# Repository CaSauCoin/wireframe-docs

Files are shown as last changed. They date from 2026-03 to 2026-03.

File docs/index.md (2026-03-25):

---
hide:
  - navigation
  - toc
---

<div class="wf-hero" markdown>

<span class="wf-badge">v1.3.7 — Stable Release</span>

# WireFrame EDA

<p class="wf-subtitle">
A lightweight, keyboard-driven EDA environment for schematic capture, PCB layout,<br>
3D visualization and manufacturing export — all in one desktop application.
</p>

<div class="wf-cta">
  <a href="getting-started/" class="primary">Get Started</a>
  <a href="tutorial/" class="secondary">Try the Tutorial →</a>
</div>

</div>

<!-- TODO: Replace with actual screenshot
     Capture the WireFrame main window immediately after launch. The screenshot should show:
     - _The **dark-themed window** with the menu bar at the top (File, Edit, View, Project, Tools, Help)._
     - _The **Project Structure** panel on the left side (empty or with a sample project open)._
     - _The **central editor area** showing either an empty docking space or a sample schematic/PCB tab._
     - _The **Library panel** on the right side._
     - _The cyan accent color visible on active UI elements._
     - _Window size: approximately 1920×1080 for best readability._
-->
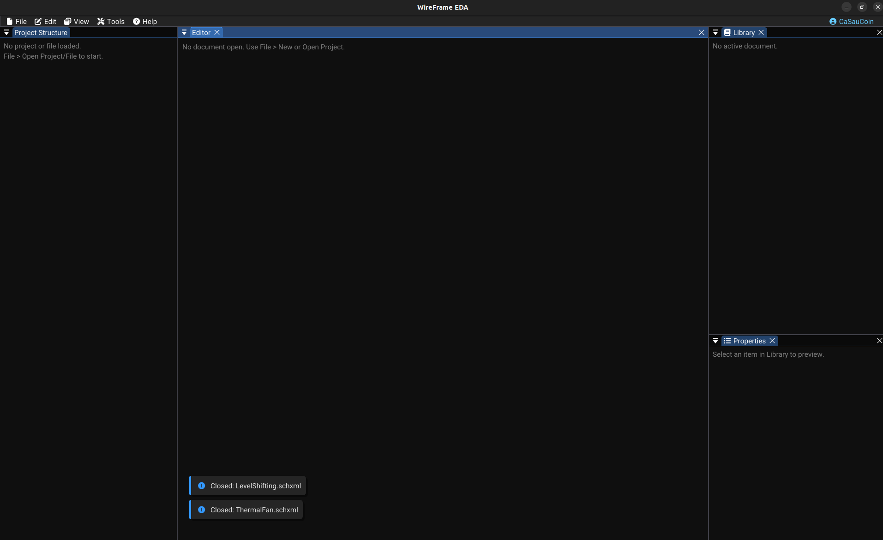
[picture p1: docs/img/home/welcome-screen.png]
Welcome Screen


---

## Key Features

<div class="wf-grid" markdown>

<div class="wf-card" markdown>

### :material-chip: Schematic Editor

Design circuits with a full-featured schematic editor — place symbols from KiCad-compatible libraries, wire nets, add labels and power symbols, and manage multi-sheet designs.

</div>

<div class="wf-card" markdown>

### :material-developer-board: PCB Layout

Route traces with 45° guidance, place vias and zones, manage multi-layer stacks, and run DFM/DRC checks before exporting Gerber files for fabrication.

</div>

<div class="wf-card" markdown>

### :material-library-shelves: Library Management

Load KiCad symbol (`.kicad_sym`) and footprint (`.kicad_mod`) libraries. Link footprints to symbols, generate custom footprints with the built-in wizard.

</div>

<div class="wf-card" markdown>

### :material-rotate-3d: 3D Viewer

Preview your PCB in 3D with imported STEP/OBJ models. Orbit, pan and zoom to verify component placement, clearances and board aesthetics before manufacturing.

</div>

<div class="wf-card" markdown>

### :material-keyboard: Keyboard-Driven

Fully customizable key map for every action — from placing wires to running DRC. Built for speed with an ImGui docking interface that keeps everything one keystroke away.

</div>

<div class="wf-card" markdown>

### :material-export: Fabrication Export

Export production-ready Gerber files, Excellon drill data, BOM spreadsheets and schematic PDFs. Verify outputs instantly with the built-in Gerber viewer.

</div>

<div class="wf-card" markdown>

### :material-swap-horizontal: Import & Compatibility

Import projects from KiCad, Altium Designer, and Eagle. Load symbol and footprint libraries from all major EDA formats — no manual conversion needed.

</div>

</div>

---

## Typical Workflow

```
┌───────────┐   ┌───────────┐   ┌────────────┐   ┌────────────┐   ┌──────────┐
│  Create    │──▶│  Design   │──▶│  Convert   │──▶│  Route &   │──▶│  Export   │
│  Project   │   │  Schematic│   │  to PCB    │   │  Verify    │   │  Gerbers  │
└───────────┘   └───────────┘   └────────────┘   └────────────┘   └──────────┘
```

1. **Create or open a project** — Organize schematics, PCBs and libraries under a single `.prjxml` project file.
2. **Design the schematic** — Place components, wire nets, add power symbols and labels, configure sheet properties.
3. **Convert to PCB** — Generate a PCB document from the schematic with footprints and netlist automatically linked.
4. **Route and verify** — Place footprints, route traces, add zones, then run DFM/DRC checks to catch errors.
5. **Export for fabrication** — Generate Gerber/drill files, export BOM and schematic PDFs, and preview in the Gerber viewer.

---

## Who Is This For?

| Audience | Why WireFrame? |
|---|---|
| **Electronics hobbyists** | Simple, focused tool — no bloated menus. Start designing in minutes. |
| **Students & educators** | Lightweight install, clear workflow from schematic to Gerber. |
| **Professional engineers** | Keyboard-driven speed, KiCad library compatibility, batch export. |
| **Open-source contributors** | C++17 codebase with ImGui — easy to extend and hack on. |

---

## Documentation Map

| Section | What You'll Learn |
|---|---|
| [Getting Started](getting-started.md) | Launch the app, understand the UI, create your first project |
| [Tutorial](tutorial/index.md) | Build a simple LED circuit from scratch in 15 minutes |
| [Schematic Design](schematic/index.md) | Place components, wire nets, manage properties |
| [PCB Layout](pcb/index.md) | Footprints, routing, zones, DRC and fabrication export |
| [Libraries](libraries/symbols-library.md) | Load, create and manage symbols and footprints |
| [Advanced Features](advanced/selection-and-editing.md) | Selection, 3D viewer, keyboard shortcuts |
| [Reference](reference/file-formats.md) | File formats, config, FAQ, changelog |

---

!!! tip "New to WireFrame?"
    Start with the [Getting Started](getting-started.md) guide for a quick orientation, or jump straight into the [Tutorial](tutorial/index.md) to design a simple LED circuit from scratch.

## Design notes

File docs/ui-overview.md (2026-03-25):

# User Interface Overview

This page provides a detailed tour of every part of the WireFrame UI. Understanding the layout will help you work efficiently as you design schematics and PCBs.
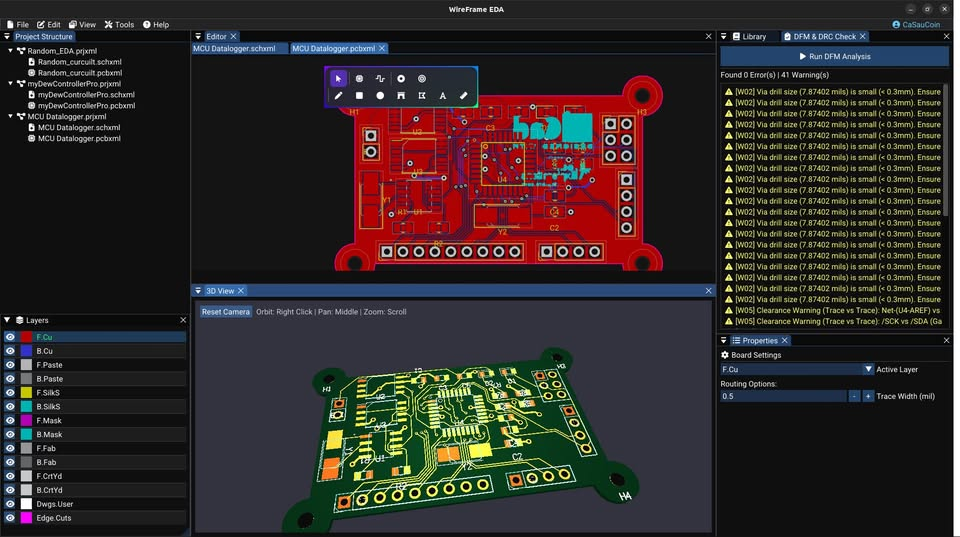
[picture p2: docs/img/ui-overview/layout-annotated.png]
WireFrame UI layout annotated


---

## Menu Bar

Located at the top of the window. Provides access to all major operations:

### File menu

| Action | Shortcut | Description |
|---|---|---|
| New Project… | | Create a new `.prjxml` project |
| Open Project… | | Open an existing project |
| Open… | ++ctrl+o++ | Open a schematic or PCB file |
| New Schematic | ++ctrl+n++ | Create a new schematic document |
| New PCB | | Create a new PCB document |
| Save | ++ctrl+s++ | Save the active document |
| Save As… | ++ctrl+shift+s++ | Save with a new filename |
| Close Project | | Close the active project |
| Export → | | Sub-menu for PDF, Gerber, BOM export |

### Edit menu

| Action | Shortcut | Description |
|---|---|---|
| Undo | ++ctrl+z++ | Undo last action |
| Redo | ++ctrl+y++ | Redo last undone action |
| Cut | ++ctrl+x++ | Cut selected items to clipboard |
| Copy | ++ctrl+c++ | Copy selected items |
| Paste | ++ctrl+v++ | Paste from clipboard |
| Delete | ++delete++ | Delete selected items |

### View menu

| Action | Description |
|---|---|
| Toggle Library | Show/hide the Library panel |
| Toggle Layers | Show/hide the Layer panel (PCB) |
| Toggle Properties | Show/hide the Properties panel |
| 3D Viewer… | Open the 3D PCB viewer |
| Fit to Screen | Zoom to fit all content |

### Tools menu

| Action | Description |
|---|---|
| Symbol Editor | Open the symbol library editor |
| Footprint Wizard | Open the footprint generator |
| Design Rules | Open design rules configuration |
| DFM Check | Run DFM/DRC checks on the active PCB |
| Gerber Viewer | Open the built-in Gerber file viewer |
| Keymap… | Open the keyboard shortcut editor |

### Help menu

| Action | Description |
|---|---|
| About | Show version and license information |
| Check for Updates | Check for newer versions (if enabled) |

---

## Docking Layout

WireFrame uses **docking layout**, giving you full control over panel arrangement:

- **Drag tabs** to move panels between docking zones (left, right, bottom, center).
- **Float panels** by dragging them outside the docking area — they become independent windows.
- **Split zones** by dropping a panel on the edge of an existing zone.
- **Layout persistence**: your arrangement is saved automatically via ImGui configuration and restored on next launch.

Common default panels:

| Panel | Default position |
|---|---|
| Project Structure | Left |
| Editor (canvas) | Center |
| Library | Right (top) |
| Properties | Right (bottom) |
| Layers (PCB only) | Right (middle) |
| Logger / Notifications | Overlay (bottom-right) |

---

## Project Structure Panel

Shows all open projects and their contents in a tree view:

- **Project node** (`.prjxml`) — the root.
    - **Schematics** — lists all `.schxml` files registered in the project.
    - **PCBs** — lists all `.pcbxml` files registered in the project.

### Interactions

| Action | How |
|---|---|
| Open a document | Click a schematic or PCB entry |
| Add new schematic/PCB | Right-click project → Add New… |
| Rename a file | Right-click → Rename |
| Remove from project | Right-click → Remove |
| Delete from disk | Right-click → Delete (with confirmation) |

!!! info "Standalone mode"
    You can open schematic/PCB files without a project. They appear as standalone tabs in the editor but are not linked to a project tree.

<!-- TODO: Replace with actual screenshot
     Capture the Project Structure panel showing:
     - One project ("SampleBoard.prjxml") expanded
     - Under "Schematics": two files (main.schxml, power.schxml)
     - Under "PCBs": one file (SampleBoard.pcbxml)
     - One file highlighted (currently open)
     - A right-click context menu visible (Add New, Remove, Delete)
     Crop to the panel only. 300×500px.
-->
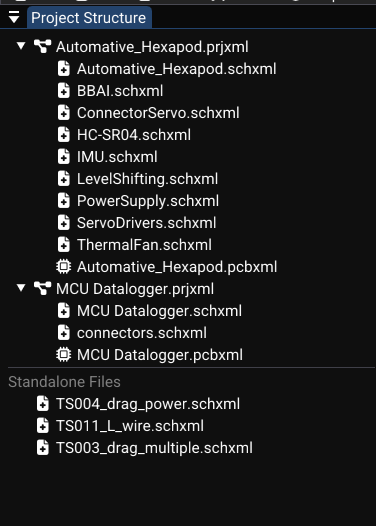
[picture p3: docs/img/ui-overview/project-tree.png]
Project Structure panel


See [Projects & Files](projects.md) for more details.

---

## Editor Panel

The central area where you design. It holds:

- **One tab per open document** (schematic or PCB).
- Tab shows the **filename** (or "Untitled-SCH-N" / "Untitled-PCB-N" for new documents).
- A **dot** or **asterisk** next to the name indicates unsaved changes.
- Right-click a tab to **Close**, **Close Others**, or **Close All**.

### Canvas behavior (common to schematic and PCB)

| Feature | Description |
|---|---|
| Grid | Dot grid for alignment; grid spacing depends on zoom level |
| Pan | Hold middle mouse button and drag |
| Zoom | Mouse scroll wheel, centered on cursor |
| Fit to screen | Press ++f++ (default) to fit all content in view |
| Zoom to selection | Press ++shift+f++ to zoom to selected items |

### Schematic canvas

Displays a page outline (A4/A3/custom), title block border, and all placed components, wires and graphics.

### PCB canvas

Displays the board area, placed footprints, traces, vias, zones and ratsnest lines.

---

## Library Panel

Context-sensitive — content changes based on the active document type:

### When a schematic is active

- Shows loaded **symbol libraries** and their symbols.
- **Search filter** at the top for quick lookup (type partial name like `STM32` or `R_`).
- **Double-click** a symbol to start placing it on the schematic canvas.
- **Right-click** for options: Unload Library, Reload, Link Footprint.

<!-- TODO: Replace with actual screenshot
     Capture the Library panel in schematic context:
     - Search box at the top with "res" typed
     - Filtered list: "R", "R_0402", "R_0603", "R_1206"
     - Status bar: "Ready — 150 symbols"
     - One symbol highlighted
     Crop to panel only. 280×400px.
-->
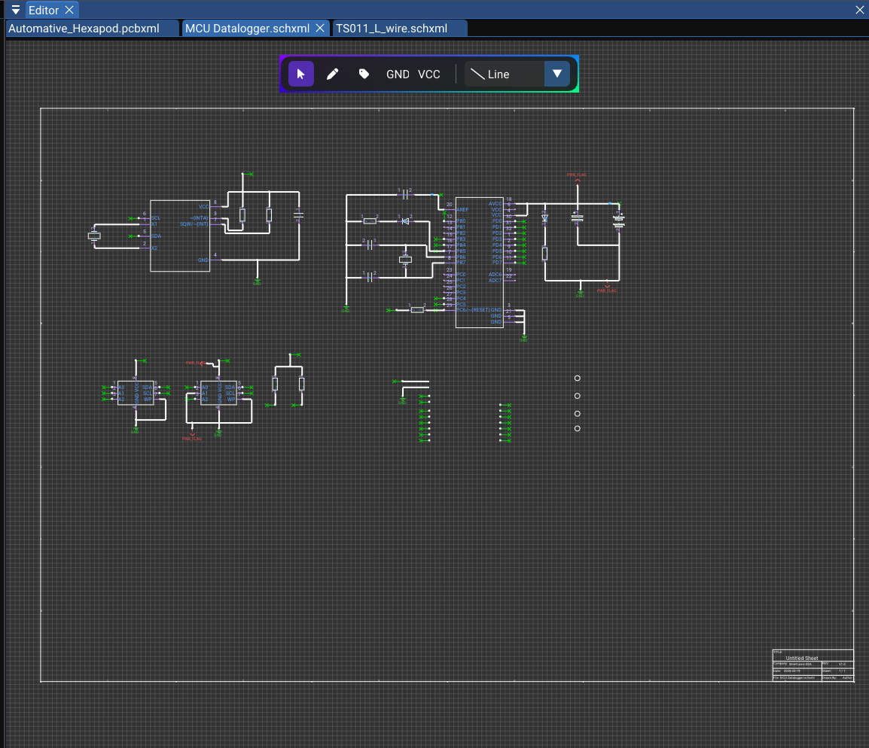
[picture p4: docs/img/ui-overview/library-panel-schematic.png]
Library panel — schematic symbols


### When a PCB is active

- Shows loaded **footprint libraries** and their footprints.
- Same **search filter** functionality.
- **Double-click** to place a footprint on the PCB, or to assign to a selected component.
- **Right-click** for options: Unload, Reload, Open in Footprint Wizard.

<!-- TODO: Replace with actual screenshot
     Same as above but showing footprint names (SOT-23, QFP-48, R_0603_1608Metric).
     PCB editor visible in background. 280×400px.
-->
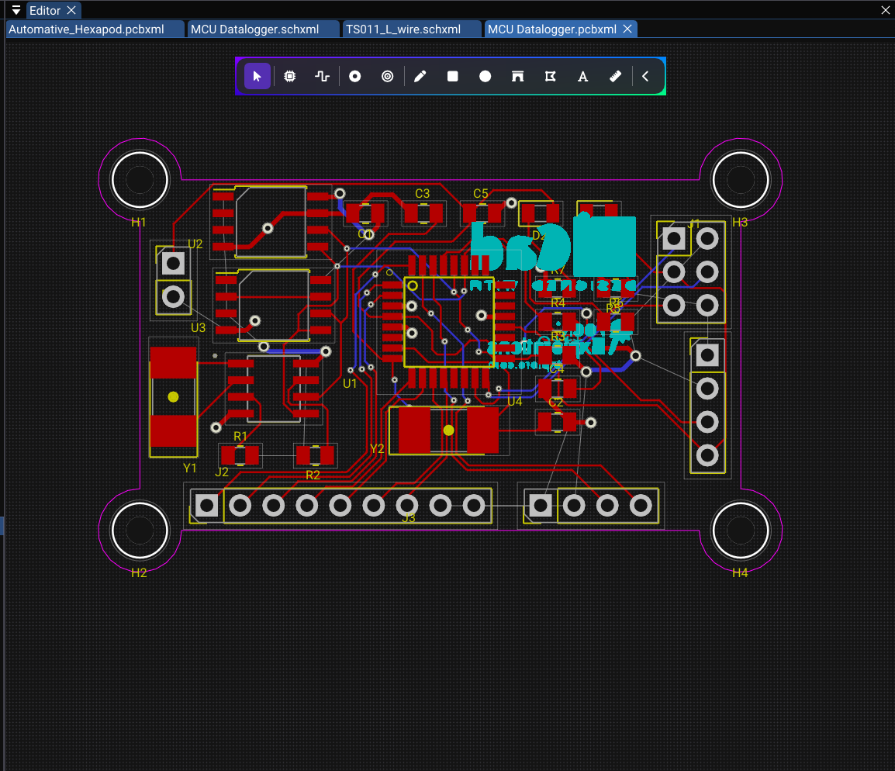
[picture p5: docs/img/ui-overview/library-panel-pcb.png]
Library panel — PCB footprints


---

## Properties Panel

Displays editable information about the current selection and active document:

### Schematic properties

| Selection | Properties shown |
|---|---|
| Single component | Designator, Value, Comment, Footprint, Rotation, Position |
| Net label | Net name, Position, Font size, Visibility |
| Wire | Net name, Connected pins list |
| Graphic object | Position, Size, Color, Layer, Line width |
| No selection | Page settings (paper size, title, company, revision, date) |

### PCB properties

| Selection | Properties shown |
|---|---|
| Footprint | Reference, Value, Layer, Position, Rotation, 3D model |
| Trace | Net name, Layer, Width, Length |
| Via | Net name, Position, Diameter, Drill |
| Pad | Number, Net, Shape, Size, Drill, Layers |
| Zone | Net name, Layer, Priority, Clearance |
| No selection | Board boundary, Design rules summary |

All property edits are applied through the command system and are fully **undoable/redoable**.

<!-- TODO: Replace with actual screenshot
     Properties panel with a resistor selected:
     - Designator: R1, Value: 10kΩ, Comment: empty, Footprint: R_0603_1608Metric
     - Rotation and position fields
     - Text attribute controls (designator visibility, font size)
     - Selected resistor highlighted on schematic canvas in background
     350×500px.
-->
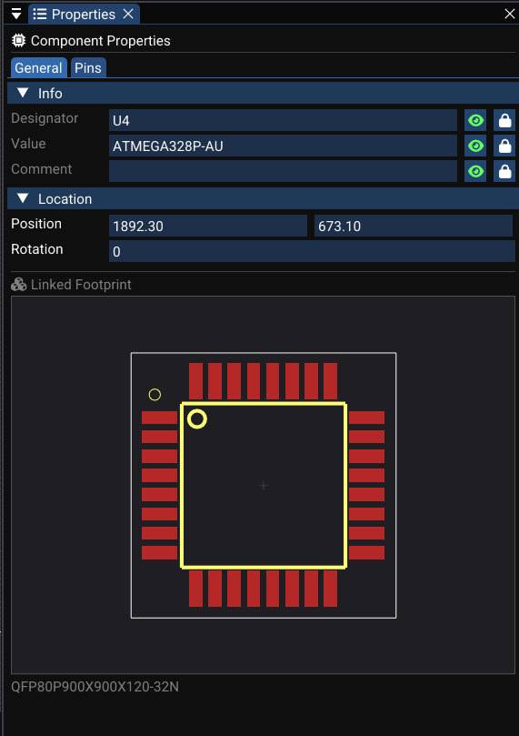
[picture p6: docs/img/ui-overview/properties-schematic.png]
Properties panel — component selected


---

## Toolbars

### Schematic toolbar

A floating toolbar over the schematic canvas (centered at the top):

| Tool | Icon description | Mode |
|---|---|---|
| Select | Arrow cursor | Default selection and move mode |
| Wire | Angled line | Draw orthogonal wires between pins |
| Label | "A" with tag | Place net labels |
| Text | "T" | Place text annotations |
| Line | Diagonal line | Draw straight lines |
| Rectangle | Rectangle outline | Draw rectangles |
| Circle | Circle outline | Draw circles |
| Arc | Curved line | Draw arcs |
| Polygon | Pentagon | Draw polygons (multi-vertex) |
| Junction | Filled dot | Place junction dots |
| Harness | Bundled wires | Draw net harness graphics |
| GND | Ground symbol | Place GND power symbol |
| VCC | Arrow-up symbol | Place VCC power symbol |

The **active tool** is highlighted with a cyan background. Click a different tool button to change modes.

### PCB toolbar

A similar floating toolbar over the PCB canvas:

| Tool | Icon description | Mode |
|---|---|---|
| Select | Arrow cursor | Default selection and move mode |
| Place Footprint | IC package | Place a footprint from library |
| Route Trace | Trace path | Route traces between pads |
| Draw Via | Via circle | Place vias |
| Place Hole | Drill circle | Place mechanical holes |
| Draw Line | Diagonal line | Draw graphic lines |
| Draw Rect | Rectangle | Draw graphic rectangles |
| Draw Circle | Circle | Draw graphic circles |
| Draw Arc | Arc | Draw graphic arcs |
| Draw Polygon | Pentagon | Draw graphic polygons |
| Draw Text | "T" | Place text on silkscreen/fab layers |
| Measure | Ruler | Measure distances on the board |

---

## Layer Panel (PCB Only)

Displayed when a PCB document is active. Shows a table of all board layers:

| Column | Description |
|---|---|
| **Eye icon** | Toggle layer visibility (click to show/hide) |
| **Color patch** | Layer color — click to open color picker |
| **Layer name** | Click to set as the **active routing/drawing layer** |

The currently **active layer** is highlighted (e.g., F.Cu with a cyan indicator).

<!-- TODO: Replace with actual screenshot
     Layer panel showing:
     - F.Cu: eye on, red patch, highlighted as active
     - B.Cu: blue patch, visible
     - F.SilkS, B.SilkS, F.Mask, B.Mask (some hidden/greyed)
     - Edge.Cuts: magenta patch
     - 8–10 layers listed
     250×400px.
-->
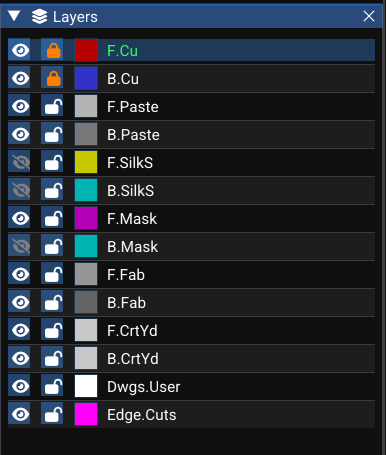
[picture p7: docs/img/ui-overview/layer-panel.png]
Layer panel


---

## Notifications and Logger

The **Logger overlay** displays transient messages at the bottom-right corner of the editor:

| Severity | Icon | Color | Example |
|---|---|---|---|
| Info | :material-information: | Blue | "Project loaded successfully" |
| Success | :material-check-circle: | Green | "File saved: main.schxml" |
| Warning | :material-alert: | Yellow | "Library parsing: 2 symbols skipped" |
| Error | :material-close-circle: | Red | "Failed to save: permission denied" |

Messages auto-fade after a few seconds. They are used for:

- File I/O success or failure.
- Project operations (open, close, create).
- DFM/DRC results summary.
- Library loading progress.

<!-- TODO: Replace with actual video (MP4, 10 seconds, 1280×720 at 30fps)
     1. User saves a file → green toast appears bottom-right
     2. Toast fades after 3–4 seconds
     3. User loads invalid library → yellow warning toast appears
-->

<video controls width="100%">
  <source src="../img/ui-overview/notification-toast.webm" type="video/webm">
  <source src="../img/ui-overview/notification-toast.mp4" type="video/mp4">
  Your browser does not support the video tag.
</video>

---

## See Also

- [Projects & Files](projects.md) — how projects are structured and linked to documents.
- [Schematic Editor](schematic/index.md) — detailed guide to the schematic workspace.
- [PCB Editor](pcb/index.md) — detailed guide to the PCB workspace.
- [Keyboard Shortcuts](advanced/shortcuts.md) — full list of customizable key bindings.

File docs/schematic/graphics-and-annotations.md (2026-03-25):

# Graphics and Annotations

Beyond components and wires, the schematic editor supports drawing primitives, text, and dimension annotations. Use these to document your design, add visual grouping, or include notes.

---

## Drawing Primitives

Available tools from the schematic toolbar:

| Tool | Shortcut | How to draw | Result |
|---|---|---|---|
| **Line** | — | Click start → drag → release | Line object |
| **Rectangle** | — | Click corner → drag to opposite corner | Rectangle object |
| **Circle** | — | Click center → drag to set radius | Circle object |
| **Arc** | — | Click to define arc endpoints and midpoint | Arc object |
| **Polygon** | — | Click vertices → right-click to close | Polygon object |
| **Harness** | — | Click points → right-click to finish | Special polyline style |
| **Junction** | — | Click to place a dot | Manual junction marker |

### Primitive properties

All graphic objects share:

| Property | Description |
|---|---|
| `id` | Unique identifier per object |
| `layerId` | Drawing layer (for multi-layer use; mainly relevant on PCB) |
| Color | Stroke/outline color |
| Line thickness | Stroke width |
| Fill color | Optional fill (rectangles, circles, polygons) |

<!-- TODO: Replace with actual screenshot
     Capture a schematic area with several drawing primitives:
     - _A dashed **rectangle** used as a section border around a group of components, labeled "Power Section"._
     - _A **line** used as a separator between sections._
     - _A **circle** highlighting a test point._
     - _A **polygon** used as a custom shape or arrow._
     - _Different colors and line widths visible across the primitives._
     Suggested size: 700×450px.
-->
<video controls width="100%">
  <source src="../../img/schematic/drawing-primitives.webm" type="video/webm">
  <source src="../../img/schematic/drawing-primitives.mp4" type="video/mp4">
  Your browser does not support the video tag.
</video>

---

## Text Annotations

Text annotation supports free-form text annotations on the schematic:

| Property | Description |
|---|---|
| Position | World coordinates on the canvas |
| Content | The displayed text string |
| Font size | Adjustable text size |
| Color | Text color |

### Creating text

1. Select the **Text** tool from the toolbar (or press ++t++ if configured).
2. Click at the desired location on the canvas.
3. Type the text into a popup field or the Properties panel.
4. The text object is placed and can be selected, moved, and edited later.

!!! tip "Use text for documentation"
    Add notes explaining circuit behavior, voltage levels, or design constraints directly on the schematic sheet. This keeps important information visible alongside the circuit.

---

## Selection and Editing

Graphics are part of the general selection system:

- **Click** to select a single graphic object.
- **Drag** a selection box to select multiple objects.
- Selected graphics show **highlight outlines** and **resize handles**.

### Editing operations

| Operation | How | Command |
|---|---|---|
| **Move** | Drag selected objects | Undo-supported command |
| **Resize** | Drag corner/edge handles | Resize command (geometry update) |
| **Delete** | ++delete++ or context menu | Undo-supported command |
| **Change color** | Properties panel | Direct property edit |
| **Change layer** | Properties panel or context menu | Layer assignment |

!!! info "Resize handles"
    When a graphic is selected, small squares appear at corners and midpoints. Hovering over them changes the cursor to a resize arrow. Drag to change the object's dimensions.

<!-- TODO: Replace with actual screenshot
     Capture a selected rectangle graphic with editing UI visible:
     - _The rectangle highlighted with a cyan selection outline._
     - _**Resize handles** (small squares) at all four corners and midpoints of each edge._
     - _A right-click **context menu** open next to the rectangle showing options: Delete, Change Color, Change Layer, Send to Back._
     - _The Properties panel on the right showing the rectangle's position, width, height, color, and line width._
     Suggested size: 600×400px.
-->

[//]: # (![Graphics Handles]&#40;../img/schematic/graphics-handles.png&#41;)

---

## Dimensions (Experimental)

WireFrame has preliminary support for Dimension annotation objects — measurement annotations:

| Property | Description |
|---|---|
| Start point | First measurement endpoint |
| End point | Second measurement endpoint |
| Offset | Distance of the dimension line from the measured line |
| Text label | Displayed measurement value or custom annotation |

A dimension draws:

- Two witness lines from the measurement points.
- A dimension line with arrows between them.
- A centered text label showing the distance.

!!! note "Experimental feature"
    Dimension tools may not be fully implemented in the current toolbar. They can be created programmatically or may appear in future releases.

---

## Layers for Graphics

While layers are most meaningful on PCB, schematic graphics also carry a `layerId`:

- Colors derive from layer settings if a the layer system is provided.
- Potential future uses:
    - **Documentation overlays** — separate annotations from the circuit.
    - **Printed vs. non-printed layers** — control what appears in PDF exports.

Currently, the main visible effect is **per-layer coloring** applied by the rendering engine.

---

## See Also

- [Placing Components](placing-components.md) — the main schematic elements.
- [Properties & Attributes](properties-and-attributes.md) — edit graphic properties in the Properties panel.
- [PCB Editor — Layers](../pcb/layers-and-views.md) — layers are more critical on the PCB side.

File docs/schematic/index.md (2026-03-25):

# Schematic Editor Overview

The schematic editor is the starting point for circuit design in WireFrame EDA. Use it to place components, draw wires, label nets, and annotate your design before converting to a PCB layout.

---

## What You Can Do

| Task | Tool / Feature |
|---|---|
| Place components from libraries | Library panel + double-click |
| Wire components together | Wire tool |
| Add net labels (SDA, SCL, etc.) | Label tool |
| Add power symbols (GND, VCC) | GND / VCC toolbar buttons |
| Draw annotations and borders | Line, Rectangle, Circle, Arc, Polygon, Text tools |
| Edit component properties | Properties panel |
| Manage nets and connectivity | Automatic netlist builder |

---

## Schematic Workspace

The workspace consists of:

- **Canvas** — dot grid with a page outline (A4 by default). All components, wires, and graphics are placed here.
- **Schematic toolbar** — floating at the top of the canvas with tool buttons.
- **Library panel** — lists loaded symbol libraries for component placement.
- **Properties panel** — edits properties of the selected item or page settings.

<!-- TODO: Replace with actual screenshot
     Capture a mid-complexity schematic showing:
     - _5–8 placed components (resistors, capacitors, an IC, a connector) connected by wires._
     - _Net labels visible on signal lines (e.g., "SDA", "SCL", "RESET")._
     - _GND and VCC symbols connected to power pins._
     - _The schematic floating toolbar visible at the top of the canvas._
     - _The page outline (A4) and title block border visible at the edges._
     - _A few drawing annotations (text note, rectangular border) visible._
     This screenshot gives the reader a realistic impression of a working schematic. Suggested size: 1280×720px.
-->
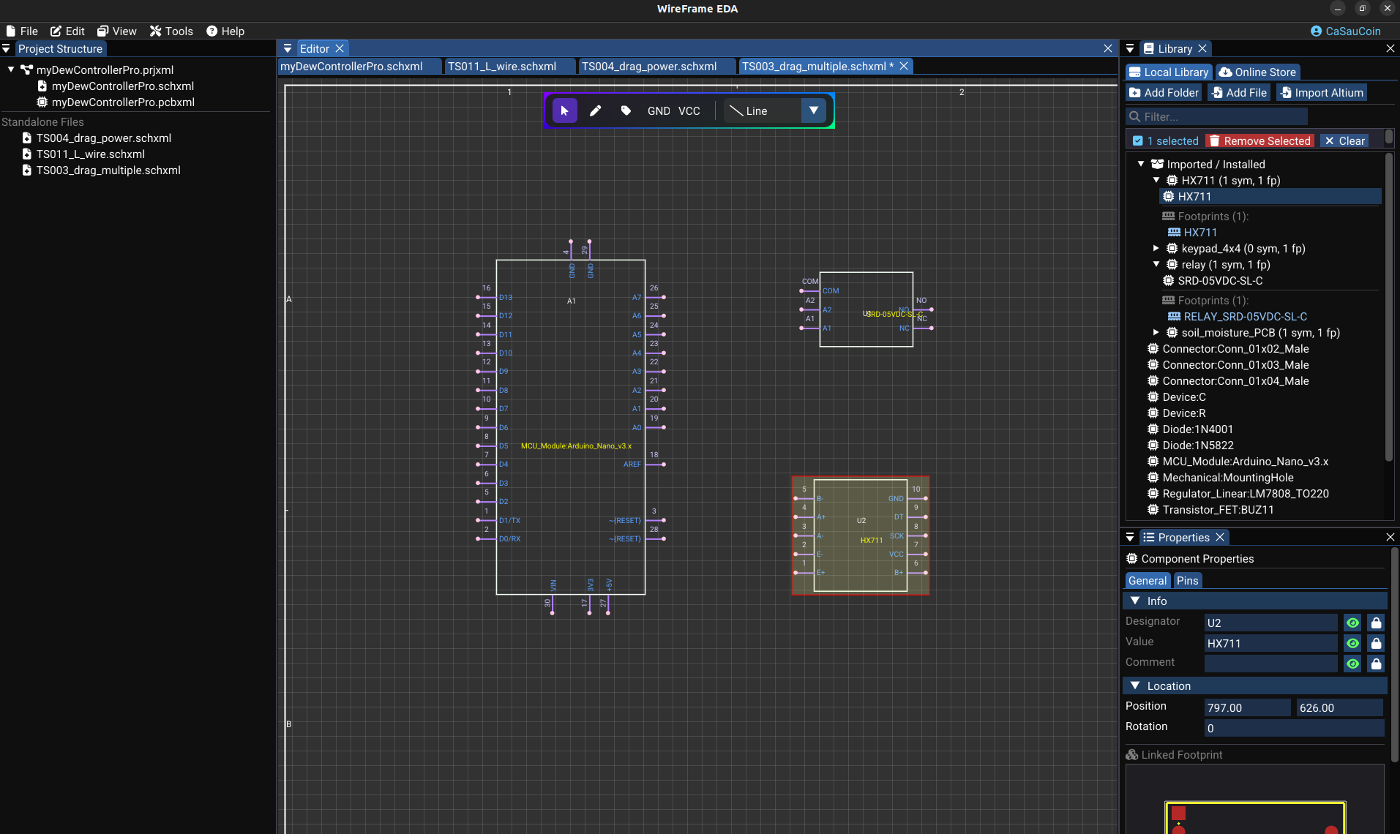
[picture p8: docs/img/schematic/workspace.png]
Workspace


---

## Schematic Toolbar Modes

Each toolbar button activates a **drawing mode**. The current mode determines how mouse events are interpreted:

| Mode | Tool button | Behavior |
|---|---|---|
| `Select` | :material-cursor-default: Arrow | Click to select, drag to move, box-select |
| `Wire` | :material-vector-polyline: Wire | Click pin/canvas → add vertices → end wire |
| `Label` | :material-label: Label | Click to place a net label component |
| `Text` | :material-format-text: Text | Click to place text annotation |
| `Line` | :material-vector-line: Line | Click start → drag → release for a line |
| `Rectangle` | :material-rectangle-outline: Rect | Click corner → drag to opposite corner |
| `Circle` | :material-circle-outline: Circle | Click center → drag to set radius |
| `Arc` | :material-vector-curve: Arc | Click to define arc points |
| `Polygon` | :material-pentagon-outline: Polygon | Click vertices → right-click to finish |
| `Junction` | :material-circle-small: Dot | Click to place junction dots manually |
| `Harness` | :material-transit-connection-variant: Harness | Draw bundled net graphics |
| `PlacingGND` | :material-arrow-down-bold: GND | Click to place a GND power symbol |
| `PlacingVCC` | :material-arrow-up-bold: VCC | Click to place a VCC power symbol |

The **active tool** is highlighted with a cyan background. Press ++esc++ to return to Select mode.

---

## Interaction Model

The schematic interaction is managed by an internal interaction system that operates as a state machine:

### States

| State | Trigger |
|---|---|
| None | Default — waiting for user input |
| MovingSelection | Click+drag on selected items |
| DrawingSelectionBox | Click+drag on empty canvas |
| DrawingWire | Wire tool active, vertices being placed |
| DraggingWireVertex | Dragging a single wire vertex |
| DraggingWireSegment | Dragging a wire segment (adds vertices) |
| MovingAttribute | Dragging a text attribute (designator/value) |
| DrawingPrimitiveShape | Line/Rect/Circle/Arc/Polygon tool active |
| ResizingGraphicObject | Dragging a resize handle on a selected graphic |

### Common interactions

| Action | Input |
|---|---|
| Select a component | Left-click on it |
| Select multiple items | Drag a selection box on empty area |
| Move selected items | Click+drag selected items |
| Open context menu | Right-click on any object |
| Cancel current operation | ++esc++ or right-click |
| Delete selected | ++delete++ or ++backspace++ |
| Undo / Redo | ++ctrl+z++ / ++ctrl+y++ |

<!-- TODO: Replace with actual video
     Record a 30-second screen capture demonstrating:
     1. _Clicking a component to select it (highlight appears)._
     2. _Dragging a selection box over multiple components._
     3. _Moving the selection as a group (wires following)._
     4. _Right-clicking to show a context menu._
     5. _Pressing Undo to reverse the move._
     Resolution: 1280×720 at 30fps. Keep actions slow and deliberate.
-->
<video controls width="100%">
  <source src="../img/schematic/interaction-demo.mp4" type="video/mp4">
  Your browser does not support the video tag.
</video>

---

## Section Pages

Continue to the detailed guides for each aspect of schematic design:

| Page | What you'll learn |
|---|---|
| [Placing Components](placing-components.md) | Load libraries, place symbols, edit designators, rotate and move |
| [Wiring & Nets](wiring-and-nets.md) | Draw wires, connect pins, manage nets and labels |
| [Properties & Attributes](properties-and-attributes.md) | Edit page settings, component attributes, text formatting |
| [Graphics & Annotations](graphics-and-annotations.md) | Draw lines, rectangles, text and other annotations |

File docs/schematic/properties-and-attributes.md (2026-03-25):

# Properties and Text Attributes

This page covers the schematic Properties panel — page settings, component attributes, wire/net properties, and text formatting controls.

---

## Sheet and Page Settings

When **nothing is selected**, the Properties panel shows page-level settings for the active `SchematicDocument`:

| Field | Description | Example |
|---|---|---|
| Paper size | A4, A3, A2, or Custom dimensions | A4 |
| Title | Design title shown in the title block | "Power Supply Rev B" |
| Company | Company or author name | "WireFrame Labs" |
| Revision | Revision identifier | "1.2" |
| Date | Design date | "2026-03-23" |
| Drawn by | Author name | "John Doe" |
| Sheet number | Current sheet number / total sheets | "1 / 3" |
| Filename | Document filename | "power.schxml" |
| Border color | Color of the page border and title block | Cyan / White |

These fields are editable directly in the Properties panel. Changes are reflected immediately on the schematic canvas (title block and page border).

<!-- TODO: Replace with actual screenshot
     Capture the Properties panel showing page settings:
     - _All fields listed above visible in the panel — Title, Company, Revision, Date, Drawn by, Sheet number._
     - _A "Paper Size" dropdown showing "A4" selected._
     - _The schematic canvas visible in the background showing the **title block** in the bottom-right corner of the page, filled with the values from the properties._
     - _Border color picker or color swatch visible._
     Suggested size: 400×500px (panel) or 1280×720px (full window with canvas showing title block).
-->
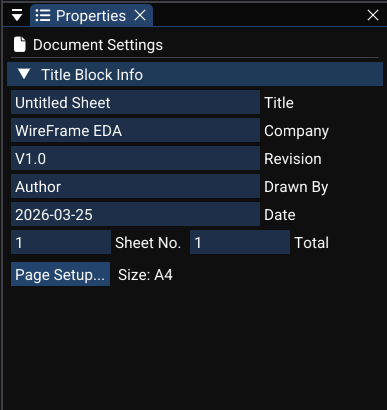
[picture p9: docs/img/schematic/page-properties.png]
Page Properties


---

## Component Attributes

When a **single component** is selected, the Properties panel shows its logical fields and text attributes:

### Logical fields

| Field | Command | Description |
|---|---|---|
| **Designator** (`id`) | an undoable command | Unique component ID (e.g., R1, U3) |
| **Value** | an undoable command | Electrical value (e.g., 10kΩ) |
| **Comment** | an undoable command | Free-text notes |
| **Type** | Read-only | Symbol type from library |
| **Footprint** | Direct edit | PCB footprint name |

### Text attributes

Each component carries visual text attributes that control how text appears on the canvas:

| Attribute | Properties | Description |
|---|---|---|
| `designatorAttribute` | position, rotation, fontSize, isVisible | Controls the "R1" text display |
| `valueAttribute` | position, rotation, fontSize, isVisible | Controls the "10kΩ" text display |
| Pin name attributes | per-pin text rendering | Pin name labels on each pin |
| Pin number attributes | per-pin text rendering | Pin number labels on each pin |

Each text attribute stores:

- `content` — the displayed string.
- `relativePosition` — offset from the component origin.
- `rotation` — angle in degrees.
- `fontSize` — text size.
- `isVisible` — whether the text is drawn.

Editing these uses an undoable command (for content/position/size) and an undoable command (for rotation).

<!-- TODO: Replace with actual screenshot
     Capture a component with its text attributes visible and the Properties panel open:
     - _A resistor selected on the canvas, with "R1" (designator) displayed above and "10kΩ" (value) displayed below._
     - _The Properties panel showing all fields: Designator, Value, Comment, Footprint._
     - _Below the fields: text attribute controls — a "Designator visible" checkbox (checked), a font size slider, a rotation field._
     - _Similar controls for the Value text attribute._
     Suggested size: 800×500px (showing both canvas and panel).
-->
<video controls width="100%">
  <source src="../../img/schematic/component-attributes.mp4" type="video/mp4">
  Your browser does not support the video tag.
</video>

---

## Aligning Attributes

For designs with many components, attribute alignment keeps the schematic clean:

- The selection system tracks attribute references for selected text attributes.
- Alignment functions arrange text uniformly:

| Alignment | Description |
|---|---|
| **Align horizontally** | All selected attribute texts aligned to the same Y coordinate |
| **Align vertically** | All selected attribute texts aligned to the same X coordinate |

From the UI:

- Use context menu commands like **"Align Text Horizontally"** / **"Align Text Vertically"**.
- Or use keyboard shortcuts if configured (see [Shortcuts](../advanced/shortcuts.md)).

<!-- TODO: Replace with actual screenshot
     Capture a group of 4–5 resistors arranged vertically:
     - _**Before alignment**: Designators (R1, R2, R3, R4, R5) at slightly different horizontal positions._
     - _**After alignment**: All designators perfectly aligned in a column, all values aligned in another column._
     - _Show both states side by side or as a before/after comparison._
     Suggested size: 600×350px.
-->

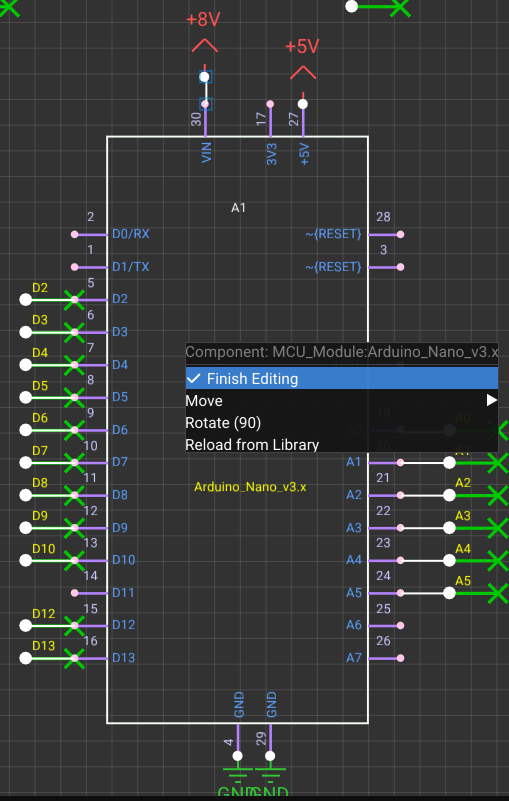
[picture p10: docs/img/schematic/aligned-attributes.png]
Aligned Attributes


---

## Wire and Net Properties

When a **wire or net label** is selected, the Properties panel shows:

| Field | Editable | Description |
|---|---|---|
| Net name | Yes | The net name for this wire/label (an undoable command) |
| Connected pins | Read-only | List of component pins on this net |
| Net classification | Future | Net class assignment for PCB design rules |

Renaming a net label updates:

- The component **value/text** for `NetLabel` components.
- The underlying **net name** in the schematic netlist.
- All other labels and wires on the same net are updated automatically.

---

## Selection-Dependent Content

The Properties panel dynamically switches its content based on what is selected:

| Selection state | Panel content |
|---|---|
| **No selection** | Page/sheet settings (paper size, title block) |
| **Single component** | Component fields + text attributes |
| **Multiple components** | Multi-edit fields (where applicable) or disabled fields |
| **Net label** | Net name editing, position |
| **Wire** | Net name, connected pins list |
| **Graphic object** | Position, size, color, line width, layer |

<!-- TODO: Replace with actual video
     Record a 20-second screen capture showing:
     1. _Click on the schematic background (no selection) — Properties panel shows page settings._
     2. _Click on a resistor — panel switches to show Designator, Value, Comment, Footprint fields._
     3. _Click on a net label — panel switches to show net name field._
     4. _Click on a graphic rectangle — panel switches to show position, size, color, line width._
     5. _Each transition should be clearly visible with the panel content changing smoothly._
     Resolution: 1280×720 at 30fps.
-->
<video controls width="100%">
  <source src="../../img/schematic/properties-switching.webm" type="video/webm">
  <source src="../../img/schematic/properties-switching.mp4" type="video/mp4">
  Your browser does not support the video tag.
</video>

---

## See Also

- [Placing Components](placing-components.md) — place and edit components.
- [Wiring & Nets](wiring-and-nets.md) — manage wires and net names.
- [Graphics & Annotations](graphics-and-annotations.md) — drawing primitives and text.

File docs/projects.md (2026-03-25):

# Projects and Files

WireFrame uses a project-oriented structure to keep schematics, PCBs and libraries organized. This page explains the project file format, document types, and how they link together.

---

## Project Files (`.prjxml`)

A project file (`*.prjxml`) is an XML document that stores:

| Content | Description |
|---|---|
| Schematic list | Paths to all `.schxml` files in the project |
| PCB list | Paths to all `.pcbxml` files in the project |
| Library folder | Default folder for symbol and footprint libraries |
| Library references | Specific library files used by the project |

### Creating a project

1. **File → New Project…**
2. Choose a location and `.prjxml` filename.
3. WireFrame:
    - Creates the project file.
    - Sets the project root directory (parent folder of the `.prjxml`).
    - Creates a default library folder (e.g., `lib/`) if needed.

<!-- TODO: Replace with actual screenshot
     Capture the "New Project" dialog:
     - _A file browser dialog with the filename field showing a sample name (e.g., "MyBoard.prjxml")._
     - _The parent folder visible in the directory path._
     - _The "Create" or "Save" button highlighted._
     Suggested size: 600×400px.
-->
<video controls width="100%">
  <source src="../img/projects/new-project-dialog.mp4" type="video/mp4">
  Your browser does not support the video tag.
</video>

### Opening a project

1. **File → Open Project…**
2. Select a `.prjxml` file.
3. The **Project Structure** panel parses the XML and displays:
    - `<Schematics>` → schematic file entries.
    - `<PCBs>` → PCB file entries.
    - `<Libraries>` → symbol and footprint library references.

<!-- TODO: Replace with actual screenshot
     Capture the Project Structure panel after opening a multi-file project:
     - _Project node expanded ("PowerSupply.prjxml")._
     - _"Schematics" section with 2–3 schematic files listed._
     - _"PCBs" section with 1 PCB file._
     - _File icons distinguishing schematic from PCB documents._
     Crop to the panel only. Suggested size: 300×450px.
-->
Project Tree Expanded

### Adding files to a project

Right-click the project node or a section (Schematics / PCBs) in the Project Structure panel:

- **Add Existing…** — browse for an existing `.schxml` or `.pcbxml` to link into the project.
- **Add New…** — create a new schematic or PCB and automatically register it in the project.

---

## Schematics (`.schxml`)

Each schematic document includes:

| Content | Description |
|---|---|
| Components | Placed symbols with IDs, positions, rotations, and attributes |
| Wires | Wire vertices, pin attachments, and net names |
| Graphics | Lines, rectangles, circles, arcs, polygons, text |
| Page settings | Paper size, title block (title, company, revision, date, author) |

### Key behaviors

- The schematic **netlist** is rebuilt from wires and labels using the netlist engine.
- Components are tied to **symbol definitions** from loaded libraries (via the library system).
- **Cross-document mapping**: schematic component IDs can be linked to PCB footprints by matching IDs.

### Saving

- **File → Save** (++ctrl+s++) — updates the `.schxml` via the save function.
- **File → Save As…** (++ctrl+shift+s++) — writes to a new file and updates the document path.

---

## PCBs (`.pcbxml`)

Each PCB document records:

| Content | Description |
|---|---|
| Footprints | Placed packages with positions, rotations, pads, and layers |
| Traces & vias | Routed connections with net names, widths, and layer assignments |
| Holes | Mechanical and plated holes with diameters |
| Graphics | Board outline, dimensions, silkscreen text and shapes |
| Netlist | Net definitions and pin-to-net assignments |
| Zones | Copper zone outlines and computed fill islands |
| Design rules | Net classes, clearances, trace widths, via/drill sizes |

### Saving

- **File → Save** — calls the save function with all board data (footprints, traces, layers, netlist, drawings, zones, design settings).
- **File → Save As…** — writes to a new file path.

---

## Linking Schematics and PCBs

The typical workflow for linking a schematic to a PCB:

```
┌─────────────┐     ┌──────────────┐     ┌─────────────┐
│  Schematic   │────▶│  Convert to  │────▶│    PCB      │
│  (design)    │     │  PCB action  │     │  (layout)   │
└─────────────┘     └──────────────┘     └─────────────┘
```

1. **Design the schematic** and assign footprints to all components (via symbol properties).
2. Use **Project → Convert to PCB** (or equivalent) to:
    - Create a new PCB document.
    - Populate footprints matching schematic component IDs.
    - Transfer the netlist (net names and pin connections) to the PCB.
3. **Later updates**: changes in the schematic can be re-applied to the PCB by updating netlists. Modified or added nets are marked dirty and the ratsnest is recomputed.

<!-- TODO: Replace with actual video
     Record a 20–30 second screen capture showing:
     1. _A completed schematic with 5–6 components, wires, and labels visible._
     2. _The user clicking "Project → Convert to PCB" from the menu bar._
     3. _A new PCB tab appearing with footprints clustered together and ratsnest lines everywhere._
     4. _The user briefly panning around the new PCB to show all footprints loaded correctly._
     Resolution: 1280×720 at 30fps. Keep actions slow for clarity.
-->
<video controls width="100%">
  <source src="../img/projects/schematic-to-pcb.mp4" type="video/mp4">
  Your browser does not support the video tag.
</video>

!!! warning "Footprint assignment required"
    Components without a Footprint property in the schematic will be skipped during conversion. Always verify that every component has a footprint assigned before converting.

---

## Library Management

Projects can reference external library files for both symbols and footprints:

### Symbol libraries

- Loaded from KiCad `.kicad_sym` files.
- Registered in the project's `<Libraries>` section.
- Symbols are available in the Library panel when a schematic is active.

### Footprint libraries

- Loaded from KiCad `.kicad_mod` files.
- Also registered in the project's `<Libraries>` section.
- Footprints are available when a PCB is active.

### Managing library references

| Action | How |
|---|---|
| Add a library | Load it via the Library panel, then it's auto-registered |
| Remove a library | Right-click in Library panel → Unload |
| View library path | Check the `.prjxml` file's `<Libraries>` section |

!!! tip "Shared libraries"
    You can share a single set of library files across multiple projects by keeping them in a common folder and referencing the same path from each project.

---

## Importing Projects from Other EDA Tools

### Importing a KiCad project

WireFrame can import existing KiCad projects to bring in your schematics, PCB layouts, and library references:

1. Go to **File → Import → KiCad Project…**
2. Select the KiCad project file (`.kicad_pro` or `.pro`).
3. WireFrame reads the project structure and converts:

| KiCad file | Converted to |
|---|---|
| `.kicad_pro` / `.pro` | `.prjxml` (WireFrame project) |
| `.kicad_sch` | `.schxml` (WireFrame schematic) |
| `.kicad_pcb` | `.pcbxml` (WireFrame PCB) |
| `.kicad_sym` | Loaded as symbol library (no conversion needed) |
| `.kicad_mod` | Loaded as footprint library (no conversion needed) |

4. After import, the project appears in the **Project Structure** panel with all linked files.

<!-- TODO: Replace with actual screenshot
     Capture the "Import KiCad Project" dialog:
     - _A file browser showing `.kicad_pro` files._
     - _After import: the Project Structure panel showing the converted project with schematics and PCBs listed._
     Suggested size: 700×450px.
-->

<video controls width="100%">
  <source src="../img/projects/import-kicad.mp4" type="video/mp4">
  Your browser does not support the video tag.
</video>

!!! tip "Library compatibility"
    KiCad symbol (`.kicad_sym`) and footprint (`.kicad_mod`) libraries are natively supported — no conversion is needed. They are loaded directly by WireFrame.

### Importing an Altium project

WireFrame supports importing Altium Designer projects and libraries:

1. Go to **File → Import → Altium Project…**
2. Select the Altium project file (`.PrjPcb`).
3. WireFrame converts the project structure:

| Altium file | Converted to |
|---|---|
| `.PrjPcb` | `.prjxml` (WireFrame project) |
| `.SchDoc` | `.schxml` (WireFrame schematic) |
| `.PcbDoc` | `.pcbxml` (WireFrame PCB) |
| `.SchLib` / `.IntLib` | Symbol library (converted on import) |
| `.PcbLib` | Footprint library (converted on import) |

4. The imported project opens in the Project Structure panel.

<!-- TODO: Replace with actual screenshot
     Capture the "Import Altium Project" dialog:
     - _A file browser showing `.PrjPcb` files._
     - _An import progress dialog or log showing conversion status._
     - _After import: the Project Structure panel showing the converted project._
     Suggested size: 700×450px.
-->

<video controls width="100%">
  <source src="../img/projects/import-altium.mp4" type="video/mp4">
  Your browser does not support the video tag.
</video>

!!! warning "Altium import limitations"
    - Complex Altium features (room definitions, embedded components, advanced design rules) may not be fully converted.
    - Always review the imported design and run DRC after import.
    - Altium 3D model references may need to be re-linked if the model paths differ.

### Importing an Eagle project

WireFrame can also import Eagle (Autodesk) designs:

1. Go to **File → Import → Eagle Project…**
2. Select the Eagle schematic (`.sch`) or board (`.brd`) file.
3. WireFrame converts components, nets, traces, and board geometry.

| Eagle file | Converted to |
|---|---|
| `.sch` | `.schxml` (WireFrame schematic) |
| `.brd` | `.pcbxml` (WireFrame PCB) |
| `.lbr` | Symbol + footprint libraries (converted on import) |

!!! note "Eagle version support"
    Eagle XML format (version 6+) is supported. Binary formats from older Eagle versions are not supported.

---

## Session Restoration

The application stores session data (open projects and documents) in a user config file. On startup, WireFrame automatically:

1. Restores previously open **projects** (`.prjxml`).
2. Restores previously open **documents** (`.schxml` / `.pcbxml`).
3. Re-populates the **Project Structure** panel and **Editor** tabs.

!!! info "Config details"
    Session data is stored in `user_config.json`. See [Config & Session](reference/config-and-session.md) for the file location and format.

---

## See Also

- [Getting Started](getting-started.md) — creating your first project step by step.
- [File Formats](reference/file-formats.md) — XML schema details for `.prjxml`, `.schxml`, `.pcbxml`.
- [Config & Session](reference/config-and-session.md) — session storage and configuration.

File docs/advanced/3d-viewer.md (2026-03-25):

# 3D Viewer

The 3D viewer renders a three-dimensional representation of your PCB board, showing component placement and board geometry. It is powered by the 3D viewer, the 3D renderer, and the 3D camera.

---

## Opening the 3D Viewer

From a PCB document:

1. Use **View → 3D Viewer…** or an equivalent toolbar button.
2. The 3D viewer opens as a **separate ImGui window**.
3. It renders:
    - The **board** as a 3D extruded shape (based on Edge.Cuts outline and board thickness).
    - **Footprints** with 3D models (STEP/OBJ) if available.
    - **Simple colored boxes** for footprints without 3D models.

<!-- TODO: Replace with actual screenshot
     Capture the 3D viewer showing a populated PCB:
     - _The board visible as a semi-transparent green slab (PCB substrate) with the correct outline shape._
     - _Several 3D component models visible: resistors as small rectangular blocks, an IC with visible pins, a connector standing upright._
     - _Components on both sides of the board (if any are flipped to the back)._
     - _The board rotated at an angle (~30° pitch, ~15° yaw) to show depth and perspective._
     - _A dark background with simple lighting (ambient + diffuse)._
     Suggested size: 800×600px.
-->
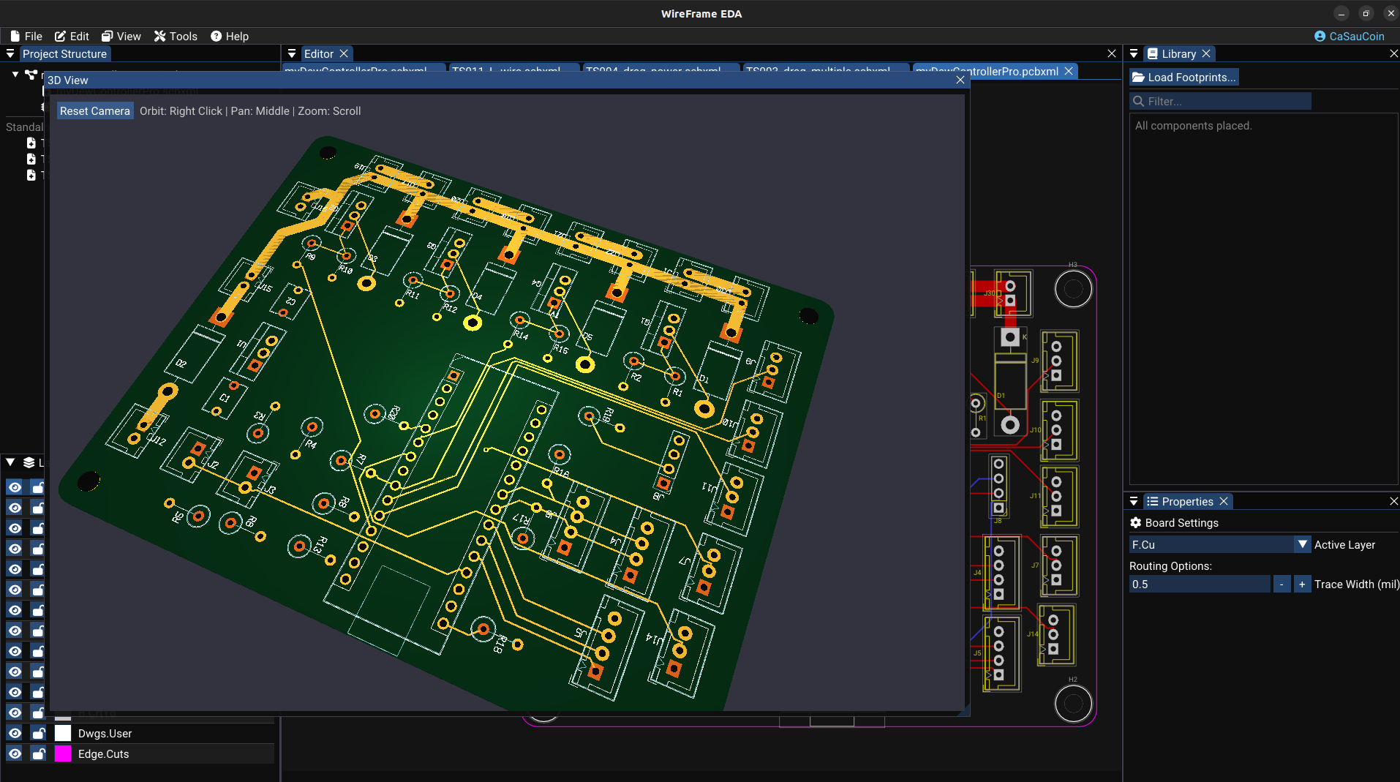
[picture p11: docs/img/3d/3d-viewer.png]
3D Viewer


---

## Camera Controls

the 3D camera manages the 3D view:

| Control | Input | Description |
|---|---|---|
| **Orbit** | Left or right mouse button drag | Rotates the camera around the target point |
| **Pan** | Middle mouse button drag | Moves the target point parallel to the screen |
| **Zoom** | Mouse scroll wheel | Changes distance from the target |

Camera parameters:

| Parameter | Description |
|---|---|
| `target` | The point the camera looks at (center of orbit) |
| `distance` | Distance from camera to target |
| `yaw` | Horizontal rotation angle |
| `pitch` | Vertical rotation angle |

The camera computes view matrices using a standard look-at function with **Z-up** convention.

---

## Board and Component Rendering

The 3D viewer builds the 3D scene:

### Board

- Built from board outline geometry (Edge.Cuts or zones).
- Extruded to `boardThickness` to create a 3D slab.
- Rendered with semi-transparent material (green-ish PCB substrate).

### Components

For each placed footprint:

| Condition | Rendering |
|---|---|
| 3D model exists | Load mesh from STEP (via the STEP importer) or OBJ/STL (via Assimp), apply color based on component type |
| No 3D model | Draw a simple box approximating the footprint boundary, colored by designator prefix |

### Component color by type

| Prefix | Color | Component type |
|---|---|---|
| R | Beige/brown | Resistor |
| C | Yellow | Capacitor |
| U | Dark grey | IC |
| J, P | Light grey | Connector |
| D | Green | Diode |
| Q | Black | Transistor |

### Rendering features

- Simple **Phong-like shading** with ambient + diffuse lighting.
- **Alpha blending** for translucent elements (board substrate).
- **Mesh caching** (the mesh cache) — avoids reloading the same model each frame.

---

## Model Caching

the 3D renderer caches uploaded meshes:

| Feature | Description |
|---|---|
| Cache key | Model file path |
| Cache content | One or more GPU mesh objects (uploaded to GPU) |
| First load | Parse file → tessellate → upload to GPU (may be slow for STEP) |
| Subsequent frames | Reuse cached GPU data (fast) |

clearing the cache frees GPU memory if many different models are used.

!!! tip "Performance"
    First-time loading of STEP files can take several seconds due to mesh tessellation. Subsequent renders use the cached mesh and are fast.

---

## Use Cases

| Use case | How |
|---|---|
| **Visual inspection** | Check component orientations, verify placement density |
| **Mechanical clearance** | Verify that tall components don't interfere with enclosures |
| **Presentation** | Capture screenshots for documentation or client communication |
| **3D alignment** | Use with [Model Alignment Dialog](../libraries/footprints-library.md#3d-model-alignment) to fine-tune model positions |

<!-- TODO: Replace with actual video
     Record a 20-second clip:
     1. _Open the 3D viewer from a PCB document with 8–10 placed footprints._
     2. _The 3D board and components appear._
     3. _Orbit the view (left-click drag) — rotate around the board to show all sides._
     4. _Zoom in (mouse wheel) to a specific component (e.g., an IC) to show detail._
     5. _Pan (middle-click drag) to center a connector at the board edge._
     6. _Zoom out to show the full board._
     Resolution: 1280×720 at 30fps.
-->
<video controls width="100%">
  <source src="../../img/3d/3d-viewer-demo.mp4" type="video/mp4">
  Your browser does not support the video tag.
</video>

---

## See Also

- [Footprint Libraries — 3D Model Alignment](../libraries/footprints-library.md#3d-model-alignment) — position 3D models on footprints.
- [PCB Editor](../pcb/index.md) — the 2D PCB workspace.
- [Fabrication & Export](../pcb/fabrication-and-export.md) — export the board design after 3D verification.

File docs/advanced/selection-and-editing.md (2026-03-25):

# Selection and Editing

Selection and editing operations are unified across schematic and PCB editors via the selection system. This page covers selection basics, moving, context menus, clipboard, and keyboard operations.

---

## Selection Basics

| Action | Input | Result |
|---|---|---|
| Select one item | Left-click on it | Single selection (previous cleared) |
| Add to selection | ++ctrl++"Click"++ | Add item to existing selection |
| Box select | Left-click + drag on empty area | Selects all items whose bounds intersect the box |
| Clear selection | Click on empty area | Deselects everything |

### Selection storage

Items are tracked by type:

| Selection set | Editor | Stored items |
|---|---|---|
| Components | Schematic | Component IDs |
| Wires | Schematic | Wire IDs |
| Graphics | Both | Graphic object IDs |
| Traces | PCB | Trace IDs |
| Vias | PCB | Via IDs |
| Holes | PCB | Hole IDs |

---

## Moving Selection

1. Select one or more items.
2. Click and drag them on the canvas.
3. Items follow the cursor in real time.
4. On mouse release:

| Editor | Command | What's captured |
|---|---|---|
| Schematic | an undoable move command | Component positions + wire geometries |
| PCB | an undoable move command | Footprint, trace, via, and hole positions |

**Undo** (++ctrl+z++) restores all items to their exact previous positions, including wire/trace shapes.

---

## Context Menus

Right-click on any object to open a context-specific menu:

### Schematic context menus

| Object | Available actions |
|---|---|
| Component | Rotate, Edit Properties, Delete |
| Wire | Delete, Change Net, Start Dragging Segment |
| Graphic | Delete, Change Layer, Change Color |
| Net label | Edit Net Name, Delete |
| Empty canvas | Paste (if clipboard has content) |

### PCB context menus

| Object | Available actions |
|---|---|
| Footprint | Rotate, Flip, Unplace, Edit 3D Model, Delete |
| Trace | Delete, Change Net |
| Via | Delete, Edit Properties |
| Graphic | Delete, Change Layer |
| Empty canvas | Paste |

---

## Copy, Cut, Paste

### Schematic clipboard

| Operation | Shortcut | Handler |
|---|---|---|
| Copy | ++ctrl+c++ | Copy handler — stores selected components and wires |
| Cut | ++ctrl+x++ | Copy + Delete |
| Paste | ++ctrl+v++ | Paste handler → a paste command |

During schematic paste:

- New components are created via the paste operation.
- New wires are added via the wire system.
- Component IDs are **remapped** (R1 → R5) to avoid conflicts.
- Wire pin attachments are **remapped** from old to new IDs.

### PCB clipboard

| Operation | Shortcut | Handler |
|---|---|---|
| Copy | ++ctrl+c++ | Copy handler — stores footprints, traces, vias, holes, graphics |
| Cut | ++ctrl+x++ | Copy + Delete |
| Paste | ++ctrl+v++ | Paste handler — places at mouse position with preserved geometry |

During PCB paste:

- Relative positions between items are preserved.
- New IDs are generated for all pasted items.
- The pasted group follows the mouse until you click to place.

<!-- TODO: Replace with actual video
     Record a 15-second clip:
     1. _Select a group of schematic components and wires using box select._
     2. _Press Ctrl+C to copy._
     3. _Click elsewhere on the canvas._
     4. _Press Ctrl+V — a cloned group appears attached to the mouse._
     5. _Click to place the pasted group._
     6. _The new components have different IDs (R3, R4 instead of R1, R2)._
     Resolution: 1280×720 at 30fps.
-->
<video controls width="100%">
  <source src="../../img/advanced/copy-paste-demo.mp4" type="video/mp4">
  Your browser does not support the video tag.
</video>

## Keyboard Operations

| Operation | Shortcut | Description |
|---|---|---|
| Undo | ++ctrl+z++ | Reverts the last command from the command history system |
| Redo | ++ctrl+y++ or ++ctrl+shift+z++ | Re-applies the last undone command |
| Delete | ++delete++ or ++backspace++ | Deletes the current selection |
| Copy | ++ctrl+c++ | Copy selection to clipboard |
| Cut | ++ctrl+x++ | Cut selection |
| Paste | ++ctrl+v++ | Paste from clipboard |
| Rotate | ++r++ | Rotate selected items |
| Flip | ++f++ | Flip selected items (PCB: front/back) |
| Select All | ++ctrl+a++ | Select all items on the canvas |

All operations go through the **Command pattern** — every mutation pushes to the undo stack, enabling full undo/redo history.

See [Keyboard Shortcuts](shortcuts.md) for the complete key binding reference.

---

## See Also

- [Schematic Editor](../schematic/index.md) — schematic-specific interactions.
- [PCB Editor](../pcb/index.md) — PCB-specific interactions.
- [Keyboard Shortcuts](shortcuts.md) — customize all key bindings.

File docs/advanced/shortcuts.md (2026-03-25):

# Keyboard Shortcuts and Key Map

WireFrame uses a fully customizable key map managed by the key map system. Every action can be rebound to your preferred shortcut.

---

## Key Map Editor

Accessible from **Edit → Keymap…** in the main menu:

1. A list of all actions is displayed with:
    - **Action name** (e.g., "Place Wire", "Rotate", "Undo").
    - **Current binding** (e.g., `W`, `R`, `Ctrl+Z`).
2. Click a binding cell to start **recording** a new shortcut.
3. Press the desired key combination (e.g., ++ctrl+r++).
4. The binding updates immediately.
5. Press ++esc++ to cancel recording.

Bindings are stored in memory and can be persisted in future versions via the config file.

<!-- TODO: Replace with actual screenshot
     Capture the Keymap Editor dialog:
     - _A table with two columns: **Action** and **Shortcut**._
     - _10–15 actions visible (e.g., "Place Wire: W", "Rotate: R", "Undo: Ctrl+Z", "Delete: Delete")._
     - _One row in "recording" state — the shortcut cell showing "Press a key…" or highlighted in cyan._
     - _A scrollbar on the right if the list is long._
     Suggested size: 500×400px.
-->
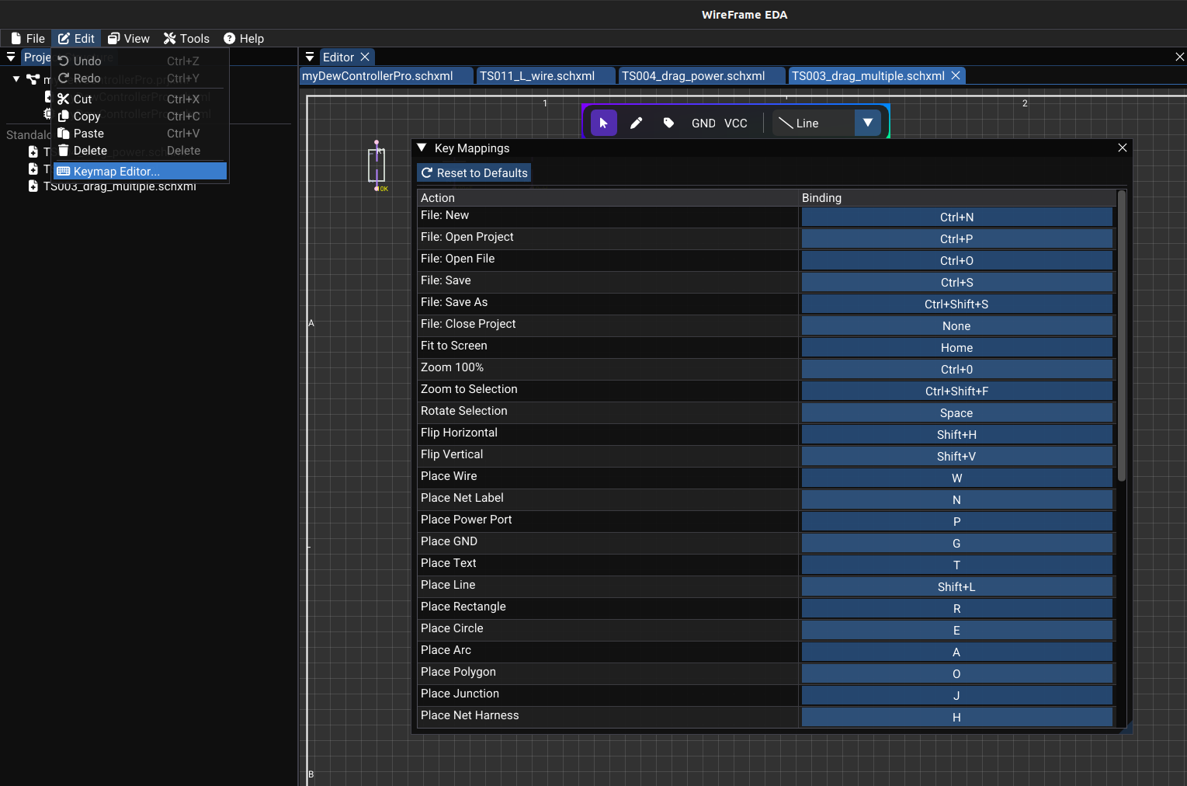
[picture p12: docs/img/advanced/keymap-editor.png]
Keymap Editor


---

## Default Shortcuts — Global

| Action | Default shortcut | Description |
|---|---|---|
| New Schematic / PCB | ++ctrl+n++ | Create a new document |
| Open File | ++ctrl+o++ | Open a file dialog |
| Save | ++ctrl+s++ | Save the active document |
| Save As | ++ctrl+shift+s++ | Save with a new filename |
| Undo | ++ctrl+z++ | Undo last action |
| Redo | ++ctrl+y++ | Redo last undone action |
| Copy | ++ctrl+c++ | Copy selected items |
| Cut | ++ctrl+x++ | Cut selected items |
| Paste | ++ctrl+v++ | Paste from clipboard |
| Delete | ++delete++ | Delete selected items |
| Select All | ++ctrl+a++ | Select all items on canvas |

---

## Default Shortcuts — Navigation

| Action | Default shortcut | Description |
|---|---|---|
| Fit to Screen | ++f++ | Zoom to fit all content |
| Zoom 100% | ++1++ | Reset zoom to 100% |
| Zoom to Selection | ++shift+f++ | Zoom to fit selected items |

---

## Default Shortcuts — Schematic

| Action | Default shortcut | Description |
|---|---|---|
| Place Wire | ++w++ | Activate wire drawing mode |
| Place Net Label | ++l++ | Activate label placement mode |
| Place GND | ++g++ | Place a GND power symbol |
| Place Text | ++t++ | Activate text placement mode |
| Rotate | ++r++ | Rotate selected component(s) |
| End Wire | ++esc++ | End current wire drawing |

---

## Default Shortcuts — PCB

| Action | Default shortcut | Description |
|---|---|---|
| Route Trace | ++x++ | Activate trace routing mode |
| Place Via | ++v++ | Place a via (or switch layer during routing) |
| Move | ++m++ | Move selected items |
| Flip | ++f++ | Flip selected footprint(s) front ↔ back |
| Rotate | ++r++ | Rotate selected items 90° |

---

## Default Shortcuts — Alignment

| Action | Default shortcut | Description |
|---|---|---|
| Align Horizontal | (configurable) | Align selected text attributes horizontally |
| Align Vertical | (configurable) | Align selected text attributes vertically |

---

## Customization Tips

!!! tip "Match your workflow"
    If you're coming from another EDA tool (KiCad, Altium, Eagle), you can rebind WireFrame's shortcuts to match. Open **Edit → Keymap…** and set your preferred bindings.

!!! info "Conflict detection"
    If you assign a shortcut that's already used by another action, the editor will notify you and remove the old binding.

---

## See Also

- [Selection & Editing](selection-and-editing.md) — keyboard operations for selection and clipboard.
- [Schematic Editor](../schematic/index.md) — schematic-specific tool modes.
- [PCB Editor](../pcb/index.md) — PCB-specific tool modes.

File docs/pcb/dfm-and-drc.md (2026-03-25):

# DFM and DRC Checks

The the DFM engine runs Design For Manufacturability (DFM) and Design Rule Check (DRC) analyses on a the PCB document, producing a list of violations to fix before manufacturing.

---

## Running Checks

1. Open the **DFM/DRC panel** from **Tools → DFM Check** or the Design Rules panel.
2. Click **Run DFM**.
3. WireFrame executes all check subroutines.
4. The results panel populates with violations.

### Executed checks

| Check | Function | Description |
|---|---|---|
| Board outline | `checkBoardOutline` | Validates outline geometry |
| Unconnected nets | `checkUnconnectedNets` | Finds nets with remaining ratsnest lines |
| Trace widths | `checkTraceWidths` | Verifies widths against net class minimums |
| Clearances | `checkClearance` | Checks spacing between copper elements |
| Drill sizes | `checkDrillSizes` | Validates via/hole diameters |
| Components | `checkComponents` | Checks for overlaps and out-of-bounds |
| Orphans | `checkOrphans` | Finds unconnected traces/vias |
| Missing components | `checkMissingComponents` | Identifies missing schematic footprints |

---

## Violation Format

Each a DFM violation entry contains:

| Field | Description | Example |
|---|---|---|
| `code` | Short identifier | `E01`, `W02` |
| `message` | Human-readable description | "Trace width below minimum for net class 'Power'" |
| `location` | Board position of the issue | (1200, 800) |
| `isCritical` | Error (true) or warning (false) | `true` |

<!-- TODO: Replace with actual screenshot
     Capture the DFM results panel after running checks:
     - _A list of violations with columns: **Severity** (icon), **Code**, **Message**, **Location**._
     - _2–3 **red error** rows (e.g., "E01: Unconnected net GND", "E03: Clearance violation at (450, 300)")._
     - _1–2 **yellow warning** rows (e.g., "W01: Trace width close to minimum")._
     - _A "Zoom to" button or clickable row for each violation._
     - _A summary line at the bottom: "3 errors, 2 warnings"._
     Suggested size: 600×350px.
-->
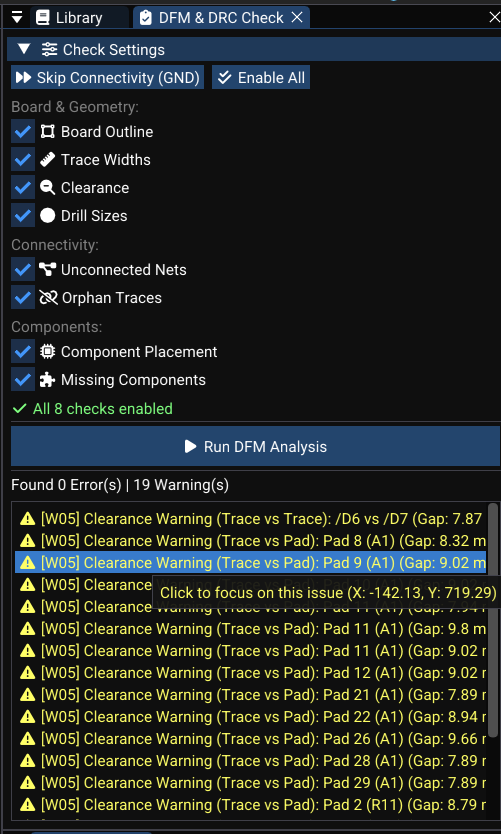
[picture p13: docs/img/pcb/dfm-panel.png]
Dfm Panel


---

## Types of Checks (Detail)

### Board outline

- Ensures the board boundary is **well-formed** (not self-intersecting, not degenerate).
- Warns if **no outline is defined**.
- Flags footprints that **extend outside** the board area.

### Unconnected nets

- Uses the PCB netlist engine connectivity data.
- Reports nets where **ratsnest lines remain** (pins not connected by traces or zones).
- Each unconnected pin pair is listed as a violation.

### Trace widths

- Checks each trace width against its **net class minimum**:

| Net class | Min width | Example nets |
|---|---|---|
| Default | 6 mil | Signal nets |
| Power | 12 mil | VCC, GND |

- Flags traces below their class minimum.

### Clearances

- Computes distances between copper elements:

| Pair | Check |
|---|---|
| Trace ↔ Trace | Segment distance ≥ clearance |
| Trace ↔ Pad | Segment-to-circle/rect distance ≥ clearance |
| Pad ↔ Pad | Center distance minus radii ≥ clearance |
| Copper ↔ Board edge | Distance from outline ≥ edge clearance |

### Drill sizes

- Checks via and hole diameters against the **minimum allowed drill size**.
- Flags too-small drills that may be impossible to manufacture.

### Components

- Checks for **overlapping footprint bounding boxes** (potential physical collisions).
- Verifies all footprints are **inside the board boundary**.

### Orphans and missing components

- **Orphan traces/vias**: copper not connected to any pad or net.
- **Missing footprints**: components in the schematic netlist without corresponding placed footprints on the PCB.

---

## Viewing and Fixing Violations

### Navigating violations

1. **Double-click** a violation in the list — the view pans and zooms to the `location`.
2. The problematic area is centered on screen.
3. Fix the issue (reroute a trace, increase clearance, place a missing component, etc.).
4. **Re-run DFM** to verify the fix.

### Severity icons

| Severity | Icon | Meaning |
|---|---|---|
| **Error** (critical) | :material-close-circle:{ style="color: red" } | Must be fixed before fabrication |
| **Warning** | :material-alert:{ style="color: orange" } | Should be reviewed but may be acceptable |

<!-- TODO: Replace with actual video
     Record a 20-second clip:
     1. _Click "Run DFM" — the panel fills with 3–4 violations._
     2. _Double-click a clearance error — the view zooms to the tight area._
     3. _Drag the offending trace to increase clearance._
     4. _Click "Run DFM" again — the error count drops by one._
     5. _Repeat for another violation._
     Resolution: 1280×720 at 30fps.
-->
<video controls width="100%">
  <source src="../../img/pcb/dfm-fix-cycle.webm" type="video/webm">
  <source src="../../img/pcb/dfm-fix-cycle.mp4" type="video/mp4">
  Your browser does not support the video tag.
</video>

!!! warning "Export readiness"
    Do not export Gerber files until all **critical errors** (red) are resolved. Warnings should be reviewed but typically don't block production.

---

## See Also

- [Routing](routing.md) — fix trace-related violations by rerouting.
- [Zones & Planes](zones-and-planes.md) — zone connectivity affects unconnected-net checks.
- [Fabrication & Export](fabrication-and-export.md) — export only after DRC passes.

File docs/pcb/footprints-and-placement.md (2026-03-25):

# Footprints and Placement

Footprints are the physical packages placed on the PCB, managed by the footprint system. This page covers loading libraries, placing, moving, rotating, flipping, and managing footprints.

---

## Loading Footprint Libraries

From the **Library panel** while a PCB document is active:

1. Click **Load Footprints…**
2. Select one or more KiCad footprint library files (`.kicad_mod`).
3. WireFrame parses footprint data via the KiCad footprint parser in the background.
4. Parsed footprint names appear in the list and can be filtered.

### Footprint data

Each loaded footprint contains:

| Data | Description |
|---|---|
| Pads | Number, position, shape (circle/rect/oval/roundrect), drill, layers |
| Graphics | Lines, arcs, circles, polygons, reference and value text |
| 3D model | Optional file path (STEP/OBJ) with offset, scale, rotation |
| Tags | Description and search tags for filtering |

<!-- TODO: Replace with actual screenshot
     Capture the Library panel in PCB mode:
     - _Search box at the top with a partial filter typed (e.g., "SOT")._
     - _A filtered list showing footprint names: "SOT-23", "SOT-23-5", "SOT-23-6"._
     - _Status bar showing "Ready — 85 footprints loaded"._
     - _If a preview area exists, show a small rendering of the selected footprint._
     Suggested size: 300×450px.
-->
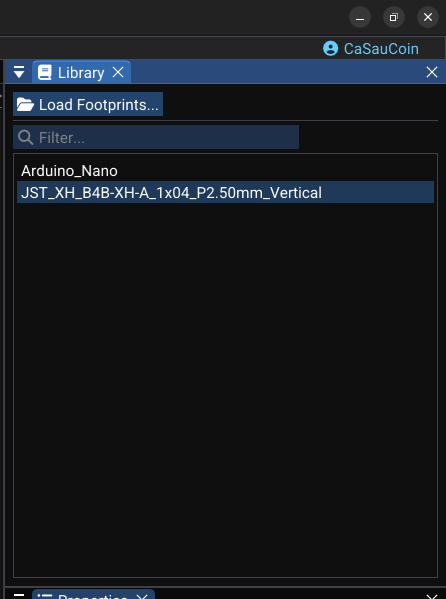
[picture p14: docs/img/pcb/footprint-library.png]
Footprint Library


---

## Placing Footprints

### From the schematic conversion (available footprints)

After converting a schematic to PCB, the PCB document maintains an **available footprints** list — components waiting to be placed:

1. Open a dialog listing unplaced schematic components and their footprints.
2. Select an item from the list.
3. Click on the board to place it.
4. The footprint appears with its `id` matching the schematic component (e.g., `U1`, `R3`).

### Direct placement from library

1. In the **Library panel**, double-click a footprint name.
2. The PCB enters **placement mode** — the footprint preview follows the mouse.
3. **Left-click** to place the footprint at the desired board location.

| Action | Input |
|---|---|
| Place footprint | Left-click |
| Rotate before placing | ++r++ |
| Cancel placement | Right-click or ++esc++ |

<!-- TODO: Replace with actual video
     Record a 15-second clip:
     1. _Double-click a footprint in the Library panel (e.g., "QFP-48")._
     2. _The footprint preview appears attached to the mouse cursor._
     3. _Press R to rotate it 90° — the preview rotates._
     4. _Click to place it on the board._
     5. _The footprint settles at the position with its pads and reference visible._
     Resolution: 1280×720 at 30fps.
-->
<video controls width="100%">
  <source src="../../img/pcb/placing-footprint.webm" type="video/webm">
  <source src="../../img/pcb/placing-footprint.mp4" type="video/mp4">
  Your browser does not support the video tag.
</video>

---

## Moving and Rotating Footprints

### Moving

1. **Select** one or more footprints.
2. **Click and drag** to move them on the board.
3. Connected traces and vias update their endpoints to stay attached.

an undoable move command captures:

- Old and new positions of all moved items (footprints, traces, vias, holes).
- Fully undoable — ++ctrl+z++ restores everything.

### Rotating

| Action | Input | Command |
|---|---|---|
| Rotate 90° | ++r++ or context menu | an undoable rotation command |

Rotation:

- Updates footprint angle.
- Recomputes all pad positions.
- Updates connected trace endpoints to match new pad locations.

<!-- TODO: Replace with actual video
     Record a 10-second clip:
     1. _Select 2–3 footprints with connected traces._
     2. _Press R — all selected footprints rotate 90° together._
     3. _Connected traces adjust their endpoints to maintain pad connections._
     4. _Undo to restore original orientation._
     Resolution: 1280×720 at 30fps.
-->

[//]: # (<video controls width="100%">)

[//]: # (  <source src="../../img/pcb/rotate-footprints.webm" type="video/webm">)

[//]: # (  <source src="../../img/pcb/rotate-footprints.mp4" type="video/mp4">)

[//]: # (  Your browser does not support the video tag.)

[//]: # (</video>)

---

## Flipping Footprints (Front ↔ Back)

To move a component to the opposite side of the board:

1. Select one or more footprints.
2. Press ++f++ or use **context menu → Flip**.
3. an undoable flip command toggles the board side:
    - Footprint layer changes (F.Cu ↔ B.Cu, F.SilkS ↔ B.SilkS, etc.).
    - Vias, holes, and graphics are also flipped if selected.
    - Executing the command again (undo) flips them back.

!!! info "Visual feedback"
    Flipped footprints change their appearance — the reference text may mirror and the layer color changes (e.g., red → blue for F.Cu → B.Cu).

---

## Editing Footprint Designators

Each a placed footprint has a designator text:

| Feature | Description |
|---|---|
| Designator text | Visible reference on the board (e.g., "R1", "U3") |
| Position | Can be dragged independently from the footprint body |
| Rotation | Can be rotated separately |
| Hit testing | Click on the text to select it specifically |

<!-- TODO: Replace with actual screenshot
     Capture a footprint with its designator being edited:
     - _A resistor footprint with its reference text "R1" selected and highlighted._
     - _The text being dragged slightly away from the pad area to avoid overlap with traces._
     - _The Properties panel showing the designator's position offset and font size._
     Suggested size: 500×350px.
-->
Designator Editing

---

## Unplacing and Deleting Footprints

| Action | Command | Behavior |
|---|---|---|
| **Unplace** | Unplace command | Removes from board, returns to "available" list. Can be re-placed later. |
| **Delete** | Delete command / Delete command | Permanently removes footprint (and selected traces). Undoable. |

!!! tip "Unplace vs. Delete"
    Use **Unplace** when you want the component to remain in the schematic and be placed again later. Use **Delete** when removing it from the PCB entirely.

---

## See Also

- [Routing](routing.md) — route traces between placed footprints.
- [Footprint Libraries](../libraries/footprints-library.md) — creating and managing footprint libraries.
- [3D Viewer](../advanced/3d-viewer.md) — preview footprints with 3D models.

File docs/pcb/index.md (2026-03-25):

# PCB Editor Overview

The PCB editor handles board layout — from component placement to trace routing, copper zones, design rule checks, and manufacturing file export.

---

## What You Can Do

| Task | Tool / Feature |
|---|---|
| Place footprints from libraries or schematic | Library panel / Available Footprints dialog |
| Route traces between pads | Route Trace tool with 45° guidance |
| Place vias and change routing layers | Via tool / ++v++ during routing |
| Add mechanical holes | Place Hole tool |
| Define the board outline | Edge.Cuts layer + drawing tools |
| Fill copper zones (ground planes) | Zone Manager / Fill GND Plane |
| Run DFM/DRC checks | DFM panel |
| Export Gerber, drill, BOM | Fabrication dialog |
| Preview the board in 3D | 3D Viewer |

---

## PCB Workspace

The workspace consists of:

- **Canvas** — the board area with grid, showing footprints, traces, zones, and ratsnest lines.
- **PCB toolbar** — floating at the top of the canvas.
- **Layer panel** — toggle visibility and select the active routing layer.
- **Library panel** — lists loaded footprint libraries.
- **Properties panel** — edits properties of the selected PCB item.

<!-- TODO: Replace with actual screenshot
     Capture a PCB board at a mid-design stage:
     - _8–12 footprints placed on the board (mix of SMD and through-hole)._
     - _Several routed traces visible in red (F.Cu) and blue (B.Cu) colors._
     - _A few remaining **ratsnest lines** (thin, dashed) showing unrouted connections._
     - _A **copper zone** (GND) fill visible on one layer with clearance gaps around pads._
     - _The **board outline** visible in magenta (Edge.Cuts)._
     - _The PCB toolbar at the top with the Select tool active._
     - _Layer panel on the right showing F.Cu highlighted._
     Suggested size: 1280×720px.
-->
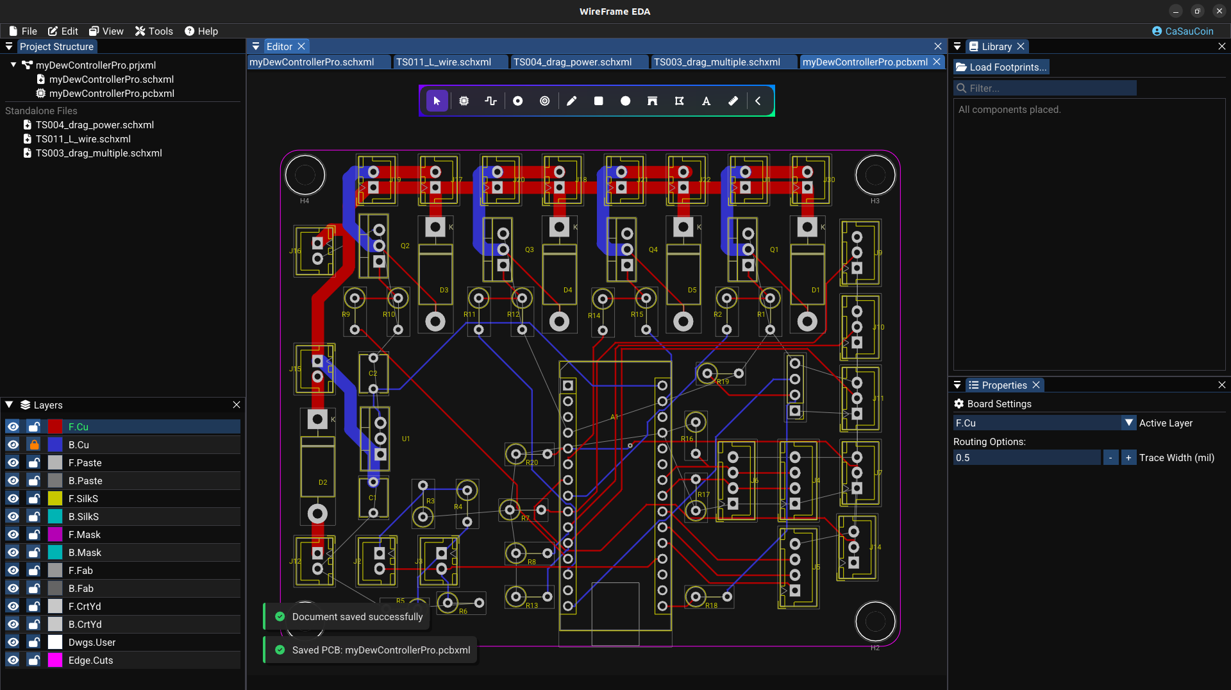
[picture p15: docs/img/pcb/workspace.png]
Workspace


---

## PCB Toolbar Tools

| Tool | Icon | Mode | Shortcut |
|---|---|---|---|
| **Select** | Arrow | Default selection and move | ++esc++ |
| **Place Footprint** | IC package | Place from library or available list | — |
| **Route Trace** | Trace path | Route traces between pads | ++x++ |
| **Draw Via** | Via circle | Place vias manually | ++v++ |
| **Place Hole** | Drill circle | Place mechanical holes | — |
| **Draw Line** | Line | Draw graphic lines | — |
| **Draw Rect** | Rectangle | Draw rectangles (board outline, etc.) | — |
| **Draw Circle** | Circle | Draw circles | — |
| **Draw Arc** | Arc | Draw arcs | — |
| **Draw Polygon** | Pentagon | Draw polygons | — |
| **Draw Text** | "T" | Place text on silk/fab layers | — |
| **Measure** | Ruler | Measure distances between points | — |

---

## Board Boundary

Each the PCB document includes a board boundary:

- Defined by a board boundary definition (simple rectangular min/max) or by **Edge.Cuts** drawing objects (rectangles/polygons).
- Used for:
    - DFM checks (footprints inside board area).
    - Zone fill clipping.
    - Gerber export (board outline layer).

!!! tip "Defining the board outline"
    Switch to the **Edge.Cuts** layer and use the Rectangle or Polygon drawing tool. This creates the physical board shape that manufacturers will cut.

---

## Nets and Ratsnests

WireFrame manages electrical connectivity:

| Concept | Description |
|---|---|
| **PcbNet** | A named net with a set of pin references (footprint ID + pad number) |
| **Pad-to-net map** | Maps each pad to its net name |
| **Connectivity graph** | Includes traces, vias, and zones |
| **Ratsnest lines** | Thin lines drawn between unconnected endpoints of the same net |

Ratsnest lines:

- Are **rebuilt automatically** when nets are marked dirty (after edits).
- **Disappear** as you route traces to complete connections.

<!-- TODO: Replace with actual video
     Record a 15-second clip:
     1. _A PCB with several unrouted ratsnest lines visible._
     2. _Route one trace from pad to pad — the ratsnest line between them disappears._
     3. _Route another trace — another line vanishes._
     4. _Briefly zoom out to show the remaining ratsnest lines._
     Resolution: 1280×720 at 30fps.
-->

[//]: # (<video controls width="100%">)

[//]: # (  <source src="../../img/pcb/ratsnest-demo.webm" type="video/webm">)

[//]: # (  <source src="../../img/pcb/ratsnest-demo.mp4" type="video/mp4">)

[//]: # (  Your browser does not support the video tag.)

[//]: # (</video>)

---

## Section Pages

| Page | What you'll learn |
|---|---|
| [Footprints & Placement](footprints-and-placement.md) | Load libraries, place and arrange footprints |
| [Routing](routing.md) | Route traces, manage vias and holes |
| [Layers & Views](layers-and-views.md) | Layer management, visibility, navigation |
| [Zones & Planes](zones-and-planes.md) | Copper fills, ground planes, zone priorities |
| [DFM & DRC](dfm-and-drc.md) | Design rule and manufacturability checks |
| [Fabrication & Export](fabrication-and-export.md) | Gerber, drill, BOM, PDF export |

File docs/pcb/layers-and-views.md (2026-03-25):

T# Layers and Views

ooPCB layers control visibility, color, and rendering of board elements. This page covers layer definitions, the Layer panel, rendering behavior, and view controls.

---

## Layer Definitions

WireFrame defines the board layer stack. Each layer has:

| Property | Description |
|---|---|
| ID | Layer identifier (e.g., F.Cu) |
| `name` | Display name (e.g., "F.Cu", "B.SilkS") |
| `type` | Layer type: Signal, Silk, Mask, Paste, Fab, Edge, User |
| `color` | Rendering color (editable) |
| `isVisible` | Whether the layer is drawn on the canvas |

### Default layer stack

| Layer | Type | Typical color | Purpose |
|---|---|---|---|
| **F.Cu** | Signal | Red | Front copper (traces, pads) |
| **B.Cu** | Signal | Blue | Back copper |
| **F.SilkS** | Silk | Yellow | Front silkscreen (labels, outlines) |
| **B.SilkS** | Silk | Magenta | Back silkscreen |
| **F.Mask** | Mask | Purple | Front solder mask openings |
| **B.Mask** | Mask | Green | Back solder mask openings |
| **F.Paste** | Paste | Light red | Front solder paste |
| **B.Paste** | Paste | Light blue | Back solder paste |
| **F.Fab** | Fab | Grey | Front fabrication layer |
| **B.Fab** | Fab | Grey | Back fabrication layer |
| **F.CrtYd** | Courtyard | Light grey | Front courtyard (clearance areas) |
| **B.CrtYd** | Courtyard | Light grey | Back courtyard |
| **Edge.Cuts** | Edge | Magenta | Board outline / physical shape |
| **Dwgs.User** | User | Grey | User drawing annotations |

---

## Layer Panel (UI)

Open via **View → Toggle Layers** or from the sidebar. The panel shows a table:

| Column | Interaction |
|---|---|
| **Eye icon** | Click to toggle layer visibility (hidden layers are not rendered) |
| **Color patch** | Click to open a color picker and customize the layer color |
| **Layer name** | Click to set this layer as the **active routing/drawing layer** |

The **active layer** is highlighted with a distinct background (e.g., brighter or with a cyan indicator).

<!-- TODO: Replace with actual screenshot
     Capture the Layer panel:
     - _F.Cu shown first: eye icon enabled (visible), red color patch, **highlighted as the active layer** (brighter background or cyan indicator)._
     - _B.Cu: blue color patch, visible, not active._
     - _F.SilkS: yellow patch, visible._
     - _B.SilkS, F.Mask, B.Mask: some with eye icons toggled off (greyed out text)._
     - _Edge.Cuts: magenta patch, visible._
     - _At least 10 layers visible in the list._
     - _If a color picker is open (for one layer), show it as well._
     Suggested size: 280×500px.
-->
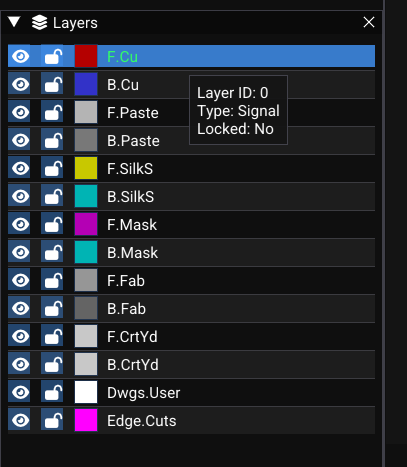
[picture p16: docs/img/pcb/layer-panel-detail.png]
Layer Panel Detail


---

## Layer Colors and Rendering

Rendering uses layer colors throughout:

| Element | Color source |
|---|---|
| Traces | Color of the trace's assigned layer |
| Footprint graphics | Color from the layer system based on each graphic's layer |
| Pads | Typically follows copper layer color |
| Silkscreen | F.SilkS / B.SilkS layer color (default: yellow / magenta) |
| Board outline | Edge.Cuts layer color (default: magenta) |
| Zones | Semi-transparent fill using the zone's layer color |

### Hidden layers

- When a layer is hidden (eye icon off), its traces, graphics, and pads are **not drawn**.
- Underlying data still exists — you can still select and edit hidden-layer items if you know they're there.

---

## View Controls

### Navigation

| Action | Input |
|---|---|
| Pan | Middle mouse button drag |
| Zoom | Mouse scroll wheel (centered on cursor) |
| Fit to board | ++f++ (default) or **View → Fit to Screen** |
| Zoom to selection | ++shift+f++ |
| Zoom 100% | ++1++ |

<!-- TODO: Replace with actual video
     Record a 15-second clip:
     1. _A PCB with both F.Cu and B.Cu traces visible (red and blue)._
     2. _Click the eye icon for B.Cu — all back-side traces and blue pads disappear._
     3. _Click the eye icon for F.SilkS — silkscreen labels disappear._
     4. _Re-enable both layers — everything reappears._
     5. _Use the mouse wheel to zoom in on a dense area._
     Resolution: 1280×720 at 30fps.
-->
<video controls width="100%">
  <source src="../../img/pcb/layer-visibility.mp4" type="video/mp4">
  Your browser does not support the video tag.
</video>

---

## See Also

- [PCB Editor Overview](index.md) — general PCB workspace description.
- [Routing](routing.md) — the active layer determines which copper layer traces are routed on.
- [Fabrication & Export](fabrication-and-export.md) — layer selection for Gerber export.

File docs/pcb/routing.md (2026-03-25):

# Routing Traces

Trace routing connects pads on the PCB, enforcing electrical and design-rule constraints. This page covers the routing workflow, collision detection, trace editing, vias, holes, and routing helpers.

---

## Routing Mode

Select **Route Trace** from the PCB toolbar (or press ++x++).

### Drawing a trace

1. **Click on a pad** or existing trace segment to start routing.
2. The trace follows the mouse with **45° helper points** automatically computed.
3. **Left-click** to confirm each vertex (corner).
4. **Click on the destination pad** to finish the trace, or **right-click** / press ++esc++ to end.

| Action | Input |
|---|---|
| Start trace on a pad | Left-click |
| Add vertex | Left-click |
| Finish trace on pad | Left-click on target |
| Cancel current trace | Right-click or ++esc++ |
| Switch layer (place via) | ++v++ |

### Trace data

Each trace stores:

| Property | Description | Example |
|---|---|---|
| `id` | Unique trace identifier | `trace_42` |
| `netName` | Electrical net this trace belongs to | `GND`, `SDA` |
| `layer` | Copper layer ID | `F.Cu`, `B.Cu` |
| `width` | Trace width in board units (mils) | `10` |
| `points` | Ordered polyline vertices | World coordinates |

<!-- TODO: Replace with actual video
     Record a 20-second clip:
     1. _Press X to activate the Route Trace tool._
     2. _Click on a pad of U1 — the net name highlights and a trace starts._
     3. _Move the mouse — a 45° guided path is shown._
     4. _Click to add a vertex (corner)._
     5. _Click on the destination pad of R1 — the trace completes._
     6. _The ratsnest line between U1 and R1 disappears._
     Resolution: 1280×720 at 30fps.
-->
<video controls width="100%">
  <source src="../../img/pcb/routing-trace.webm" type="video/webm">
  <source src="../../img/pcb/routing-trace.mp4" type="video/mp4">
  Your browser does not support the video tag.
</video>

---

## Collision and Clearance Checks

WireFrame checks clearance in real time during routing:

| Check | Against |
|---|---|
| Trace-to-trace | Other traces on the same layer (width + clearance) |
| Trace-to-pad | Footprint pads on the same layer |
| Trace-to-via/hole | Via and hole drill areas |
| Trace-to-outline | Board edge (Edge.Cuts) |
| Trace-to-zone | Copper zone boundaries |

Routing helpers:

- **Red warning indicator** appears if the route gets too close to another copper element.
- The system prevents completing segments that violate clearance rules.

<!-- TODO: Replace with actual screenshot
     Capture a routing scenario with collision feedback:
     - _A trace being routed between two pads._
     - _The trace approaching another existing trace on the same layer._
     - _A **red highlight or warning indicator** appearing at the point where clearance is violated._
     - _The cursor position showing the collision zone._
     Suggested size: 600×400px.
-->

[//]: # (![Routing Collision]&#40;../img/pcb/routing-collision.png&#41;)

---

## Editing Existing Traces

| Operation | How | Command |
|---|---|---|
| **Move entire trace** | Select + drag | An undoable move command |
| **Drag a segment** | Click and drag one segment | Keeps adjacent segments constrained |
| **Delete trace** | Select + ++delete++ | Delete command (marks net dirty) |

!!! info "Net rebuild"
    Deleting or modifying traces marks the affected nets as dirty. The ratsnest is automatically recomputed to show any broken connections.

---

## Vias and Layer Changes

### During routing

1. While routing on **F.Cu**, press ++v++.
2. A **via** is placed at the current cursor position.
3. The active routing layer switches to **B.Cu**.
4. Continue routing on the new layer from the via point.

### Via properties

| Property | Description | Default |
|---|---|---|
| `id` | Unique via ID | Auto-generated |
| `position` | Board coordinates | Cursor position |
| `netName` | Net inherited from connected trace | Same as trace |
| `diameter` | Via copper diameter | From Design Rules |
| `drill` | Drill hole diameter | From Design Rules |

### Manual via placement

1. Select the **Draw Via** tool.
2. Click on the board to place a via.
3. Assign the net in the Properties panel if needed.

---

## Mechanical Holes

Use the **Place Hole** tool to add non-electrical holes:

1. Click on the board to place a hole.
2. Set parameters in the Properties panel:

| Property | Description |
|---|---|
| `diameter` | Hole diameter (e.g., 3.2 mm for M3 screws) |
| `plated` | Whether the hole has copper plating |
| `netName` | Net name if plated (e.g., GND for grounding) |

<!-- TODO: Replace with actual screenshot
     Capture a board section showing:
     - _Several **vias** along a routed trace, connecting F.Cu to B.Cu (visible as circles with drill markers)._
     - _Four **mounting holes** at the board corners (larger diameter, non-plated)._
     - _Vias showing their net coloring (same color as the connected trace)._
     - _The board outline (Edge.Cuts) visible at the edges._
     Suggested size: 600×400px.
-->
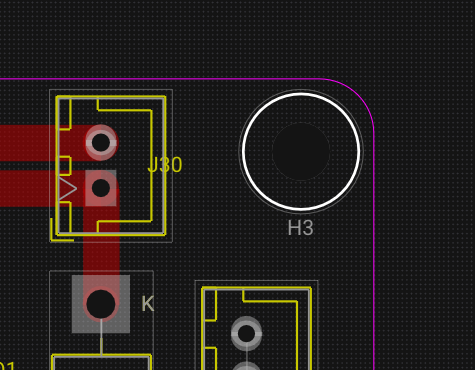
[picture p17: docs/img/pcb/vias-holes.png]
Vias Holes


---

## Sticky Endpoints and Advanced Dragging

WireFrame maintains smart connections during drag operations:

- **Moving a via**: traces attached to the via remain connected — endpoints follow the via position.
- **Moving a footprint**: connected trace endpoints adjust to maintain pad connections via trace endpoint update.
- **StickyEndpoint** structures ensure trace endpoints stay snapped to pads or vias during selection moves.

---

## Autorouting Helpers

WireFrame provides several routing assistance functions:

| Function | Description |
|---|---|
| `calculate45DegreeRoute` | Generates clean 45° path between start and end points |
| `applyMitering` | Rounds corners with mitering arcs |
| `glossTrace` | Simplifies trace geometry by removing redundant vertices and smoothing short zig-zags |

<!-- TODO: Replace with actual video
     Record a 10-second clip:
     1. _A routed trace with some jagged corners and short zig-zag segments._
     2. _Apply the "Gloss" action (via menu or shortcut)._
     3. _The trace simplifies — corners become clean 45° bends, redundant vertices disappear._
     Resolution: 1280×720 at 30fps.
-->

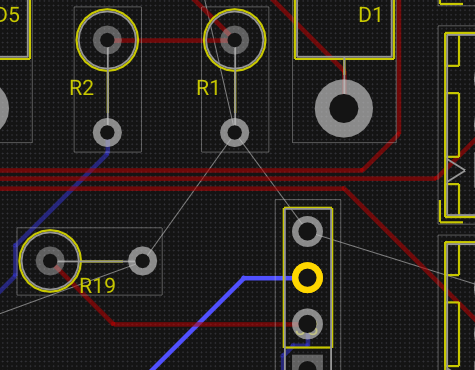
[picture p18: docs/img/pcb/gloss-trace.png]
Gloss-trace


[//]: # (`<video controls width="100%">)

[//]: # (  <source src="../../img/pcb/gloss-trace.webm" type="video/webm">)

[//]: # (  <source src="../../img/pcb/gloss-trace.mp4" type="video/mp4">)

[//]: # (  Your browser does not support the video tag.)

[//]: # (</video>`)

---

## See Also

- [Footprints & Placement](footprints-and-placement.md) — place the footprints that traces connect.
- [Layers & Views](layers-and-views.md) — manage layer visibility during routing.
- [Zones & Planes](zones-and-planes.md) — copper fills that interact with traces.
- [DFM & DRC](dfm-and-drc.md) — check trace clearances and widths after routing.

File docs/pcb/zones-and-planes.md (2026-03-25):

# Zones and Copper Planes

Copper zones (fills/pours) cover board areas with copper, typically for ground planes or power distribution. Zones are managed by the zone engine.

---

## Basic Concepts

A a copper zone includes:

| Property | Description |
|---|---|
| `id` | Unique zone identifier |
| `netName` | Assigned net (e.g., `GND`, `VCC`) |
| `layerId` | Copper layer (e.g., F.Cu, B.Cu) |
| `priority` | Higher-priority zones override lower ones where they overlap |
| `outline` | User-drawn polygon defining the zone boundary |
| `cutouts` | Shapes excluded from the fill (circles, rectangles, capsules) |
| `minClearance` | Minimum clearance from pads and traces |

### Computed output

After fill computation, each zone contains **islands**:

| Structure | Description |
|---|---|
| Outer boundary | Outer polygon of the filled copper area |
| Internal holes | Hole polygons inside the island (clearance areas) |

---

## Creating a Zone

### Manual zone creation

1. Select a copper layer (e.g., **F.Cu**) as the active layer.
2. Use the **Draw Polygon** tool to draw a closed polygon.
3. Assign zone properties:
    - **Net name** (e.g., `GND`).
    - **Clearance** (e.g., 8 mil).
    - **Priority** (default: 0).
4. WireFrame computes the filled copper islands.

### Quick ground plane

Use **Tools → Fill GND Plane** (or equivalent menu action):

1. WireFrame infers the board outline from Edge.Cuts geometry.
2. Generates a GND zone covering the entire board interior.
3. Clearances are computed around all pads and traces.

<!-- TODO: Replace with actual screenshot
     Capture a zone being created or just after creation:
     - _The zone polygon outline visible on F.Cu (dashed or highlighted border)._
     - _The zone assigned to "GND" net (visible in Properties panel or as text on the zone)._
     - _Inside the zone: filled copper area with clearance gaps around pads of other nets._
     - _Thermal connections visible on GND pads (spoke-style connections)._
     Suggested size: 700×500px.
-->
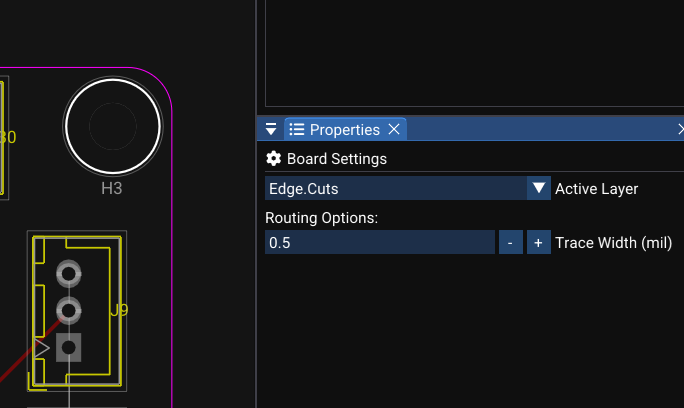
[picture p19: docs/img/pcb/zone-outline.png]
Zone Outline


---

## Zone Fill Computation

WireFrame uses the **Clipper2** library for polygon boolean operations:

### Process

1. Convert zone outline points to Clipper `Path64` with scaling.
2. Apply **boolean subtraction** for:
    - Clearances around pads and traces of **different** nets.
    - User-defined cutouts.
    - Other zones with higher priority.
3. Convert results back to zone island structures.

### Rendered result

- Filled islands are drawn as **semi-transparent polygons** on the PCB canvas.
- Clearance gaps appear around non-matching pads and traces.
- Same-net pads connect to the zone (with thermal relief, when supported).

!!! info "Performance"
    Zone fill computation can be intensive for complex boards with many pads and traces. The fill is rebuilt when you explicitly trigger it or when relevant objects change.

---

## Ground Plane from Board Outline

the ground plane fill feature automates ground plane creation:

1. Infers board outline geometry from:
    - Closed polygons on Edge.Cuts.
    - Board boundary settings.
2. Creates a GND zone covering the entire board interior.
3. Uses the zone engine to compute islands.

From the user's perspective:

- Click **"Fill GND Plane"** → the board fills with copper.
- All non-GND pads show clearance gaps.
- GND pads have thermal connections (spokes).

<!-- TODO: Replace with actual video
     Record a 15-second clip:
     1. _A PCB with placed footprints and routed traces, but no copper fill._
     2. _Click "Tools → Fill GND Plane" from the menu._
     3. _The board fills with a semi-transparent copper overlay on the active layer._
     4. _Zoom in to show clearance gaps around non-GND pads._
     5. _Show thermal connections (spokes) on a GND pad if visible._
     Resolution: 1280×720 at 30fps.
-->
<video controls width="100%">
  <source src="../../img/pcb/fill-gnd-plane.mp4" type="video/mp4">
  Your browser does not support the video tag.
</video>

---

## Zone Interaction with Nets

the PCB netlist engine integrates zones into the connectivity graph:

| Rule | Description |
|---|---|
| Same-net pads | Pads touching a same-net zone are treated as connected |
| Same-net traces | Traces entering the zone area connect to the net |
| Different-net pads | Clearance gap is maintained around the pad |
| Different-net traces | Clearance gap is maintained around the trace |

zone membership testing tests if a location is inside a same-net copper area — useful for routing constraints and DFM checks.

---

## Zone Properties and Editing

| Property | Editable | Description |
|---|---|---|
| Net name | Yes | Assign which net the zone belongs to |
| Layer | Yes | Which copper layer the zone fills |
| Priority | Yes | Higher values override lower priority zones |
| Clearance | Yes | Minimum gap from other-net copper |
| Outline | Yes | Drag vertices to reshape the zone boundary |
| Cutouts | Yes | Add shapes to exclude from the fill |

!!! tip "Zone priority"
    Use priority to create nested zones — for example, a VCC island inside a GND plane. The VCC zone should have a higher priority number than the GND zone.

---

## See Also

- [Routing](routing.md) — traces interact with zone clearances.
- [DFM & DRC](dfm-and-drc.md) — zone connectivity is checked during DRC.
- [Layers & Views](layers-and-views.md) — zone visibility follows layer settings.

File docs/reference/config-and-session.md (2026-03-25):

# Configuration and Session Storage

WireFrame stores user configuration and session data in a JSON file via the configuration system. This page documents file locations, session behavior, and how to reset configuration.

---

## Config File Location

| OS | Path |
|---|---|
| **Linux** | `~/.config/wireframe/user_config.json` |
| **Windows** | `%APPDATA%\WireFrame\user_config.json` |
| **macOS** | `~/Library/Application Support/WireFrame/user_config.json` |

WireFrame ensures the directory exists and creates the file if it doesn't already exist.

---

## Config File Structure

The config file is a JSON document with the following sections:

```json
{
  "auth": {
    "email": "user@example.com",
    "token": "abc123...",
    "activated": true
  },
  "session": {
    "openProjects": [
      "/home/user/Projects/MyBoard.prjxml"
    ],
    "openDocs": [
      "/home/user/Projects/main.schxml",
      "/home/user/Projects/board.pcbxml"
    ]
  }
}
```

### Sections

| Section | Description |
|---|---|
| `auth` | Authentication data (email, activation token, activation status) |
| `session` | Session restoration data (open projects and documents) |

---

## Session Data

Session data tracks:

| Field | Type | Description |
|---|---|---|
| `openProjects` | Array of strings | Paths to project files (`.prjxml`) open during last session |
| `openDocuments` | Array of strings | Paths to schematic/PCB files (`.schxml`, `.pcbxml`) open during last session |

### Startup behavior

1. WireFrame reads the config file.
2. WireFrame reopens listed projects (if files still exist on disk).
3. the document manager reopens listed documents.
4. The **Project Structure** and **Editor** tabs are re-populated.

### Automatic saving

The config is updated automatically when:

- You **open or close** a project or document.
- You **log in or out** (auth data changes).
- The app is **closed normally** (session snapshot).

<!-- TODO: Replace with actual screenshot
     Capture the config file opened in a text editor (VS Code, Sublime, or terminal `cat` output):
     - _The JSON content with `auth` and `session` sections visible._
     - _The `openProjects` array showing 1–2 project paths._
     - _The `openDocs` array showing 2–3 document paths._
     - _Syntax highlighting for JSON._
     Suggested size: 600×400px.
-->

[//]: # (![Config Json]&#40;../img/reference/config-json.png&#41;)

---

## Resetting Configuration

### Clear authentication

| Method | Steps |
|---|---|
| **In-app** | Use "Log out" or "Deactivate" action (if available in Help or Tools menu) |
| **Manual** | Delete the config file or remove the `"auth"` section |

### Reset layout and session

| Method | Steps |
|---|---|
| **Delete config** | Remove `user_config.json` — the app recreates it with defaults on next launch |
| **Delete ImGui config** | Remove `imgui.ini` in the working directory to reset panel layout |

### Reset everything

```bash
# Linux
rm ~/.config/wireframe/user_config.json
rm imgui.ini  # if present in the app directory

# Windows (PowerShell)
Remove-Item "$env:APPDATA\WireFrame\user_config.json"
Remove-Item imgui.ini
```

!!! warning "Data loss"
    Deleting the config file removes all saved session data and authentication. You will need to sign in again and reopen your projects.

---

## See Also

- [Installation](../installation.md) — first launch and activation.
- [Projects & Files](../projects.md) — project and document management.
- [FAQ & Troubleshooting](../faq.md) — common config-related issues.

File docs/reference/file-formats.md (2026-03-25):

# File Formats

WireFrame uses several custom XML-based file formats alongside standard industry formats. This page documents all file types and their structure.

---

## Overview

| Format | Extension | Purpose |
|---|---|---|
| Project | `.prjxml` | Links schematics, PCBs, and libraries |
| Schematic | `.schxml` | Circuit design with components, wires, graphics |
| PCB | `.pcbxml` | Board layout with footprints, traces, zones |
| Symbol library | `.kicad_sym` | KiCad symbol definitions (native support) |
| Footprint library | `.kicad_mod` | KiCad footprint definitions (native support) |
| Gerber | `.gbr` | PCB fabrication layers (export) |
| Drill | `.drl` | Via and hole data (export) |
| BOM | `.csv` | Bill of Materials (export) |
| PDF | `.pdf` | Schematic documentation (export) |

### Importable formats from other EDA tools

| Format | Extension | Source |
|---|---|---|
| KiCad project | `.kicad_pro`, `.pro` | KiCad 5/6/7/8 |
| KiCad schematic | `.kicad_sch` | KiCad 6/7/8 |
| KiCad PCB | `.kicad_pcb` | KiCad 6/7/8 |
| Altium project | `.PrjPcb` | Altium Designer |
| Altium schematic | `.SchDoc` | Altium Designer |
| Altium PCB | `.PcbDoc` | Altium Designer |
| Altium symbol library | `.SchLib`, `.IntLib` | Altium Designer |
| Altium footprint library | `.PcbLib` | Altium Designer |
| Eagle schematic | `.sch` | Eagle / Autodesk (XML, v6+) |
| Eagle board | `.brd` | Eagle / Autodesk (XML, v6+) |
| Eagle library | `.lbr` | Eagle / Autodesk (XML, v6+) |

---

## Project Files (`.prjxml`)

XML structure:

```xml
<WireFrameProject>
  <Settings>
    <LibFolder>lib</LibFolder>
    <!-- additional project-wide settings -->
  </Settings>
  <Schematics>
    <File>relative/path/to/schematic1.schxml</File>
    <File>relative/path/to/schematic2.schxml</File>
  </Schematics>
  <PCBs>
    <File>relative/path/to/board1.pcbxml</File>
  </PCBs>
  <Libraries>
    <Library>path/to/symbol-lib.kicad_sym</Library>
    <Library>path/to/footprint-lib.kicad_mod</Library>
  </Libraries>
</WireFrameProject>
```

| Element | Description |
|---|---|
| `<Settings>` | Project-wide configuration (library folder, etc.) |
| `<Schematics>` | List of schematic file paths (relative to project root) |
| `<PCBs>` | List of PCB file paths (relative to project root) |
| `<Libraries>` | Library file paths used by the project |

!!! info "Path convention"
    Paths are typically **relative** to the project root directory (parent of the `.prjxml` file). This keeps projects portable.

---

## Schematic Files (`.schxml`)

the schematic save function handle:

| Content | Elements |
|---|---|
| **Components** | placed component entries with ID, symbol reference, position, rotation, pin positions, attributes |
| **Wires** | `Wire` lists with `points` (vertices) and `pinAttachments` (component pin references) |
| **Graphics** | Lines, rectangles, circles, arcs, polygons, junctions, harnesses |
| **Page settings** | Paper size, title block (title, company, revision, date, author), border colors |

!!! warning "Hand-editing"
    The XML schema is internal and may evolve between versions. Avoid manual editing unless necessary — use the application UI instead.

---

## PCB Files (`.pcbxml`)

the PCB save function handle:

| Content | Elements |
|---|---|
| **Footprints** | Positions, rotations, layers, pad definitions, graphics, 3D model params |
| **Traces** | Geometry (polyline points), net names, layers, widths |
| **Vias** | Position, net, diameter, drill |
| **Holes** | Position, diameter, plated flag, net |
| **Layers** | Definitions with visibility and color settings |
| **Netlist** | Net names and their pin sets |
| **Zones** | Outlines, cutouts, computed islands |
| **Design rules** | Net class definitions and assignments |
| **Graphics** | Board outline, dimensions, silkscreen, fab layer content |

PCB XML may also embed references to library files for footprints and 3D models.

---

## Library Files

### Symbol libraries (`.kicad_sym`)

WireFrame reads KiCad v6/v7/v8 format symbol files:

- S-expression based format.
- Parsed by the KiCad symbol parser.
- Contains symbol definitions with pins, graphics, texts, and properties.

### Footprint libraries (`.kicad_mod`)

WireFrame reads and writes KiCad footprint files:

- S-expression based format.
- Parsed by the KiCad footprint parser.
- Contains pad definitions, graphics, reference text, and 3D model references.
- `saveToKicadMod` exports generated footprints back to this format.

!!! tip "KiCad compatibility"
    WireFrame maintains compatibility with KiCad structures to enable easy reuse of existing libraries and smoother data interchange.

---

## Manufacturing Files

### Gerber (`.gbr`)

| Property | Value |
|---|---|
| Format | RS-274X |
| Units | Millimeters |
| Coordinate format | 4.4 (integer.decimal) |
| One file per layer | F.Cu, B.Cu, F.SilkS, F.Mask, B.Mask, Edge.Cuts, etc. |

Generated by the Gerber export engine.

### Drill (`.drl`)

| Property | Value |
|---|---|
| Format | Excellon NC |
| Content | Via and hole coordinates with drill diameters |
| Separation | Plated and non-plated holes in separate files (or sections) |

### BOM (`.csv`)

| Column | Description |
|---|---|
| Designator | Component reference (R1, C1, U1) |
| Value | Electrical value (10kΩ, 100nF) |
| Footprint | Package name (R_0603, LQFP-48) |
| Layer | Board side (Top / Bottom) |

Simple comma-separated format. Generated by the BOM export engine.

---

## PDF Export

| Property | Value |
|---|---|
| Content | Schematic pages with components, wires, graphics, title block |
| Format | Vector-based PDF |
| Colors | Converted to black/grey for printing |
| Units | Schematic world units → PDF points (mm → pt) |
| Pages | Single or multi-page depending on design |

Generated by the PDF export engine.

---

## See Also

- [Projects & Files](../projects.md) — how projects organize documents.
- [Fabrication & Export](../pcb/fabrication-and-export.md) — export workflows for Gerber, drill, BOM.
- [Config & Session](config-and-session.md) — user configuration file format.

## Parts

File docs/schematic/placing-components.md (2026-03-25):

# Placing Components (Symbols)

Components in the schematic are instances of library symbols. This page covers loading libraries, placing symbols, editing properties, and manipulating components.

---

## Loading Symbol Libraries

Before placing components, you need to load at least one symbol library:

1. Ensure a **schematic document** is active (the Library panel shows symbol mode).
2. In the **Library panel**, click **Load Symbols…**
3. Select one or more KiCad symbol files (`.kicad_sym`).
4. Libraries are parsed **asynchronously** in the background.
5. Once parsing completes, available symbol names appear in the list.

While loading:

- The panel shows a **spinner** or "Loading…" status message.
- Any parsing errors are listed in the **Logger** after completion.

<!-- TODO: Replace with actual screenshot
     Capture the Library panel during and after symbol loading:
     - _**During loading**: The panel showing a status line like "Loading: Parsing resistors.kicad_sym…" with a spinner icon._
     - _**After loading**: The panel showing a full list of symbol names (e.g., "R", "C", "LED", "MCU_STM32F103") with the search filter empty and a status line reading "Ready — 150 symbols loaded"._
     Capture both states as separate screenshots if possible. Suggested size: 280×400px each.
-->

[//]: # (![Symbol Loading]&#40;../img/schematic/symbol-loading.png&#41;)

!!! tip "Search filter"
    Use the search box at the top of the Library panel to filter symbols. Type partial names like `STM32`, `R_06`, or `LED` to narrow results quickly.

---

## Placing a Symbol from the Library

1. In the **Library panel**, type a filter to find your component.
2. **Double-click** a symbol name (e.g., `R_0603`, `MCU_STM32`, `C_0805`).
3. The schematic canvas enters **component placement mode**:
    - The symbol silhouette is attached to the mouse cursor.
    - A semi-transparent preview follows the mouse, snapping to the grid.
4. **Left-click** to place the symbol at the current grid position.
5. The component is placed and you return to **Select** mode.

Each placed symbol becomes a a placed component with:

| Property | Example | Description |
|---|---|---|
| `id` (Designator) | `R1`, `U3` | Unique identifier, auto-assigned or editable |
| `value` | `10kΩ`, `100nF` | Component value |
| `type` | `R`, `C`, `MCU` | Symbol type name |
| Footprint | `R_0603_1608Metric` | Associated PCB footprint |
| Pin list | Pin 1, Pin 2 | Pin positions, names, and numbers |

<!-- TODO: Replace with actual video
     Record a 15-second screen capture showing:
     1. _Typing "R" in the Library panel search box — the list filters to show resistor symbols._
     2. _Double-clicking "R" — a resistor symbol appears attached to the cursor._
     3. _Moving the mouse over the schematic canvas — the symbol preview follows._
     4. _Left-clicking to place the resistor on the grid._
     5. _The newly placed resistor visible with its designator "R1" shown._
     Resolution: 1280×720 at 30fps.
-->
<video controls width="100%">
  <source src="../../img/schematic/placing-component.mp4" type="video/mp4">
  Your browser does not support the video tag.
</video>

---

## Assigning / Changing Designators and Values

After placing a component, select it to edit its properties:

1. **Click** the component to select it.
2. The **Properties panel** shows editable fields:

| Field | Command used | Description |
|---|---|---|
| **Designator** | an undoable command | Unique ID (e.g., R1 → R2). Updates all references. |
| **Value** | an undoable command | Electrical value (e.g., 10kΩ, 100nF) |
| **Comment** | an undoable command | Additional notes |
| **Footprint** | Direct property edit | PCB footprint name for this component |

All changes are **undoable** — press ++ctrl+z++ to revert any property edit.

!!! info "Designator ID remapping"
    Changing a component's designator (e.g., `U1` → `U3`) automatically updates:

    - The component's ID in the component registry.
    - All wire attachments pointing to the old ID.
    - Selection sets referencing the component.

<!-- TODO: Replace with actual screenshot
     Capture the Properties panel with a resistor selected:
     - _The panel showing: **Designator** field with "R1", **Value** field with "10kΩ", **Comment** field (empty), **Footprint** field with "R_0603_1608Metric"._
     - _Rotation and position fields visible below._
     - _Text attribute controls: designator visibility toggle, font size slider._
     - _The selected resistor highlighted with a cyan outline on the canvas in the background._
     Suggested size: 350×500px.
-->
Component Properties

---

## Rotating Components

With one or more components selected:

- Press ++r++ (default shortcut) or use the **context menu → Rotate**.
- WireFrame:
    - Updates the component's rotation angle (90° increments by default).
    - Automatically adjusts connected wires to stay attached to the (now rotated) pin positions.

Rotation is fully **undoable and redoable**.

<!-- TODO: Replace with actual video
     Record a 10-second clip:
     1. _Select a component (e.g., an IC with multiple pins and connected wires)._
     2. _Press R to rotate it 90° — the component rotates and connected wires adjust their endpoints._
     3. _Press R again for another 90° rotation._
     4. _Press Ctrl+Z twice to undo both rotations — the component and wires return to their original positions._
     Resolution: 1280×720 at 30fps.
-->
<video controls width="100%">
  <source src="../../img/schematic/rotate-component.mp4" type="video/mp4">
  Your browser does not support the video tag.
</video>

---

## Moving Components

1. **Select** one or more components (click or box-select).
2. **Click and drag** to move them on the canvas.
3. Connected wires update in real time to maintain pin attachment.

On mouse release:

- A an undoable move command is created, capturing:
    - Initial and final positions of all moved components.
    - Initial and final wire geometries.
- **Undo** restores everything (components + wires) to the exact previous state.

<!-- TODO: Replace with actual video
     Record a 15-second clip:
     1. _Draw a selection box around 3 components (e.g., two resistors and a capacitor) with connected wires._
     2. _Drag the selection to a new position — wires bend and follow._
     3. _Release the mouse — components settle at new positions._
     4. _Press Ctrl+Z — all components and wires snap back to the original positions._
     Resolution: 1280×720 at 30fps.
-->
<video controls width="100%">
  <source src="../../img/schematic/move-components.mp4" type="video/mp4">
  Your browser does not support the video tag.
</video>

---

## Deleting Components

1. Select components (individually or via selection box).
2. Press ++delete++ or use **context menu → Delete**.
3. A Undo-supported command:
    - Removes selected components by ID.
    - Removes selected wires.
    - Stores full copies for undo.

**Undo** (++ctrl+z++) restores deleted components and wires to the schematic.

---

## Copy, Cut, Paste

The schematic supports structured clipboard operations:

| Operation | Shortcut | Behavior |
|---|---|---|
| **Copy** | ++ctrl+c++ | Copies selected components and wires with relative positions and pin attachments |
| **Cut** | ++ctrl+x++ | Copies then deletes the selection |
| **Paste** | ++ctrl+v++ | Places copies at the mouse position, reassigning component IDs and reattaching wires |

During paste:

- New component IDs are generated (e.g., R1 → R5) to avoid conflicts.
- Wire pin attachments are remapped from original to new component IDs.
- The pasted group follows the mouse until you click to place it.

See [Advanced Editing](../advanced/selection-and-editing.md) for more on selection and clipboard behavior.

---

## See Also

- [Wiring & Nets](wiring-and-nets.md) — connect your placed components.
- [Properties & Attributes](properties-and-attributes.md) — edit component and page properties in detail.
- [Symbol Libraries](../libraries/symbols-library.md) — managing and creating symbol libraries.

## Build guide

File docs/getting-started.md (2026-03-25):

# Getting Started

This page walks you through your first session with WireFrame EDA:

1. Launching WireFrame.
2. Understanding the main layout.
3. Creating your first project.
4. Creating schematic and PCB files.
5. Opening existing files.

!!! abstract "Time estimate"
    Following this guide takes approximately **10 minutes**. By the end, you'll have an empty project ready for schematic design.

<!-- TODO: Replace with actual screenshot
     Capture a full-window screenshot of WireFrame immediately after launching (post-activation). The screenshot should clearly show:
     - _**Menu bar** at the very top with all menus visible (File, Edit, View, Project, Tools, Help)._
     - _**Project Structure** panel on the left side — either empty or showing "No project open"._
     - _**Central editor area** — empty docking space with a grey/dark background and grid pattern._
     - _**Library panel** on the right side — empty or showing "Load Symbols…" prompt._
     - _**Properties panel** below the library (or docked elsewhere) — showing "No selection"._
     Annotate the screenshot with numbered labels (1–5) pointing to each panel. Use arrows or colored boxes. Suggested size: 1280×720px.
-->
Initial Layout

---

## Launching the Application

=== "Linux"

    Run: ./wireframe

    Or launch from your application menu by searching for "WireFrame".

=== "Windows"

    Open **Start Menu** → search for "WireFrame" → press ++enter++.

=== "macOS"

    Open **Launchpad** → find **WireFrame** → click to launch.

On startup, WireFrame:

1. Opens the main application window.
2. Sets up the docking layout with all panels.
3. Restores any previously open projects and documents from your last session (see [Config & Session](reference/config-and-session.md)).

If you see a blank dark window for a brief moment, that is normal — the interface loads on the next frame.

---

## Activation / Sign-In

If activation is required, a full-window overlay dialog appears:

1. Enter your **activation token** or **email + license key**.
2. Click **Activate** (or **Sign In**).
3. Wait for server confirmation — a spinner or progress message is shown.
4. Once activated, the overlay disappears and normal editing is enabled.

<!-- TODO: Replace with actual screenshot
     Capture the activation overlay dialog:
     - _Full-window overlay with a semi-transparent dark background blurring the main UI behind it._
     - _Centered dialog box containing: email input field, license key input field, an Activate button (cyan), and a status line._
     - _If possible, show the "Activation successful" state as a second screenshot._
     Suggested size: 800×500px.
-->
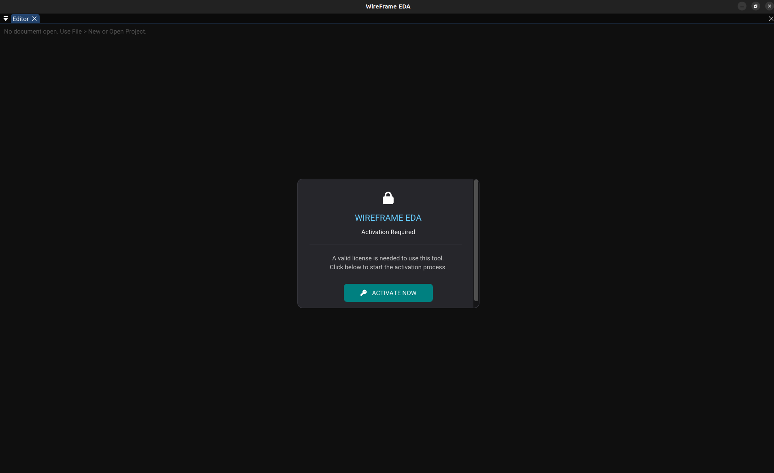
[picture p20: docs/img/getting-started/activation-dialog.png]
Activation Dialog


!!! tip "Resetting activation"
    You can change or reset activation data by removing the user config file. See [Config & Session](reference/config-and-session.md) for the file location on each OS.

---

## Main Layout Concepts

WireFrame uses **ImGui docking**, meaning panels can be freely rearranged by dragging tabs.

### Panel overview

| Panel | Location (default) | Purpose |
|---|---|---|
| **Menu bar** | Top | File, Edit, View, Project, Tools, Help |
| **Project Structure** | Left | Browse projects, schematics and PCBs |
| **Editor** | Center | Tabbed area for open documents (schematic/PCB canvases) |
| **Library** | Right | Lists symbols (schematic) or footprints (PCB) |
| **Properties** | Right (below Library) | Edit properties of selected objects |
| **Layer** (PCB only) | Right or bottom | Toggle and select PCB layers |
| **Logger** | Overlay (bottom) | Transient notifications (info, warnings, errors) |

### Rearranging panels

- **Drag a panel tab** to any edge or corner to dock it in a new position.
- **Float a panel** by dragging it outside the docking area.
- Layout is automatically saved via ImGui configuration and restored on next launch.

<!-- TODO: Replace with actual video
     Record a 15–20 second screen capture showing:
     1. _The user grabbing the Library panel tab and dragging it to the bottom of the window._
     2. _A blue docking preview rectangle appearing to show where the panel will land._
     3. _Releasing the mouse — the Library panel is now docked at the bottom._
     4. _Dragging it back to the right side to restore the default layout._
     Keep mouse movements slow and deliberate. Resolution: 1280×720 at 30fps.
-->

[//]: # (<video controls width="100%">)

[//]: # (  <source src="../img/getting-started/panel-rearrange.webm" type="video/webm">)

[//]: # (  <source src="../img/getting-started/panel-rearrange.mp4" type="video/mp4">)

[//]: # (  Your browser does not support the video tag.)

[//]: # (</video>)

---

## Creating a New Project

1. Open **File → New Project…** from the menu bar.
2. In the dialog, choose a location and filename for the `.prjxml` file:
    - Example: `~/Documents/MyBoard/MyBoard.prjxml`
3. Click **Create** (or **Save**).

WireFrame creates:

- The `.prjxml` project file containing:
    - List of linked schematics.
    - List of linked PCBs.
    - Library folder reference (default: `lib/`).
- A project root folder (if it doesn't already exist).

The **Project Structure** panel immediately shows the new project as a root node.

<!-- TODO: Replace with actual screenshot
     Capture the "New Project" file dialog:
     - _A file-save dialog (native OS or ImGui) showing the file browser._
     - _The filename field populated with a sample name like `MyBoard.prjxml`._
     - _The "Save" or "Create" button highlighted._
     Then capture a second screenshot showing the Project Structure panel with the newly created project node (expanded but empty — no schematics or PCBs yet). Suggested size: 700×450px.
-->
<video controls width="100%">
  <source src="../img/projects/new-project-dialog.mp4" type="video/mp4">
  Your browser does not support the video tag.
</video>
)

!!! info "Project file details"
    For the full specification of `.prjxml` files, see [Projects & Files](projects.md) and [File Formats](reference/file-formats.md).

---

## Creating a New Schematic File

1. With a project open, go to **File → New Schematic**.
2. A new untitled schematic document appears as a tab in the editor:
    - Tab name: `Untitled-SCH-1`.
    - Document type: Schematic.
3. The central canvas shows:
    - A dot grid on a dark background.
    - The **schematic floating toolbar** (centered at top).
    - An A4 page outline (default paper size).

Save it via **File → Save** (++ctrl+s++) or **File → Save As…** to create a `.schxml` file.

<!-- TODO: Replace with actual screenshot
     Capture the editor with a freshly created empty schematic:
     - _The schematic tab visible at the top of the editor area, labeled "Untitled-SCH-1"._
     - _The canvas showing the dot grid and A4 page outline (dashed rectangle)._
     - _The **schematic toolbar** floating at the top-center with tool buttons: Select, Wire, Label, Text, Line, Rect, Circle, Arc, Polygon, Junction, GND, VCC._
     - _All tools deselected except "Select" (default mode)._
     - _The Library panel on the right showing "Load Symbols…" or an empty list._
     Suggested size: 1280×720px.
-->
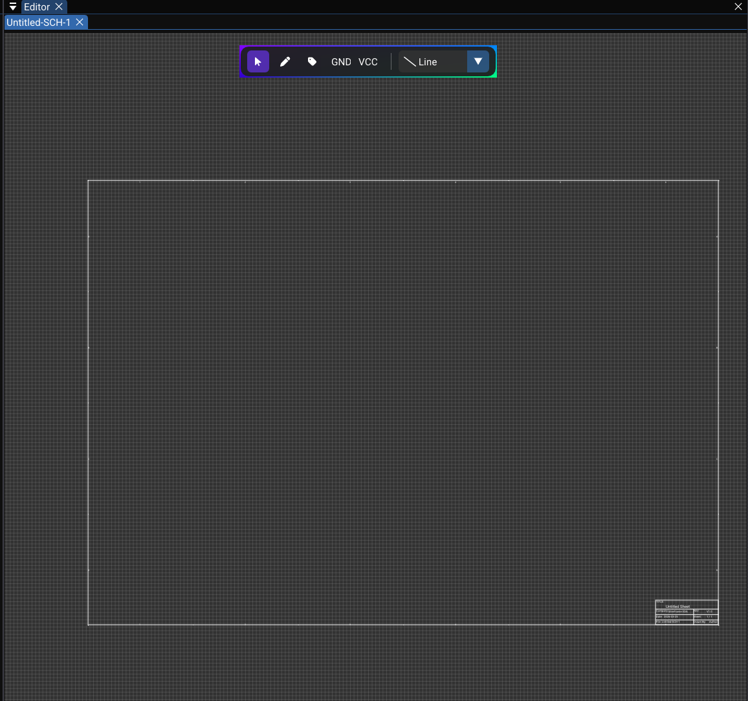
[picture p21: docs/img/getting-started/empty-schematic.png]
Empty Schematic


---

## Creating a New PCB File

1. Go to **File → New PCB**.
2. A new PCB document tab appears:
    - Empty board area with a grid.
    - The **PCB floating toolbar** at the top of the canvas.
    - Default 2-layer stack (F.Cu, B.Cu) plus silkscreen, mask and edge layers.

You can later **convert** a schematic to a PCB to automatically populate footprints and netlist. See [PCB Editor](pcb/index.md) for details.

<!-- TODO: Replace with actual screenshot
     Capture the editor with a freshly created empty PCB:
     - _The PCB tab visible (labeled "Untitled-PCB-1")._
     - _The canvas showing the grid (no footprints, no board outline)._
     - _The **PCB toolbar** floating at top-center with tools: Select, Place Footprint, Route Trace, Draw Via, Place Hole, drawing tools, Measure._
     - _The **Layer panel** visible on the right showing F.Cu (active, highlighted), B.Cu, and other layers._
     Suggested size: 1280×720px.
-->
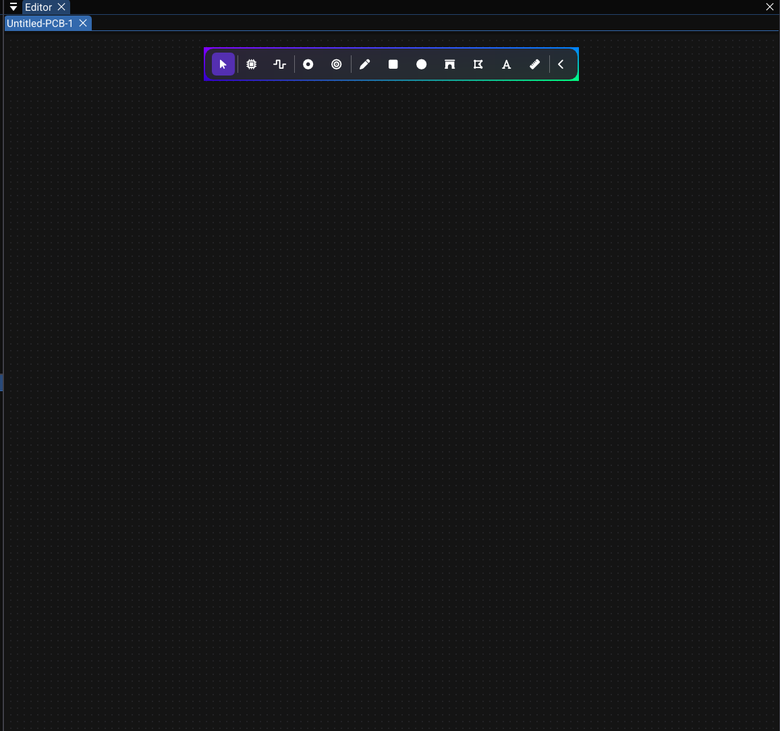
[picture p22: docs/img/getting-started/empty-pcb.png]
Empty Pcb


---

## Opening an Existing Project or File

### Opening a project (`.prjxml`)

1. **File → Open Project…**
2. Select a `.prjxml` file in the file browser.
3. WireFrame loads the project and populates the **Project Structure** panel:
    - All registered schematics appear under a "Schematics" node.
    - All registered PCBs appear under a "PCBs" node.
    - Library references are resolved.
4. Click any schematic or PCB entry in the tree to open it in the editor.

### Opening a single file

1. **File → Open…**
2. Select a `.schxml` (schematic) or `.pcbxml` (PCB) file.
3. The file opens as a document tab in the editor — even if it's not part of a project.

<!-- TODO: Replace with actual screenshot
     Capture the Project Structure panel after opening a sample project:
     - _The project node expanded (e.g., "MyBoard.prjxml")._
     - _Under it: a "Schematics" folder with 1–2 `.schxml` entries._
     - _A "PCBs" folder with 1 `.pcbxml` entry._
     - _One of the schematic files actively open in the editor (its tab visible in the center)._
     Suggested size: 300×400px (panel crop) or 1280×720px (full window).
-->
Project Tree Loaded

---

## Next Steps

You now know how to launch WireFrame, navigate the UI, and create projects and documents.

!!! success "Ready to design"
    Continue to the next pages to deepen your knowledge:

| Next page | What you'll learn |
|---|---|
| [UI Overview](ui-overview.md) | Detailed walkthrough of every panel, toolbar and menu |
| [Schematic Editor](schematic/index.md) | Place components, wire nets, add labels |
| [PCB Editor](pcb/index.md) | Layout footprints, route traces, export Gerbers |
| [Full Tutorial](tutorial/index.md) | Complete end-to-end project walkthrough |

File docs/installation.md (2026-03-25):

# Installation

This page explains how to **download, install, and launch** WireFrame EDA on all supported platforms.

| Platform | Package format | Architecture |
|---|---|---|
| **Windows** | Installer `.exe` | 64-bit (x86_64) |
| **macOS** | Disk image `.dmg` | Apple Silicon (arm64) |
| **Linux** | Debian package `.deb` | 64-bit (x86_64) |

!!! info "End-user guide"
    This page covers **pre-built packages** only. For building from source, see the developer documentation in the repository.

<!-- TODO: Replace with actual screenshot
     Create a simple infographic or flowchart showing the installation path:
     1. _Visit download page (browser window showing the release page)._
     2. _Download the installer for your OS (three icons: Windows logo, Apple logo, Linux penguin)._
     3. _Run the installer (progress bar)._
     4. _Launch and activate (WireFrame splash screen)._
     Use a clean, dark-themed graphic style consistent with the app. Suggested size: 800×200px.
-->
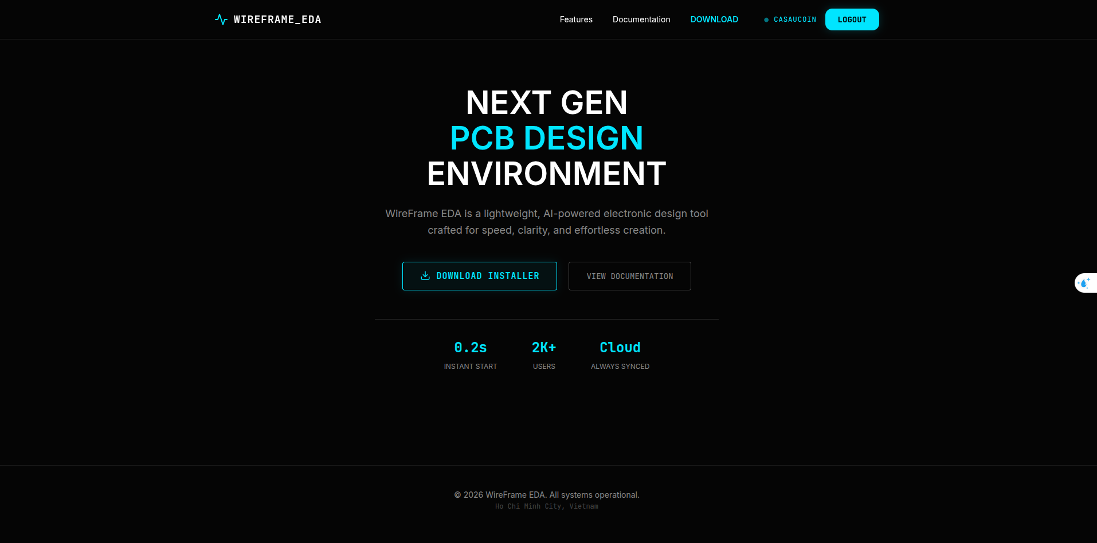
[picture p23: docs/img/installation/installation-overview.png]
Installation Overview


---

## 1. Downloading WireFrame

Go to the official download page:

:material-download: **Download:** `https://wireframe.com.vn/download`

On that page:

1. Choose the **latest stable version** (currently v1.3.7).
2. Select the package that matches your operating system and architecture.

<!-- TODO: Replace with actual screenshot
     Capture the download/release page in a web browser. The screenshot should show:
     - _A list of downloadable files grouped by OS (Windows `.exe`, macOS `.dmg`, Linux `.deb`)._
     - _The latest stable release version highlighted or pinned at the top._
     - _File sizes visible next to each download link._
     - _Browser address bar showing the URL._
-->
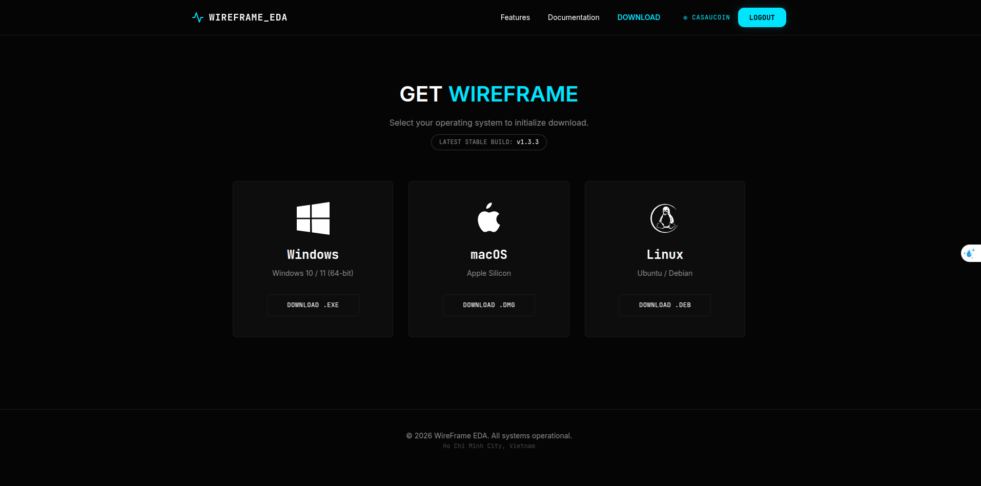
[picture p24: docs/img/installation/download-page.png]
Download Page


---

## 2. Windows Installation

### 2.1 Download the installer

1. On the download page, click the Windows installer link:
    - Example filename: `WireFrame-Setup-1.3.7-Windows-x64.exe`
2. Save the file to a convenient location (e.g., your `Downloads` folder).

### 2.2 Run the installer

1. Double-click the downloaded `.exe` file.
2. If Windows **SmartScreen** shows a warning:
    - Click **More info** → **Run anyway**.

    !!! warning "SmartScreen warning"
        This dialog appears because the installer may not yet be code-signed with an EV certificate. The software is safe to install if you downloaded it from the official source.

3. Follow the setup wizard:
    - **Accept** the license agreement.
    - **Choose** the installation folder (default `C:\Program Files\WireFrame\` is recommended).
    - **Optionally** create a desktop shortcut and Start Menu entry.
4. Click **Install** and wait for the process to finish.
5. Click **Finish** to close the installer.

<!-- TODO: Replace with actual screenshot
     Capture 2–3 key screens of the Windows installer wizard:
     - _Screen 1: License agreement page with the EULA text and "I accept" checkbox._
     - _Screen 2: Installation path selection showing the default folder and a Browse button._
     - _Screen 3: Installation progress bar or the final "Finish" screen._
     Each screenshot should be cropped to the installer window only (no desktop background). Suggested size: 600×450px each.
-->
Windows Installer

### 2.3 Launch the application

Two ways to start WireFrame on Windows:

- **Start Menu**: Open Start → search for "WireFrame" → press ++enter++.
- **Desktop shortcut**: Double-click the WireFrame icon on your desktop.

---

## 3. macOS Installation

### 3.1 Download the disk image

1. On the download page, click the macOS link:
    - Example filename: `WireFrame-1.3.7-macOS.dmg`
2. Save the file (usually to `~/Downloads`).

### 3.2 Install the application

1. Double-click the downloaded `.dmg` to mount it.
2. A Finder window appears showing:
    - The **WireFrame** application icon.
    - A shortcut to the **Applications** folder.
3. **Drag** the WireFrame icon onto the Applications folder.

<!-- TODO: Replace with actual screenshot
     Capture the standard macOS DMG window:
     - _WireFrame app icon on the left side._
     - _Applications folder shortcut on the right side._
     - _A large arrow between them indicating the drag-and-drop action._
     - _The dark macOS window chrome with red/yellow/green traffic lights visible._
     Suggested size: 650×400px.
-->
Macos Dmg

4. Once copied, eject the DMG:
    - Right-click on "WireFrame" in the Finder sidebar → **Eject**.

### 3.3 Clear quarantine attributes (required)

macOS applies quarantine flags to apps downloaded from the internet. You **must** remove them before the first launch:

1. Open **Terminal** (press ++cmd+space++, type "Terminal", press ++enter++).
2. Run:

```bash
sudo xattr -cr /Applications/WireFrame.app
```

3. Enter your macOS password when prompted.

!!! danger "Do not skip this step"
    Without clearing the quarantine attribute, macOS may prevent the application from opening or silently block certain features.

### 3.4 First launch (Gatekeeper)

1. Open **Launchpad** or the **Applications** folder.
2. Find **WireFrame** and click to launch.

If macOS shows a Gatekeeper warning:

> *"WireFrame" cannot be opened because it is from an unidentified developer.*

Resolve it:

1. Open **System Settings → Privacy & Security**.
2. Scroll down and click **Open Anyway** next to the WireFrame entry.
3. Launch WireFrame again and confirm.

<!-- TODO: Replace with actual screenshot
     Capture two screenshots:
     - _Screenshot 1: The Gatekeeper warning dialog saying the app cannot be opened._
     - _Screenshot 2: The macOS System Settings → Privacy & Security page, with the "Open Anyway" button highlighted for WireFrame._
     Suggested size: 600×400px each.
-->
Macos Gatekeeper

---

## 4. Linux Installation

### 4.1 Install the `.deb` package

1. Download `WireFrame-1.3.7-amd64.deb` from the release page.
2. Install via terminal:

```bash
cd ~/Downloads
sudo dpkg -i ./WireFrame-1.3.7-amd64.deb
```

If there are missing dependencies:

```bash
sudo apt-get install -f
```

3. Launch WireFrame:
    - From the **application menu** → search for "WireFrame".
    - Or from terminal: `wireframe`

### 4.2 Runtime requirements

The pre-built binary requires:

| Requirement | Details |
|---|---|
| Architecture | 64-bit x86_64 |
| OpenGL | 3.3+ with hardware acceleration |
| Desktop environment | GTK / Qt runtime libraries (usually pre-installed) |
| Distros tested | Ubuntu 22.04+, Fedora 38+, Debian 12+ |

!!! tip "Wayland users"
    If you experience rendering issues under Wayland, try launching with the X11 backend: `GDK_BACKEND=x11 wireframe`

---

## 5. First Launch and Activation

On first start, WireFrame displays an **activation overlay**:

1. Enter your **account email** and **license key** (or activation token).
2. Click **Sign In** or **Activate**.
3. Wait for the server to confirm — a spinner or status message is shown.
4. Once activated, the overlay disappears and the full editor is available.

<!-- TODO: Replace with actual screenshot
     Capture the activation overlay:
     - _The overlay should cover the full window with a semi-transparent dark background._
     - _In the center: a dialog box with fields for **Email** and **License Key**._
     - _Below the fields: a prominent **Activate** or **Sign In** button (cyan accent)._
     - _A status line showing either "Connecting…" or "Activation successful ✓"._
     - _The WireFrame logo or app name visible at the top of the dialog._
     Suggested size: 800×500px.
-->
Activation Screen

!!! info "Resetting activation"
    To log out or reset your activation, delete the configuration file at `~/.config/wireframe/user_config.json` (Linux) or `%APPDATA%\WireFrame\user_config.json` (Windows). See [Config & Session](reference/config-and-session.md) for details.

---

## 6. Verifying the Installation

After launching, verify that everything works:

- [x] The main window opens with the dark ImGui theme.
- [x] The **menu bar** is visible at the top (File, Edit, View, Project, Tools, Help).
- [x] You can open **File → New Schematic** and see an empty schematic canvas.
- [x] You can open **File → New PCB** and see an empty PCB canvas.
- [x] The **Library panel** is visible on the right side.

If any of these fail, check the [FAQ & Troubleshooting](faq.md) page.

---

## 7. Next Steps

You're ready to start designing! Continue with:

| Next page | Description |
|---|---|
| [Getting Started](getting-started.md) | Learn the basic workflow and UI layout |
| [UI Overview](ui-overview.md) | Detailed tour of every panel and toolbar |
| [Full Tutorial](tutorial/index.md) | End-to-end project from install to Gerber export |

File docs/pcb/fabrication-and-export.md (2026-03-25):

# Fabrication and Export

WireFrame exports production-ready files for PCB manufacturing and documentation. This page covers Gerber export, drill files, BOM, schematic PDFs, and the built-in Gerber viewer.

---

## Export Overview

| Export type | Format | Purpose |
|---|---|---|
| **Gerber** | RS-274X `.gbr` | Copper, mask, silk, and outline layers for PCB fabrication |
| **Drill** | Excellon `.drl` | Via and hole positions/diameters |
| **BOM** | CSV `.csv` | Bill of Materials for component ordering |
| **Schematic PDF** | PDF `.pdf` | Printable schematic documentation |

---

## Schematic PDF Export

`PdfExporter::exportSchematic` generates a vector-based PDF from a `SchematicDocument`:

### Content included

| Element | Rendering |
|---|---|
| Components | Outlines, pins, designator and value text |
| Wires and junctions | Black/grey lines and dots |
| Graphics | Rectangles, circles, text annotations |
| Title block | Border, title, company, revision, date |

Colors are converted to **black/grey** for print-friendly output.

### Steps

1. With a schematic active: **File → Export → Schematic PDF…**
2. Choose the output filename.
3. The PDF is written to disk.

<!-- TODO: Replace with actual screenshot
     Capture a generated schematic PDF opened in an external PDF viewer (e.g., browser or Acrobat):
     - _A full schematic page with components, wires, labels, and annotations rendered in black._
     - _The title block visible at the bottom-right with Title, Company, Revision, Date fields filled._
     - _Pin names and numbers visible on an IC symbol._
     - _The page border visible._
     Suggested size: 800×600px.
-->
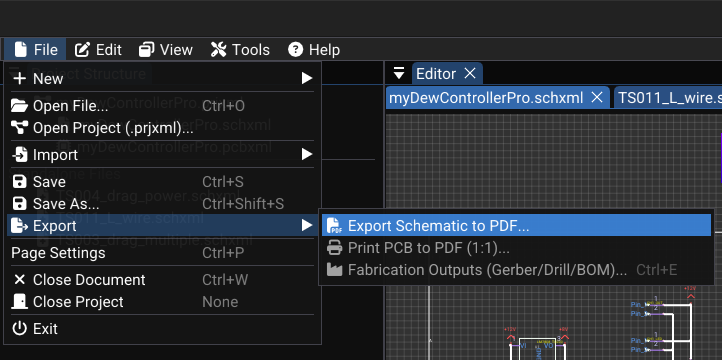
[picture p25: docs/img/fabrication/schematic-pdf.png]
Schematic Pdf


---

## PCB Gerber Export

WireFrame generates RS-274X Gerber files — the industry standard for PCB fabrication data.

### What is exported per layer

| Element | Gerber representation |
|---|---|
| Traces | Stroked paths with round-capped ends, width in mm |
| Pads | Circular pads as flashes; rectangular/oval as drawn shapes |
| Zones | Filled polygons with optional holes |
| Board outline | Edge.Cuts layer as outlines |

### Export workflow

1. From a PCB document: **File → Export → Gerber…** (or open the **Fabrication** dialog).
2. Select which layers to export:

| Layer | Typical filename |
|---|---|
| F.Cu | `MyBoard-F_Cu.gbr` |
| B.Cu | `MyBoard-B_Cu.gbr` |
| F.SilkS | `MyBoard-F_SilkS.gbr` |
| F.Mask | `MyBoard-F_Mask.gbr` |
| B.Mask | `MyBoard-B_Mask.gbr` |
| Edge.Cuts | `MyBoard-Edge_Cuts.gbr` |

3. Choose the output directory.
4. Click **Export** — one `.gbr` file is generated per selected layer.
5. Optionally compress outputs into a **ZIP** for the manufacturer.

<!-- TODO: Replace with actual screenshot
     Capture the Fabrication/Gerber export dialog:
     - _A list of available layers with checkboxes (F.Cu ✓, B.Cu ✓, F.SilkS ✓, Edge.Cuts ✓, others unchecked)._
     - _An output directory field with a Browse button._
     - _An "Export" button (cyan accent)._
     - _After export: a status message or file list showing the generated `.gbr` files with file sizes._
     Suggested size: 600×400px.
-->
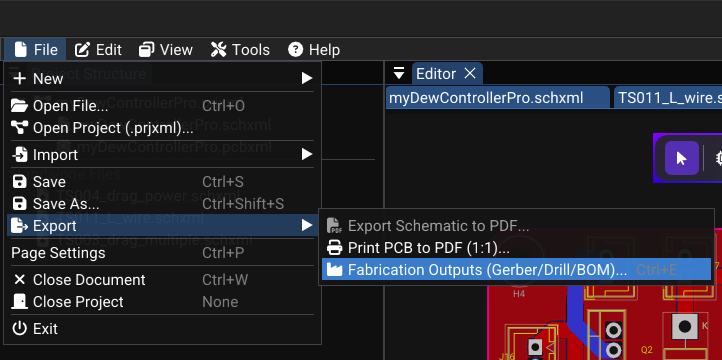
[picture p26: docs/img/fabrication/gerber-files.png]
Gerber Files


---

## Drill and NC Files

Drill files contain via and hole data for CNC drilling:

| Content | Description |
|---|---|
| Via positions | X, Y coordinates for each via |
| Hole positions | X, Y coordinates for each hole |
| Diameters | Drill tool sizes |
| Plating | Plated vs. non-plated hole separation |

Format: Excellon NC drill (text-based coordinate format).

---

## BOM (Bill of Materials)

WireFrame produces a CSV file from placed footprints:

### Columns

| Column | Description | Example |
|---|---|---|
| Designator | Component reference | R1, R2, U1 |
| Value | Component value | 10kΩ, 100nF, STM32F103 |
| Footprint | Package name | R_0603, LQFP-48 |
| Layer | Board side | Top / Bottom |

### Steps

1. From the Fabrication dialog or **File → Export → BOM…**
2. Choose the output `.csv` filename.
3. Open in a spreadsheet application for ordering or documentation.

!!! info "BOM content"
    Only footprints with a **non-empty Value** property are included. Ensure all components have values assigned before exporting.

<!-- TODO: Replace with actual screenshot
     Capture the generated BOM CSV opened in a spreadsheet application (LibreOffice Calc, Excel, or Google Sheets):
     - _Four columns visible: Designator, Value, Footprint, Layer._
     - _5–10 rows of data (e.g., R1/10kΩ/R_0603/Top, C1/100nF/C_0402/Top, U1/STM32F103/LQFP-48/Top)._
     - _Column headers in bold or with a distinct background._
     Suggested size: 600×350px.
-->
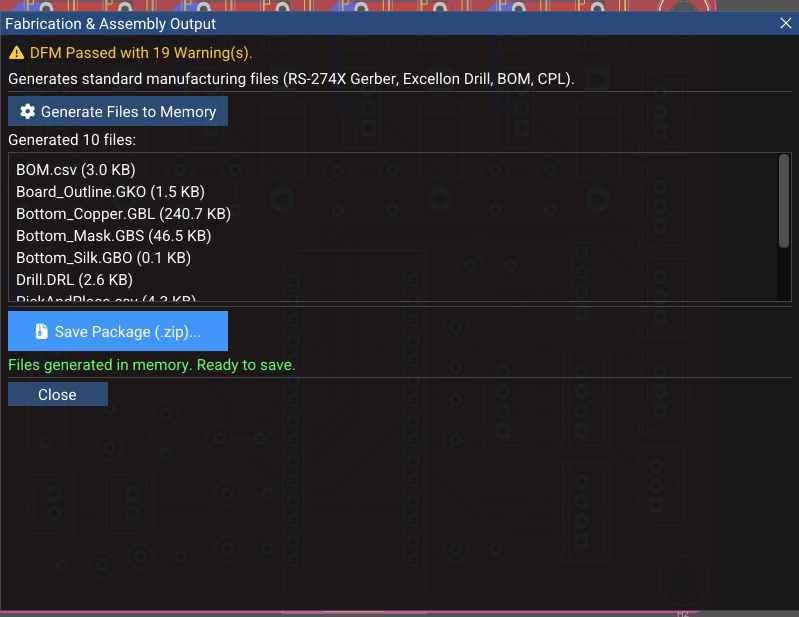
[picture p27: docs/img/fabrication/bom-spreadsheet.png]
Bom Spreadsheet


---

## Gerber Viewer

`GerberViewerDialog` is a built-in viewer for inspecting exported Gerber files without external software.

### Features

| Feature | Description |
|---|---|
| Parse Gerber commands | Reads a subset of RS-274X commands |
| Display traces/lines | Drawn with configured thickness |
| Display flashes (pads) | Shown as small circles/shapes |
| Pan and zoom | Navigate within the preview canvas |

### Usage

1. **Tools → Gerber Viewer** from the menu.
2. Open a generated `.gbr` file.
3. Pan and zoom to inspect:
    - Trace continuity.
    - Pad alignment.
    - Board outline integrity.

<!-- TODO: Replace with actual video
     Record a 15-second clip:
     1. _Open the Gerber Viewer dialog._
     2. _Load a generated F.Cu Gerber file._
     3. _The viewer renders the copper layer — traces and pads visible._
     4. _Pan to a dense area (e.g., QFP IC pads)._
     5. _Zoom in to verify pad spacing and trace routing._
     Resolution: 1280×720 at 30fps.
-->

[//]: # (<video controls width="100%">)

[//]: # (  <source src="../../img/fabrication/gerber-viewer.webm" type="video/webm">)

[//]: # (  <source src="../../img/fabrication/gerber-viewer.mp4" type="video/mp4">)

[//]: # (  Your browser does not support the video tag.)

[//]: # (</video>)

---

## See Also

- [DFM & DRC](dfm-and-drc.md) — run checks before exporting.
- [Layers & Views](layers-and-views.md) — layer selection for export.
- [File Formats](../reference/file-formats.md) — detailed format specifications.

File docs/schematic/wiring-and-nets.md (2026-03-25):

# Wiring and Nets

Wiring connects component pins into electrical nets. This page covers wire drawing, pin attachment, net labels, power symbols, and netlist management.

---

## Wire Drawing Mode

Select the **Wire** tool from the schematic toolbar (or press ++w++).

### Drawing a wire

1. **Click** on a component pin tip (or any point on the canvas) to start a wire.
2. A temporary wire follows the mouse — wires are drawn **orthogonally** (horizontal/vertical segments).
3. **Left-click** to add each vertex (corner point).
4. **Right-click** or press ++esc++ to end the current wire.

| Action | Input |
|---|---|
| Start wire | Click on pin or canvas |
| Add vertex | Left-click |
| End wire | Right-click or ++esc++ |
| Cancel wire | ++esc++ (before first vertex) |

When starting from a pin:

- WireFrame snaps the first vertex to the pin tip in world coordinates.
- The first vertex is automatically attached to that pin internally.

<!-- TODO: Replace with actual video
     Record a 20-second screen capture showing:
     1. _Press W to activate the Wire tool (toolbar button highlights)._
     2. _Click on Pin 1 of a resistor — a wire starts from the pin tip._
     3. _Move the mouse — the wire follows orthogonally with a right-angle preview._
     4. _Click to add a vertex (corner)._
     5. _Click on Pin 1 of another resistor — the wire terminates and attaches to the destination pin._
     6. _A junction dot appears if the wire intersects an existing wire._
     Resolution: 1280×720 at 30fps.
-->
<video controls width="100%">
  <source src="../../img/schematic/wire-drawing.webm" type="video/webm">
  <source src="../../img/schematic/wire-drawing.mp4" type="video/mp4">
  Your browser does not support the video tag.
</video>

---

## Connecting to Pins and Existing Wires

When you click to finish a wire on:

### Another pin

- The final vertex **snaps** to the pin tip position.
- `pinAttachments` records the component ID and pin number for both endpoints.
- The two pins are now on the same net.

### An existing wire vertex or segment

- The new wire shares that vertex position.
- WireFrame visually merges them at the connection point.
- WireFrame treats them as a **single net** — all connected wires and pins belong to the same net.

<!-- TODO: Replace with actual screenshot
     Capture a schematic area showing wire connections:
     - _A wire running from Pin 1 of component R1 to Pin 3 of component U1 — both endpoints visually touching the pin tips._
     - _A second wire branching from the middle of the first wire to another component — a **junction dot** (filled circle) visible at the branch point._
     - _A third wire connecting two pins that are close together, showing clean orthogonal routing._
     - _Zoom in enough to see the pin tips and junction clearly._
     Suggested size: 600×400px.
-->

[//]: # (![Wire Attachment]&#40;../img/schematic/wire-attachment.png&#41;)

---

## Wire Geometry and Editing

Each `Wire` stores:

| Property | Type | Description |
|---|---|---|
| `id` | String | Unique wire ID |
| `points` | List of coordinates | Ordered vertices in world coordinates |
| `pinAttachments` | Map (index → pin) | Which vertices attach to which component pins |
| `netName` | String (optional) | Explicit net name (from labels) |

### Editing operations

| Operation | How | Command |
|---|---|---|
| **Move vertex** | Drag a wire vertex (small hit radius) | Undo-supported command |
| **Drag segment** | Click and drag a segment between vertices | Inserts two new vertices, allows orthogonal adjustment |
| **Simplify** | Automatic | auto-simplification removes collinear redundant vertices |
| **Delete wire** | Select + ++delete++ | Undo-supported command |

!!! info "Wire auto-simplification"
    After dragging a segment, auto-simplification automatically removes unnecessary vertices that are collinear, keeping the wire geometry clean.

<!-- TODO: Replace with actual video
     Record a 15-second clip:
     1. _Drag a single wire vertex to a new position — the adjacent segments adjust._
     2. _Drag a wire segment (between two vertices) — two new vertices are created and the segment moves orthogonally._
     3. _Release the mouse — redundant vertices are removed automatically._
     4. _Undo to restore the original wire shape._
     Resolution: 1280×720 at 30fps.
-->

[//]: # (<video controls width="100%">)

[//]: # (  <source src="../../img/schematic/wire-editing.webm" type="video/webm">)

[//]: # (  <source src="../../img/schematic/wire-editing.mp4" type="video/mp4">)

[//]: # (  Your browser does not support the video tag.)

[//]: # (</video>)

---

## Junctions

Junction dots indicate where **three or more** wire connections meet at a single point:

- WireFrame automatically counts wire vertex and pin occurrences at each position.
- If a point has **connectivity ≥ 3**, a filled junction circle is drawn.
- You can also manually place junction dots using the **Junction** tool.

Without a junction, two crossing wires are treated as **not connected** (they simply overlap visually).

---

## Net Labels and Power Symbols

### Net labels

1. Press ++l++ or select the **Label** tool.
2. Click on the canvas to place a `NetLabel` component.
3. Edit its **Value** in the Properties panel (e.g., `SDA`, `SCL`, `+5V`, `RESET`).
4. All wires connected to that label's pin share the **same net name**.

### Power symbols

| Symbol | Toolbar mode | Description |
|---|---|---|
| **GND** | `PlacingGND` (press ++g++) | Ground reference — single-pin component |
| **VCC** | `PlacingVCC` | Positive power rail — single-pin component |
| **VDD** | Via library | Additional power symbols available in `Component_Library` |

Power symbols are simplified components with a single pin at the origin. They implicitly assign net names to connected wires.

!!! tip "Consistent naming"
    Use the same label value everywhere a net should be connected. For example, all `+3V3` labels will merge into a single net, even if they are on different parts of the schematic sheet.

<!-- TODO: Replace with actual screenshot
     Capture a schematic section showing net naming:
     - _Two or three **net labels** placed on different wires, all showing the same name (e.g., "+3V3") — indicating they belong to the same net._
     - _A **GND** symbol connected to the bottom of a capacitor._
     - _A **VCC** symbol connected to the top of a voltage regulator._
     - _All net names visible as text next to the label symbols._
     - _If possible, show the same net name appearing in two separate locations on the schematic to demonstrate connectivity across distance._
     Suggested size: 700×400px.
-->
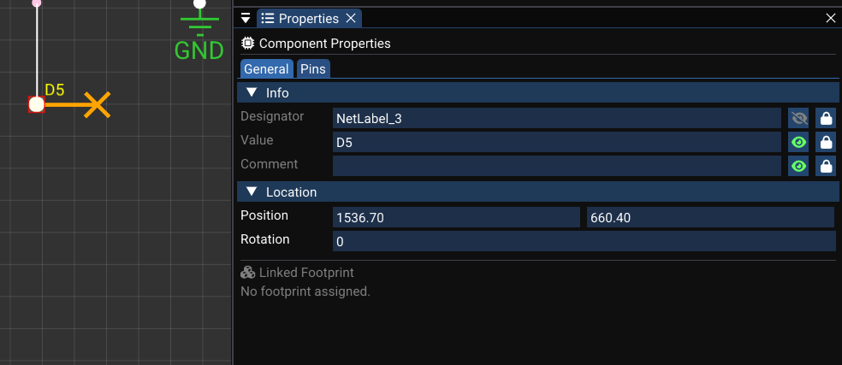
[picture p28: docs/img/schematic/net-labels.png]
Net Labels


---

## Schematic Netlist

WireFrame constructs a net graph from all wires, pins, and labels:

### Algorithm

1. Group all wires that share vertices into **clusters**.
2. Collect all pins attached to each cluster.
3. Determine net name by priority:
    1. **Net labels** and power symbols with user-defined values (highest priority).
    2. **Pin-based default names** (e.g., `Net_U1_1`).
    3. **Generic wire-based names** (e.g., `Net_Wire_42`) as fallback.

### Result

The netlist produces a map:

```
netName → SchNet { name, set<PinRef(componentId, pinNumber)> }
```

This netlist is used for:

- **Net highlighting** on the schematic canvas.
- **PCB netlist generation** during schematic-to-PCB conversion.
- **DRC consistency checks** between schematic and PCB.

---

## Net Highlighting

When you select a net label or a wire:

- WireFrame draws all wires, pins, and labels on that net in a **distinct highlight color**.
- This helps you trace connectivity across complex schematics.

<!-- TODO: Replace with actual video
     Record a 10-second clip:
     1. _Click on a net label (e.g., "SDA") on the schematic._
     2. _All wires connected to the SDA net light up with a bright highlight color (e.g., yellow or orange overlay)._
     3. _Pins on the SDA net also show the highlight._
     4. _Click on empty space to deselect — the highlight fades._
     Resolution: 1280×720 at 30fps.
-->
<video controls width="100%">
  <source src="../../img/schematic/net-highlight.webm" type="video/webm">
  <source src="../../img/schematic/net-highlight.mp4" type="video/mp4">
  Your browser does not support the video tag.
</video>

---

## See Also

- [Placing Components](placing-components.md) — place the symbols that wires connect.
- [Properties & Attributes](properties-and-attributes.md) — edit net names and component values.
- [PCB Editor](../pcb/index.md) — the netlist generated here drives PCB routing.

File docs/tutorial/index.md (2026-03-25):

# Tutorial: Design a Simple LED Circuit

This step-by-step tutorial walks you through the complete WireFrame workflow — from creating a project to exporting Gerber files — using a **simple LED circuit** with a resistor and a connector.

**What you will build:** A basic single-layer PCB with one LED, one current-limiting resistor, and a 2-pin connector — fully routed and ready for fabrication.

<!-- TODO: Replace with actual screenshot
     Capture the finished PCB board showing the three components (LED, resistor, 2-pin connector) routed with traces on one layer. Show both the 2D PCB view and, if possible, the 3D viewer side by side. Suggested size: 900×400px.
-->
Final Result

---

## What You Will Learn

- [x] Create a project and load libraries
- [x] Place components and wire them in the schematic editor
- [x] Convert the schematic to a PCB
- [x] Place footprints and define the board outline
- [x] Route traces and add a ground plane
- [x] Run DFM checks
- [x] Export Gerber and BOM files

---

## Prerequisites

| Requirement | Details |
|---|---|
| **WireFrame** | Installed and activated ([Installation guide](../installation.md)) |
| **Libraries** | At least one KiCad symbol (`.kicad_sym`) and footprint (`.kicad_mod`) library containing R, LED, and Conn_01x02 |

!!! tip "Don't have libraries?"
    You can download free KiCad libraries from [https://www.kicad.org/libraries/](https://www.kicad.org/libraries/) — WireFrame loads them natively.

---

## Step 1 — Create a Project

1. Launch WireFrame.
2. Go to **File → New Project…**
3. Choose a folder and name it `LED_Board.prjxml`.
4. Click **Create**.

The **Project Structure** panel now shows your empty project.

<!-- TODO: Replace with actual screenshot
     Capture the Project Structure panel showing "LED_Board.prjxml" expanded but empty — no schematics or PCBs yet. Suggested size: 300×200px.
-->
Step1 New Project

!!! tip "Importing from other EDA tools"
    Already have a design in KiCad, Altium, or Eagle? Use **File → Import** instead. See [Projects & Files — Importing](../projects.md#importing-projects-from-other-eda-tools) for details.

---

## Step 2 — Load Libraries

### Load symbol libraries

1. Go to **File → New Schematic** to create a schematic document.
2. In the **Library** panel (right side), click **Load Symbols…**
3. Select your `.kicad_sym` file(s) containing `R`, `LED`, and `Conn_01x02`.
4. Wait for parsing — symbol names appear in the list.

### Load footprint libraries

1. Go to **File → New PCB** to create a PCB document.
2. In the **Library** panel, click **Load Footprints…**
3. Select your `.kicad_mod` file(s) containing `R_0805`, `LED_0805`, and `PinHeader_1x02`.
4. Footprint names appear in the list.

<!-- TODO: Replace with actual screenshot
     Capture the Library panel with symbols loaded, showing a search filter with "LED" typed and the matching symbol highlighted. Suggested size: 280×350px.
-->
Step2 Libraries

---

## Step 3 — Draw the Schematic

Switch to the schematic tab (click the schematic tab at the top of the editor).

### 3.1 Place the components

| Component | How to find it | Designator |
|---|---|---|
| **Resistor** | Search `R` in Library panel → double-click | R1 |
| **LED** | Search `LED` → double-click | D1 |
| **Connector** | Search `Conn_01x02` → double-click | J1 |

For each component:

1. Double-click its name in the Library panel.
2. Move the mouse to position it on the schematic.
3. Press ++r++ to rotate if needed.
4. **Left-click** to place.

Arrange them roughly like this:

```
    J1           R1           D1
  ┌─────┐     ┌─────┐     ┌─────┐
  │  1 ─┼─────┼─ 1 2┼─────┼─A  K┼───┐
  │  2 ─┼──┐  └─────┘     └─────┘   │
  └─────┘  │                         │
           └─────────────────────────┘
```

<!-- TODO: Replace with actual video
     Record a 20-second clip:
     1. _Type "R" in the Library search box._
     2. _Double-click "R" — a resistor appears on the cursor._
     3. _Click to place it on the schematic._
     4. _Repeat for "LED" and "Conn_01x02"._
     5. _The three components are visible on the canvas._
     Resolution: 1280×720 at 30fps.
-->
<video controls width="100%">
  <source src="../../img/tutorial/step3-place-components.webm" type="video/webm">
  <source src="../../img/tutorial/step3-place-components.mp4" type="video/mp4">
  Your browser does not support the video tag.
</video>

### 3.2 Edit component properties

Click each component and set its properties in the **Properties** panel:

| Component | Designator | Value | Footprint |
|---|---|---|---|
| Resistor | `R1` | `330Ω` | `R_0805_2012Metric` |
| LED | `D1` | `Red` | `LED_0805_2012Metric` |
| Connector | `J1` | `Power` | `PinHeader_1x02_P2.54mm_Vertical` |

<!-- TODO: Replace with actual screenshot
     Capture the Properties panel with R1 selected, showing Designator = "R1", Value = "330Ω", Footprint = "R_0805_2012Metric". Suggested size: 300×350px.
-->
Step3 Properties

### 3.3 Wire the circuit

1. Press ++w++ to activate the **Wire** tool.
2. **Wire 1**: Click on **J1 pin 1** → click on **R1 pin 1**. The wire connects them.
3. **Wire 2**: Click on **R1 pin 2** → click on **D1 anode (A)**. 
4. **Wire 3**: Click on **D1 cathode (K)** → click on **J1 pin 2**. This closes the loop.
5. Press ++esc++ to exit wire mode.

<!-- TODO: Replace with actual video
     Record a 20-second clip:
     1. _Press W — the Wire tool activates._
     2. _Click on J1 pin 1, then click on R1 pin 1 — a wire appears._
     3. _Click on R1 pin 2, then click on D1 anode — second wire._
     4. _Click on D1 cathode, then click on J1 pin 2 — circuit complete._
     5. _Press Esc to deactivate._
     Resolution: 1280×720 at 30fps.
-->
<video controls width="100%">
  <source src="../../img/tutorial/step3-wiring.webm" type="video/webm">
  <source src="../../img/tutorial/step3-wiring.mp4" type="video/mp4">
  Your browser does not support the video tag.
</video>

### 3.4 Save the schematic

Press ++ctrl+s++ and save as `LED_Board.schxml`.

<!-- TODO: Replace with actual screenshot
     Capture the complete schematic showing all three components wired together in a loop: J1 → R1 → D1 → J1. All designators and values visible. Suggested size: 700×400px.
-->
Step3 Complete

---

## Step 4 — Convert Schematic to PCB

1. With the schematic active, go to **Project → Convert to PCB**.
2. A new PCB document opens automatically with:
    - All three footprints loaded (clustered together).
    - Ratsnest lines showing the connections to route.

<!-- TODO: Replace with actual screenshot
     Capture the new PCB showing R1, D1, and J1 footprints clustered together with ratsnest lines connecting their pads. Suggested size: 600×400px.
-->
Step4 Converted

!!! warning "Check footprint assignments"
    If a component shows as "missing footprint", go back to the schematic and verify the Footprint field is set correctly in the Properties panel.

---

## Step 5 — Place Footprints

Spread the footprints out on the board:

1. Select the **Select** tool (default, or press ++esc++).
2. **Click and drag** each footprint to a good position.
3. Press ++r++ to rotate if needed.

Suggested layout:

```
┌────────────────────────┐
│   [J1]    [R1]   [D1]  │
│    ○○     ▫▫     ▫▫    │
└────────────────────────┘
```

| Shortcut | Action |
|---|---|
| Click + drag | Move footprint |
| ++r++ | Rotate 90° |
| ++f++ | Flip to back side |

<!-- TODO: Replace with actual video
     Record a 15-second clip:
     1. _Drag J1 to the left side of the board area._
     2. _Drag R1 to the center._
     3. _Drag D1 to the right._
     4. _Ratsnest lines update in real time as you move._
     Resolution: 1280×720 at 30fps.
-->
<video controls width="100%">
  <source src="../../img/tutorial/step5-placement.webm" type="video/webm">
  <source src="../../img/tutorial/step5-placement.mp4" type="video/mp4">
  Your browser does not support the video tag.
</video>

---

## Step 6 — Define the Board Outline

1. In the **Layer** panel, click **Edge.Cuts** to set it as the active layer.
2. Select the **Draw Rectangle** tool from the toolbar.
3. Click and drag to draw a rectangle around all three footprints.
4. Leave some margin (~50 mil) between footprints and the edge.

<!-- TODO: Replace with actual screenshot
     Capture the board with a magenta rectangle on Edge.Cuts surrounding the three footprints. The rectangle should be slightly larger than the component area. Suggested size: 600×400px.
-->
Step6 Outline

---

## Step 7 — Route Traces

1. Press ++x++ to activate the **Route Trace** tool.
2. Click on **J1 pad 1** to start a trace → route to **R1 pad 1** → click to finish.
3. Click on **R1 pad 2** → route to **D1 anode pad** → click to finish.
4. Click on **D1 cathode pad** → route to **J1 pad 2** → click to finish.

As you complete each trace, the corresponding ratsnest line disappears.

| Action | Input |
|---|---|
| Start / add vertex | Left-click |
| Finish on pad | Left-click on target pad |
| Cancel | Right-click or ++esc++ |

<!-- TODO: Replace with actual video
     Record a 20-second clip:
     1. _Press X — Route Trace tool activates._
     2. _Click J1 pad 1, route to R1 pad 1 — first trace done, ratsnest disappears._
     3. _Click R1 pad 2, route to D1 anode — second trace._
     4. _Click D1 cathode, route to J1 pad 2 — last trace, all ratsnest gone._
     Resolution: 1280×720 at 30fps.
     **📸 Screenshot placeholder — `img/tutorial/step7-routed.png`**
     Capture the fully routed board: three traces connecting the pads, zero ratsnest lines remaining. Traces shown in red (F.Cu). Suggested size: 600×400px.
-->
<video controls width="100%">
  <source src="../../img/tutorial/step7-routing.webm" type="video/webm">
  <source src="../../img/tutorial/step7-routing.mp4" type="video/mp4">
  Your browser does not support the video tag.
</video>

---

## Step 8 — Run DFM Check

1. Go to **Tools → DFM Check**.
2. Click **Run DFM**.
3. Review the results:
    - **0 errors** = ready to export :material-check-circle:{ style="color: green" }
    - If errors appear, double-click each one to zoom to the issue and fix it.

<!-- TODO: Replace with actual screenshot
     Capture the DFM panel showing "0 errors, 0 warnings" or a clean result. If there are issues, show one being fixed. Suggested size: 500×300px.
-->
Step8 Dfm

---

## Step 9 — Export Fabrication Files

### Gerber export

1. Go to **File → Export → Gerber…**
2. Select layers: **F.Cu**, **F.SilkS**, **F.Mask**, **Edge.Cuts**.
3. Choose an output folder.
4. Click **Export**.

### BOM export

1. Go to **File → Export → BOM…**
2. Save as `LED_Board_BOM.csv`.

The BOM contains:

| Designator | Value | Footprint | Layer |
|---|---|---|---|
| R1 | 330Ω | R_0805_2012Metric | Top |
| D1 | Red | LED_0805_2012Metric | Top |
| J1 | Power | PinHeader_1x02_P2.54mm_Vertical | Top |

### Verify with Gerber Viewer

1. Go to **Tools → Gerber Viewer**.
2. Open the generated `F.Cu.gbr` file.
3. Verify traces and pads look correct.

<!-- TODO: Replace with actual video
     Record a 15-second clip:
     1. _Open File → Export → Gerber, select layers, click Export._
     2. _Open Tools → Gerber Viewer, load F.Cu.gbr._
     3. _Pan around to verify the three traces and pads are correct._
     Resolution: 1280×720 at 30fps.
-->
<video controls width="100%">
  <source src="../../img/tutorial/step9-export.webm" type="video/webm">
  <source src="../../img/tutorial/step9-export.mp4" type="video/mp4">
  Your browser does not support the video tag.
</video>

---

## Done! :material-check-decagram:{ style="color: #00E5FF" }

You have completed a full design cycle:

```
Project → Schematic → PCB → Route → DFM → Export
```

| Deliverable | File |
|---|---|
| Project | `LED_Board.prjxml` |
| Schematic | `LED_Board.schxml` |
| PCB | `LED_Board.pcbxml` |
| Gerber files | `F.Cu.gbr`, `F.SilkS.gbr`, `F.Mask.gbr`, `Edge.Cuts.gbr` |
| BOM | `LED_Board_BOM.csv` |

---

## Quick Reference — Shortcuts Used

| Action | Shortcut |
|---|---|
| Save | ++ctrl+s++ |
| Undo | ++ctrl+z++ |
| Place wire | ++w++ |
| Route trace | ++x++ |
| Rotate | ++r++ |
| Flip | ++f++ |
| Cancel / Select | ++esc++ |
| Delete | ++delete++ |

---

## Next Steps

Now that you know the basic workflow, explore more:

| Topic | Link |
|---|---|
| Add net labels and power symbols | [Wiring & Nets](../schematic/wiring-and-nets.md) |
| Multi-layer routing with vias | [Routing](../pcb/routing.md) |
| Add a ground plane | [Zones & Planes](../pcb/zones-and-planes.md) |
| Preview in 3D | [3D Viewer](../advanced/3d-viewer.md) |
| Import KiCad / Altium projects | [Projects & Files](../projects.md#importing-projects-from-other-eda-tools) |
| All keyboard shortcuts | [Shortcuts](../advanced/shortcuts.md) |

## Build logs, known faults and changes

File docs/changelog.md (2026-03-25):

# Changelog

All notable changes to WireFrame EDA are documented here. Versions follow [Semantic Versioning](https://semver.org/).

---

## v1.3.7 — 2026-03-15 (Latest)

### Added
- **Footprint Wizard** — built-in generator for common through-hole and SMD footprints with live preview.
- **Model Alignment Dialog** — interactive 3D model positioning for footprints with real-time preview.
- **Gerber Viewer** — built-in viewer for inspecting exported Gerber files without external software.
- **BOM export** — CSV export with Designator, Value, Footprint, and Layer columns.

### Improved
- 3D Viewer rendering performance — mesh caching reduces reload time by ~80%.
- Zone fill algorithm — better Clipper2 integration for complex polygon operations.
- Trace routing — improved 45° path calculation and mitering.
- DFM/DRC — added component overlap check and board-edge proximity check.

### Fixed
- Fixed crash when loading large KiCad symbol libraries (>500 symbols).
- Fixed wire endpoint detachment when moving components with rotated pins.
- Fixed incorrect net names when multiple NetLabels share the same wire cluster.
- Fixed Gerber export missing board outline when Edge.Cuts uses polygon instead of rectangle.

---

## v1.3.6 — 2026-01-20

### Added
- **Keyboard shortcut editor** (Edit → Keymap) — visual key binding configuration.
- **Schematic PDF export** — vector-based PDF with title block and border.
- **Session restoration** — automatically reopens projects and documents from last session.

### Improved
- Library panel search — now supports partial matching and case-insensitive filtering.
- Properties panel — dynamic content switching based on selection type.
- Undo/Redo — improved command history for multi-object move operations.

### Fixed
- Fixed via placement not inheriting the net from the active trace.
- Fixed copy/paste losing wire-to-pin attachments in schematic.
- Fixed layer color picker not saving custom colors.

---

## v1.3.5 — 2025-11-10

### Added
- **3D Viewer** — initial release with STEP and OBJ model support.
- **Copper zones** — zone fill with Clipper2, priority system, and cutouts.
- **DFM/DRC panel** — full check suite (outline, clearance, drill, orphans, missing components).

### Improved
- PCB routing — added collision detection during trace drawing.
- Footprint flipping — front/back toggle with automatic layer remapping.
- File I/O — faster `.pcbxml` save/load for large boards.

### Fixed
- Fixed schematic page settings not saving custom paper sizes.
- Fixed multi-select drag offset incorrect on first move.
- Fixed drawing primitives (circle, arc) not rendering on non-default layers.

---

## v1.3.0 — 2025-08-01

### Added
- **PCB editor** — initial release with footprint placement, trace routing, and via support.
- **KiCad footprint parser** — load `.kicad_mod` files.
- **Multi-document management** — tabbed editor with schematic and PCB documents.
- **Project management** — `.prjxml` project files linking schematics, PCBs, and libraries.

### Improved
- Schematic editor — added harness tool and junction auto-detection.
- Library manager — async loading with background parsing.

---

## v1.2.0 — 2025-04-15

### Added
- **Schematic editor** — component placement, wiring, net labels, power symbols.
- **KiCad symbol parser** — load `.kicad_sym` files.
- **Drawing tools** — line, rectangle, circle, arc, polygon, text.
- **Undo/Redo** — full command history for all schematic operations.
- **Copy/Cut/Paste** — structured clipboard with component ID remapping.

---

## v1.0.0 — 2025-01-01

### Initial Release
- Basic application framework with ImGui, GLFW, and OpenGL.
- Docking layout with configurable panels.
- File open/save infrastructure.
- Empty editor canvas with pan and zoom.

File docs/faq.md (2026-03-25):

# FAQ & Troubleshooting

Common questions and solutions for WireFrame EDA issues.

---

## Installation Issues

??? question "The application does not start / shows a blank window"
    **Possible causes and solutions:**

    1. **Missing OpenGL driver** — WireFrame requires OpenGL 3.3+. Check your GPU driver:
        - Linux: `glxinfo | grep "OpenGL version"` — should show 3.3 or higher.
        - Windows: Update your GPU drivers from the manufacturer (NVIDIA, AMD, Intel).
    2. **Wayland compatibility** — On Linux with Wayland, try forcing X11:
        ```bash
        GDK_BACKEND=x11 wireframe
        ```
    3. **Missing shared libraries** (Linux) — Install missing dependencies:
        ```bash
        sudo apt-get install -f
        ```
    4. **Corrupted config file** — Delete the config and restart:
        ```bash
        rm ~/.config/wireframe/user_config.json
        ```

??? question "macOS: 'WireFrame cannot be opened because it is from an unidentified developer'"
    This is a **Gatekeeper** restriction. Follow these steps:

    1. Open **Terminal** and run:
        ```bash
        sudo xattr -cr /Applications/WireFrame.app
        ```
    2. Then go to **System Settings → Privacy & Security** and click **Open Anyway**.
    3. Launch WireFrame again — it should open without the warning.

    See [Installation — macOS](installation.md#3-macos-installation) for full details.

??? question "Windows: SmartScreen blocks the installer"
    Windows SmartScreen may flag the installer because it has not yet accumulated enough reputation:

    1. Click **More info** on the SmartScreen dialog.
    2. Click **Run anyway**.
    3. The installer will proceed normally.

    This is expected for new or infrequently downloaded software.

??? question "Linux: `dpkg` fails with dependency errors"
    Run the following after the failed `dpkg` install:
    ```bash
    sudo apt-get install -f
    ```
    This will download and install any missing dependencies, then complete the WireFrame installation.

---

## Activation & Sign-In

??? question "I cannot activate — the server is not responding"
    - Check your **internet connection**.
    - Verify the activation server URL is correct (contact support if needed).
    - If you're behind a **corporate proxy**, ensure the proxy allows HTTPS connections to the activation server.
    - Try again after a few minutes — the server may be temporarily unavailable.

??? question "How do I reset my activation / log out?"
    Delete the configuration file:

    - **Linux**: `~/.config/wireframe/user_config.json`
    - **Windows**: `%APPDATA%\WireFrame\user_config.json`
    - **macOS**: `~/Library/Application Support/WireFrame/user_config.json`

    On next launch, the activation overlay will appear again.

??? question "Can I use WireFrame on multiple computers with one license?"
    Check your license terms. Typically, a single license allows activation on a limited number of devices. Contact support for clarification.

---

## Libraries

??? question "My KiCad symbols / footprints do not load"
    **Common causes:**

    1. **Wrong file format** — WireFrame supports KiCad v6/v7/v8 `.kicad_sym` and `.kicad_mod` files. Older `.lib` and `.mod` formats may have limited support.
    2. **File encoding** — Ensure files are UTF-8 encoded.
    3. **Corrupted files** — Open the library file in a text editor and check for syntax errors.
    4. **Parser errors** — Check the Logger overlay for error messages during loading. They may indicate which symbol/footprint failed to parse.

??? question "How do I create custom footprints?"
    Use the built-in **Footprint Wizard** (**Tools → Footprint Wizard**):

    1. Configure pin count, layout (single, dual, grid, quad), pad size, and pitch.
    2. Preview the generated footprint in real time.
    3. Export to `.kicad_mod` format.

    See [Footprint Libraries](libraries/footprints-library.md#footprint-generator-footprint-wizard) for details.

??? question "How do I link a footprint to a symbol?"
    1. Load both symbol and footprint libraries.
    2. In the Library panel (schematic mode), right-click a symbol.
    3. Choose **Link Footprint** and select the corresponding footprint.
    4. Future instances of that symbol will automatically have the footprint assigned.

    See [Symbol Libraries](libraries/symbols-library.md#linking-footprints-to-symbols).

---

## Schematic Editor

??? question "Wires don't connect to pins — I see no junction dots"
    - Ensure the wire endpoint **exactly touches the pin tip**. Zoom in to verify alignment.
    - Wire snapping is grid-based — if the pin is off-grid, you may need to zoom in and place the wire endpoint manually.
    - Junction dots appear automatically when **three or more** connections meet at one point.

??? question "My net names are wrong or duplicated"
    - Check that **Net Labels** are placed correctly and their values match.
    - The netlist is rebuilt from wires and labels. Use **Properties panel** to verify the net name of a selected wire.
    - Conflicting net names can occur if two different labels are connected by the same wire — review the schematic for overlapping labels.

??? question "Undo/Redo does not work as expected"
    - Some operations (like loading libraries) are not undoable — they are immediate.
    - If undo seems stuck, check the **Logger** for error messages.
    - As a workaround, reload the file from disk (**File → Open** the same file).

---

## PCB Editor

??? question "Ratsnest lines don't disappear after routing"
    - Ensure the trace **connects exactly to the pad center** at both ends.
    - The ratsnest is recomputed after each routing action. If lines persist, the trace may not be on the correct **layer** or **net**.
    - Check the net assignment in the Properties panel after selecting the trace.

??? question "DFM/DRC shows many clearance errors"
    - Review your **Design Rules** (Tools → Design Rules) — the default clearance may be too tight for your design.
    - Common fixes:
        - Increase minimum clearance.
        - Increase trace width for power nets.
        - Reroute traces that pass too close to pads or other traces.
    - Double-click each violation to zoom to the problem area.

??? question "Zones (copper pours) look incorrect or have gaps"
    - Run **zone fill rebuild** after making changes to traces or footprints.
    - Check zone **priority** — higher priority zones override lower ones.
    - Verify the zone's **net assignment** and **clearance** settings.
    - Gaps around pads are expected (clearance areas) unless the pad is on the same net (thermal connections).

---

## Export & Fabrication

??? question "Gerber export produces empty files"
    - Ensure there is content on the layers you selected for export.
    - Check that the board has a valid **board outline** (Edge.Cuts layer).
    - Verify in the **Gerber Viewer** (Tools → Gerber Viewer) that the generated files contain data.

??? question "BOM CSV is missing components"
    - Only components with a **non-empty Value** property are included in the BOM.
    - Ensure footprints are **placed** on the PCB (not in the "available" list).

??? question "PDF export has wrong colors or missing elements"
    - PDF export converts colors to black/grey for printing. This is by design.
    - If elements are missing, ensure they are on **visible layers** before exporting.

---

## Performance

??? question "The application is slow or laggy"
    **Tips to improve performance:**

    1. **Reduce loaded libraries** — unload libraries you don't need for the current project.
    2. **Simplify zone fills** — complex zones with many cutouts take longer to compute.
    3. **Close unused tabs** — each open document consumes memory.
    4. **Check GPU acceleration** — ensure your system uses hardware OpenGL, not software rendering.
    5. **Reduce window size** — on very high-DPI displays, a smaller window may help.

??? question "3D Viewer is very slow"
    - Loading **STEP files** requires significant computation (mesh tessellation). First load is slow, but subsequent renders use cached meshes.
    - Use simpler 3D models if possible (low polygon count).
    - Close the 3D viewer when not needed to free GPU resources.

---

## Still Need Help?

If your issue is not listed here:

1. Check the [Changelog](changelog.md) for known issues in your version.
2. Search the [GitHub Issues](https://github.com/CaSauCoin/WireFrame_Product/issues) page.
3. Open a new issue with:
    - Your OS and WireFrame version.
    - Steps to reproduce the problem.
    - Any error messages from the Logger.
    - Screenshots if applicable.

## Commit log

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2026-07-28 docs: replace ASCII diagrams with visual flowchart images in documentation and site pages
2026-08-04 docs(agents): point at the wireframe-codebase store
    Agents can now find the shared index, decisions and prior findings via
    `wfc` from anywhere — including a git worktree — instead of scanning
    the repo. See ../wireframe-codebase/AGENTS.md.
2026-10-01 docs: bring the guide up to date with the current WireFrame app
    Checked against the WireFrame source (v1.5.47 line) and rewritten where the
    guide had drifted:
    - new: Copilot command reference (all / commands), datasheets/repairs/project
    memory (/contract, /pins, /fix, /memory), board shape and outline (import
    verdict, SVG + DXF, /board), enclosure fit and multi-board products (Board
    Fit and System tabs, .asmxml)
    - rewritten: AI configuration (Preferences → AI Assistant, OpenRouter and
    agyserve presets, design/fast model tiers); PCB layout with /layout (live
    stages, apply/discard, copper-layer decision, compared options, /topology)
    - corrected: CAD outline import reads DXF with "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
2026-10-01 docs: sample data and per-scene capture config for doc_builder
    - samples/: fictional inputs for the capture scenes, regenerated by
    samples/generate.py (stdlib + pdftoppm): an 80 x 60 mm demo board as DXF and
    SVG (R3 corners, four M3 holes, a battery pocket), the datasheet of a
    fictional 8-pin part WF-DEMO8 (PDF), and its pin table as an image
    - .wf-docs.yaml: 1080p window, the sample files the AI may open, and scenes —
    file inputs for the import/datasheet/OCR briefs, case STEP and drone
    assembly generated by WireFrame's own labs (prepare), deliberate ERC/DRC
    issues created in the app during setup, another project for the
    functional-blocks video, and 10 scenes skipped with the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
2026-10-02 docs: Zone Manager, Performance HUD, and an honest Gerber Viewer section
    Checked against the WireFrame source:
    - zones-and-planes: new Zone Manager section (View → Zone Manager, Shift+B) —
    Fill GND (F.Cu / B.Cu / Both), Fill Net (any layer, inner included),
    Unfill All, Apply (Rebuild All Zones); where a quick zone takes its outline
    (shapes drawn on that copper layer → Edge.Cuts → footprints + 200 mil);
    the zone table (grouped rows, clearance in mil, thermal, Find/Del, undo per
    change). "Quick Ground Plane" rewritten: the fill is computed on Apply, not
    when the zone is created. Video and image capture briefs added.
    - faq: "The canvas feels slow or stutters" — the Perfor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
2026-10-09 docs: app-captured screenshots and videos, redesigned site, learning paths
    - 54 screenshots and videos captured from the WireFrame app by doc_builder
    (docs-fill), inserted at their capture slots; every file traces to its run
    in docs/assets/wf/wf-manifest.json. No mock-ups, English UI only.
    - .wf-docs.yaml: per-scene samples and hints for the capture lab; the four
    installer / download-page slots are skipped (not a WireFrame window).
    - Theme: dark-first design tokens with a light-mode toggle, figure styling,
    tables, admonitions, keyboard keys; image lightbox (mkdocs-glightbox).
    - Production briefs stay in the Markdown (they are the capture scripts) but a
    build hook turns each capture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
2026-10-10 docs: match the guide to the current WireFrame app (AI/PCB/implement)
    Checked page by page against the WireFrame source on the dev line
    (AI/PCB/implement, eada165, v1.5.47) and rewritten where the guide no
    longer matched the app.
    Corrected:
    - Keyboard shortcuts rewritten from Key_Map: rotate is Space (R only with
    a selection on a schematic), net label N, fit Home (schematic only),
    zoom 100% Ctrl+0, zoom to selection Ctrl+Shift+F, PCB layer keys while
    routing; only bindings that have a handler are listed.
    - PCB: vertical toolbar and its real tools; footprints arrive from Update
    Schematic to PCB in a grid and are re-placed by dragging from the
    Footprints panel; Delete unplaces; rout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
2026-10-14 docs: board catalogue and content plan — real open-hardware boards for the guide, blog and videos
    boards.yaml pins each board to a commit (or a subdir of KiCad's demos) with its
    author and licence; doc_builder clones and imports them with WireFrame itself.
    Big boards (Jetson AGX Thor 10 L, Jetson Nano 8 L, CM5 Minima 6 L, One-Air-Max
    4 L) are for showcase videos; small verified ones (buck converter, KLP4e,
    H730duino, hexapod) illustrate the guide.
2026-10-14 docs: real boards instead of the 7805 project — config, schematic overview and ERC
    Default project is now the automotive buck converter; schematic and library
    pages use the KLP4e datalogger, PCB pages the buck converter (H730duino for
    layers and 3D), AI pages the NE555 blinker the Copilot made. The import scene
    takes the buck converter's own KiCad project (board:buck-converter:kicad).
    ERC page: the KLP4e as published (18 errors, 9 warnings, what the first rows
    mean), the fix-and-re-run clip removes the SDA label at U2 (18 -> 19 -> 18),
    and a Pitfalls section on what ERC does not check (power inputs with no
    source).
2026-10-14 docs(schematic): placing and wiring on the KLP4e datalogger
    Place a third 24LC1025 from the project library (it becomes U5); the 16 MHz
    crystal and its 22 pF load capacitors for wires on pins; C5 across Vcc and
    GND beside the battery for power symbols; the junction/crossing frame on the
    catalogue board instead of the copy in WireFrame's test data.
2026-10-14 docs(schematic): graphics, properties and title block on the KLP4e datalogger
    The real-time clock block as its author drew it for annotations, a note and
    a grouping box around the 32.768 kHz crystal, R5 330 -> 470 ohm and back for
    editing values, and the title block whose Title holds ${project_name}.
2026-10-14 docs(advanced): selection and editing on the KLP4e (schematic) and the buck converter (traces)
    The editing page's schematic scenes are ordered before the PCB section in the
    config so its trace scene keeps the buck converter; +5V traces 44 and 46 are
    the clickable ones in the fresh import.
2026-10-14 docs(libraries): Library Manager and editors on the KLP4e datalogger
    Recaptured with the Library Manager showing project-relative and ~/ paths
    instead of the run's temporary folder. The Add library menu and the editor
    tabs moved: Altium library is at y 194, the Symbol/Footprint/3D tabs at y 283.
    R1's footprint is linked in the catalogue import, so the clip now says so.
2026-10-14 docs(pcb): routing, net classes, zones and the main window on the buck converter
    - ratsnest clip: the C10-U1 bootstrap track is deleted, its ratsnest line and
    E02 appear, Route Trace (X) clears both
    - layer change: the LED feed leaves D3 on F.Cu, V drops a via, crosses on B.Cu,
    a second V brings it up to R8; DFM stays clean
    - net classes: a Power class at the 1 mm the author used for the 12 V input,
    /12V_fused assigned to it (13 -> 10 tracks off their class size); the page
    now says that moving a net to another class resizes that net's copper at once
    - zones: the F.Cu GND pour goes from 48 % to 58 % at 10 mil clearance
    - KiCad import scenes take the buck converter's own .kicad_pro
2026-10-14 docs: AI, enclosure, fabrication and DFM pages recaptured without the 7805 project
    - AI slots that used the default project name the NE555 blinker themselves;
    the Design Plan button is matched by its new label
    - enclosure: Board Fit goes through 'The mechanics' first; the System clip
    opens the demo drone with its board projects and reads X1 pin by pin
    (CURR vs CURRENT flagged)
    - fabrication: the redesigned window, revision A, Generate & verify package
    - DFM, board outline, KiCad import on the buck converter
2026-10-14 docs: shortcuts, project structure and preferences recaptured on real boards
    Keyboard Shortcuts opens through open_dialog and filters by its own search
    field; the multi-sheet project tree is the hexapod's (root + eight sheets).
2026-10-14 docs(projects): drop the drawn file-structure illustration
    It was not drawn by WireFrame. The section's text and its update-to-PCB clip
    already say what it showed.
2026-10-14 docs: Copilot commands by panel, the Library Workspace, and how a part is found
    commands.md: what / offers on each panel (planning, schematic, PCB,
    simulation workbench, Library Workspace), each command's purpose, and which
    need no model call; the simulation and library commands were missing.
    library-workspace.md: opening it, what is on screen, saving, the library
    commands. how-parts-are-found.md: the pool and what follows it, the checks
    every candidate passes, confirmed parts, family names, datasheets, the tools
    the Copilot reads the library with, and why it is fast. Media slots to fill.
2026-10-15 docs: media for Copilot commands by panel, the Library Workspace and how a part is found
    The / list on the PCB, in a simulation and in the Library Workspace; /bom,
    /findings and a library /review recorded with no model call; the Library
    Workspace and a BOM card's verdicts. The simulation panel opens on a block
    copied into a .simxml (sheets are not simulated since 1.5.47); a /sim-blocks
    clip was dropped — the SPICE window covers the chat at this frame size.
2026-10-15 docs(site): the WireFrame logo in the header, the home hero and as favicon, instead of a theme glyph
2026-10-15 docs(site): the WireFrame mark inline in the header and the home hero, theme-aware; SVG favicon; WireFrame EDA Docs
2026-10-15 docs(site): stop publishing the old hand-made media in img/ — unused, and several show a personal machine
2026-10-15 docs(media): recapture the shots that showed private paths
    Six captures printed a home folder or a /private/tmp path: the Altium
    import (header path), the import commands, a new project, and the SPICE
    model library root. Recaptured on a build that writes ~/... and names a
    shipped model library instead of its path.
    The SPICE slot follows the .simxml workflow: Simulate a Block of This
    Sheet, a 9 V source on +9V, a transient run, then the Models tab. The
    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
2026-10-15 docs(simulation): a simulation is a file of its own
    Since 1.5.47 the sheets of a design are not simulated. The section said
    to open the panel on a schematic, probe the sheet, and pick blocks of the
    whole schematic. It now starts with getting a simulation (copy a block of
    a sheet, or a new .simxml), and the workbench pages follow that flow on
    the NE555 blinker: a 9 V supply, a 3 s transient, preflight, signals,
    A/B cursors at 0.99 Hz, and a testbench with a 1 kOhm load and a frequency
    check that passes. Seven captures, one new (copying a block).
    Assertions measure the whole record: the page no longer offers a settled
    window the panel does not have; it points to the cursors or a .meas with
    FR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
2026-10-15 docs(home): eight cards with the tasks behind each guide
    The 'What you can do' grid had six cards of one sentence each and an empty
    slot in its last row. It now has eight -- 3D viewer and Enclosure and
    multi-board added -- each with a lead line and four links that go straight
    to the task (place parts, ERC, board outline, length tuning, copy a block
    into a simulation, /fix, Altium conversion, the fabrication package, Board
    Fit...). Four columns on a wide screen, two below, one on a phone: never a
    row with a hole in it.
2026-10-16 docs(ai): placement review, edits back into the plan, /reference; served from wireframe.com.vn/docs
    site_url pointed at guideline-one.vercel.app, a deployment that no longer
    exists, so every page's canonical and the sitemap named a dead site. It is
    now https://wireframe.com.vn/docs/, which the main site serves.
    The banner and changelog say plainly what is public (v1.3.8) and what is in
    beta for the next release.
2026-10-20 Guide: drawn by the website, and every feature documented
    MkDocs is retired: wireframe-auth renders these pages with the site's own
    templates (app/docs_site.py), in the order and with the home page that
    guide.yml gives. The built site/ directory, mkdocs.yml and the Vercel
    config are gone; URLs are unchanged.
    New and rewritten pages for what the app does now: the High-Speed Workbench
    (stack-up, checks and rules, interfaces, simulation, power and EMI, fixes
    and the report), the Power Analyzer, length tuning, side-by-side views and
    cross-probing, multi-board products, models and credit for the AI Copilot,
    accounts and plans, and a glossary. New captures drawn headlessly by the app
    on open-hard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
2026-10-24 docs(plans): no trial — Free is the design tools, the AI Copilot comes with Plus and Pro
2026-10-24 docs(drc): edge per pad on the real shape, slots, co-located holes (W18), pair gap and pad clearance, the board's own severities
2026-10-24 docs(drc): E10 solder mask bridges, W19 custom rules, the board's mask settings
2026-10-26 docs: a KiCad or Altium round trip loses nothing (72 of 72 demo round trips), and design variants
2026-11-01 Guide: "Next release" on what has not shipped, device numbers, two repairs
    Four changes. The trial is deliberately NOT among them: this branch had its
    own removal, and rebasing onto 542584f showed that one was better, so it was
    dropped in favour of it. Mine wrote "Free … the Copilot runs on your own model
    key"; the Free plan has no AI Copilot at all, with or without a key, which is
    what 542584f says. Taking the weaker wording would have replaced one wrong
    sentence about pricing with another. What survives from that pass is the
    website-side test, which now reads this repo's markdown so the guide can never
    be the one surface still offering a trial again — it was, until today, because
    that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
2026-11-02 Guide: pictures on the placement review and import pages
    Both pages had no picture at all.
    Placement review describes the Penalty card in BOM Review and its verdicts;
    it now shows one: an NE555 blinker's review with the BOM cards and their
    verdicts, the NE555's symbol and land, and the card reading PLACE WITH ISSUES
    with "Place with issues (9)". Captured with wf-panel-shot on samples/ne555-blinker.
    Import and export shows a KiCad project imported into WireFrame, the same
    capture the website's import page uses.
2026-11-02 Guide: the tutorial on an LED chaser board — new sample, eight new captures
    The tutorial's three-part LED board becomes a 25-part LED chaser: an NE555
    clock, a 74HC4017 counter and ten LEDs in a ring, on a 50 x 60 mm two-layer
    board. samples/led_chaser.py writes the design input as a KiCad project
    (it checks the drawn wires against its netlist first); WireFrame's importer
    turns it into samples/led-chaser/1-schematic and 2-placed, and the app's
    Auto-route lays 3-routed (no ratsnest, DFM/DRC and ERC clean).
    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
2026-11-02 Guide: the tutorial's ERC video ends on a clean re-run
    Run ERC after an edit no longer aborts the app (WireFrame 1b71f9ff0), so
    "Fix one ERC issue" is captured again with the step it was missing: after
    the missing CLK wire is drawn, Run ERC comes back "ERC clean: nothing to
    report on any sheet."
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2026-11-07 docs: the guide's pictures and clips, recorded on WireFrame 2.0.1
    64 of the guide's 99 captured images and videos are re-shot on the
    2.0.1 capture build (the customer build with its test engine kept),
    signed in as a real account whose name and email are blurred in post.
    37 pages; the AI pages wait for the gateway that serves 2.0.1's prompts.
    Steps that 2.0.1 broke, fixed on the way:
    - 3D Viewer: the view opens as a tab behind the board's; bring it to the
    front (and the caption named a buck converter on the h730duino).
    - DFM & DRC: the panel opens behind Footprints; focus it before Run.
    - ERC: the button is Run ERC (was Run Project-Wide ERC Analysis), in the
    text and in the steps.
    - The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
2026-11-08 Docs: on WireFrame credit, WireFrame AI picks the model — the Copilot shows WireFrame AI and the credit left
    The 2.0.1 app no longer shows a model, a provider or the service's address on
    the plan's credit (WireFrame fix/2.0.1-gateway-ai). Models, Credit and Your
    Data, the AI overview, the Preferences tables and the changelog say so; the
    design/fast model pickers are described for an own key only.
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2026-11-12 Docs: release notes for 2.0.2, 2.0.3 and 2.0.4; 2.0.4 is the current release
    The page still called 2.0.1 the current release and had nothing after it.
    2.0.4 fixes the Windows PDF readers on computers without the Visual C++
    Redistributable; 2.0.3 put a connected agent in command (33 tools, reads
    free) and shipped the PDF readers; 2.0.2 steadied the chat and explained a
    missing graphics driver on Windows.
